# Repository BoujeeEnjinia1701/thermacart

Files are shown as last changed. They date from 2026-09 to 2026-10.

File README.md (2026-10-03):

# ThermaCart

     

**Area:** Shared Components · **TRL:** 3 of 9 (proof of concept on paper) · **Value-engineering target:** $80 USD · **Difficulty:** 2 of 5

A sealed, swappable phase-change thermal cartridge in a few standard temperature ranges (cold chain, comfort and hot holding) that stores heat or cold and drops into coolers, cabinets and heat exchangers.

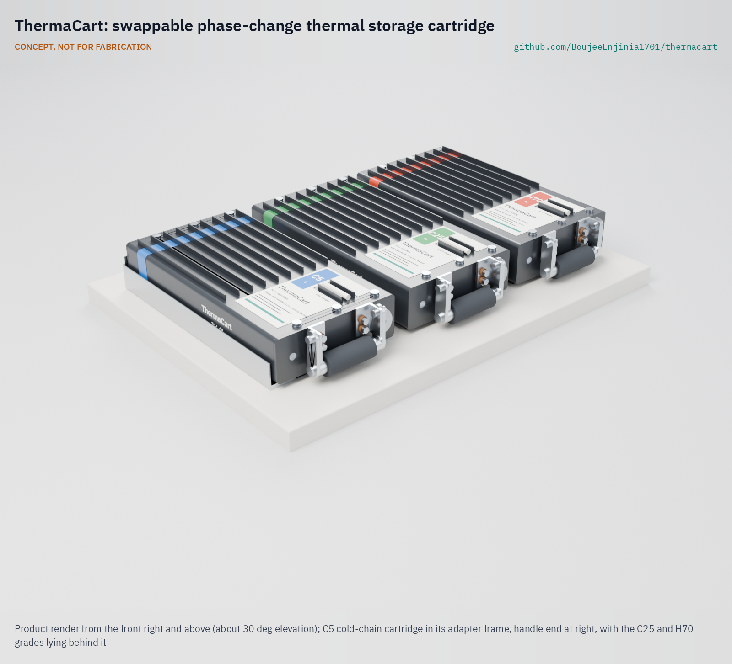
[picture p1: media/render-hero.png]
ThermaCart: swappable phase-change thermal storage cartridge, product render


[Exploded render](media/render-exploded.png) · [Detail render](media/render-detail.png) · [Interactive 3D model](media/viewer.html) · [Concept blueprint (PDF)](media/concept-blueprint.pdf) · [General arrangement (PDF)](cad/drawings/TCT-DWG-001.pdf) · [Prototype build plan](docs/05-build-plan.md) · [Design decisions](docs/06-design-decisions.md) · [Calculations](docs/04-calcs/01-sizing.md) · [Review note](docs/REVIEW.md)

## Concept rationale

A common cartridge format turns thermal storage into a part you choose instead of a subsystem you design, and lets cartridges move between cold boxes, ovens and heat stores. Phase-change material (PCM) holds heat or cold at a nearly constant temperature, so the grade of the fill, not a thermostat, sets the temperature of the box it sits in. Sealing the PCM in a keyed cartridge keeps a messy or combustible material out of users' hands and stops the wrong temperature going into the wrong box.

The design is open and garage-buildable on purpose. The shell is a stock 6 x 2 in aluminium tube with screwed, O-ring-sealed end caps built up from flat plate, so anyone with a drill press and a tap set can make one without milling, and the envelope fits a GN 1/3 gastronorm slot that commercial kitchens already use. Publishing the envelope, key table and fill recipes lets other open projects, including ColdPod and ZeerBox in this portfolio, design around the same cartridge.

## Burning platform

Around 14 % of the world's food, worth about $400 billion a year, is lost between harvest and retail ([FAO and UNEP, 2022](https://www.fao.org/newsroom/detail/FAO-UNEP-agriculture-environment-food-loss-waste-day-2022/en)), much of it spoilage where cooling is missing or unreliable. Cold chains also fail by overcooling: freezing exposure is common in vaccine storage and transport studies, largely because water ice sits at 0 °C or below ([Hanson et al., 2017](https://www.sciencedirect.com/science/article/pii/S0264410X16309471)).

On the hot side, about 2.1 billion people still cook with polluting fuels, and household air pollution caused an estimated 2.9 million deaths in 2021 ([WHO, 2025](https://www.who.int/news-room/fact-sheets/detail/household-air-pollution-and-health)). Demand for cooling is rising fast: UNEP expects installed cooling capacity to triple by 2050, with cooling emissions above 10 % of the global total unless efficiency improves ([UNEP](https://www.unep.org/topics/energy/cooling/about-cooling)). Cheap, portable thermal storage lets heat and cold be made where energy is available and used where it is not.

## Where it could be used

### By industry

| Industry | Use |
| --- | --- |
| Food service and catering | H70 cartridges in insulated GN carriers keep delivered meals hot without gas or mains |
| Fresh produce and dairy logistics | C5 cartridges in coolers on motorbikes, vans and market stalls, recharged overnight in a shared freezer |
| Off-grid refrigeration | A swappable cold store for solar direct-drive fridges and cool boxes instead of built-in ice banks |
| Telecom and electronics enclosures | C25 cartridges buffer daily temperature swings in outdoor cabinets and battery boxes |
| Open hardware and product design | A documented storage block for new cold boxes, warmers and heat stores, so designers size the box, not the storage |

### By country or region

| Country or region | Why it matters there |
| --- | --- |
| India | A 2022 national study put post-harvest losses at 6 to 15 % for fruits and 5 to 12 % for vegetables ([MoFPI, citing NABCONS](https://www.mofpi.gov.in/sites/default/files/_annex_265_au2145_qhinz4.pdf)) |
| Nigeria | About 45 % of food spoils for lack of cold storage, and solar cold rooms such as ColdHubs show the demand for shared cooling ([IFPRI, 2018](https://www.ifpri.org/blog/coldhubs-addressing-crucial-problem-food-loss-nigeria-solar-powered-refrigeration/)) |
| Sub-Saharan Africa (for example Kenya and Tanzania) | About four in five households lack clean cooking ([IEA](https://www.iea.org/reports/universal-access-to-clean-cooking-in-africa/executive-summary)); keeping cooked food hot saves fuel and smoke |
| European Union | About 132 kg of food per person was wasted in 2022, 54 % of it in households ([Eurostat](https://ec.europa.eu/eurostat/web/products-eurostat-news/w/ddn-20240927-2)); kitchens already use GN formats |
| United States | State food codes based on the FDA Food Code require hot food to be held at 57 °C (135 °F) or above ([for example Delaware, § 3-501.16](https://www.law.cornell.edu/regulations/delaware/16-Del-Admin-Code-SS-3-501.16)); caterers and school meal programs need hot holding away from mains |
| United Kingdom | Salt-hydrate heat batteries are already used in homes for hot water ([University of Edinburgh](https://chem.ed.ac.uk/research/research-impact/heat-storage-technology)), showing that sealed PCM storage already sells in high-income markets |

## What sparked the idea

The starting point was the gastronorm pan. In November 1964 the Swiss association for institutional catering (SVG), the Swiss Hotel Association and Swiss makers of commercial kitchen equipment agreed on a kitchen norm built on a basic 530 x 325 mm grid ([SVG, Merkblatt Gastro-Norm](https://svg.ch/merkblatt-gastro-norm/)), and in 1993 the container dimensions were published as the European standard EN 631-1 ([BSI, BS EN 631-1:1993](https://knowledge.bsigroup.com/products/materials-and-articles-in-contact-with-foodstuffs-catering-containers-specification-for-dimensions-of-containers)). Because every pan, oven, trolley and carrier now shares those sizes, kitchens mix equipment from any maker without thinking about it. Thermal storage never got the same treatment: each cold box and food carrier still has its own ice pack or heat pack. ThermaCart asks what a gastronorm for stored heat and cold would look like, so it takes the GN 1/3 footprint as its envelope and adds the missing layer, a small set of keyed temperature grades.

## Problem

Thermal storage is designed from scratch in every cold box, cooker and heat store, and phase-change materials are messy, corrosive or unsafe when handled loose. Water ice is too cold for vaccines and some produce, salt hydrates corrode aluminium, and paraffins burn and can permeate plastics.

Full problem statement: [docs/01-problem.md](docs/01-problem.md)

## Concept

A sealed aluminium cartridge, 323 x 152 x 64 mm, holds 1.10 to 1.18 kg of PCM in one of three grades: C5 (5 °C, cold chain), C25 (25 °C, comfort) and H70 (70 °C, hot holding of cooked food). It fits a GN 1/3 slot, carries by a folding bail, shows its state through a clear melt indicator and locks into an adapter frame whose key accepts only its grade. The shell carries a matte black finish that roughly doubles its heat exchange with the air. The TRL 3 calculations ([TCT-CAL-001](docs/04-calcs/01-sizing.md)) give 65, 61 and 73 Wh of usable storage, 2.9 to 3.0 kg filled and about $83 in parts per cartridge. One H70 cartridge keeps a GN carrier at 63 °C or more for about 13 h. Two C5 cartridges store enough cold for a 25 L cooler for about 9.7 h at 32 °C, but on paper they cannot draw heat out of the cooler air fast enough to hold 2 to 8 °C for more than about 2.4 h; users are told to lay produce directly on the cartridges, which the calculation does not credit. The cold-chain hold time (R10) is not met, and the cost (R16) is over its value-engineering target; see the [review note](docs/REVIEW.md). The design choices were decided by Amish on 2026-09-25 ([TCT-DDR-001](docs/decisions/0001-trl2-review-decisions.md), [TCT-DDR-002](docs/decisions/0002-recommendations-accepted.md)).

Full design precis: [docs/02-concept.md](docs/02-concept.md) · Requirements: [docs/03-requirements.md](docs/03-requirements.md)

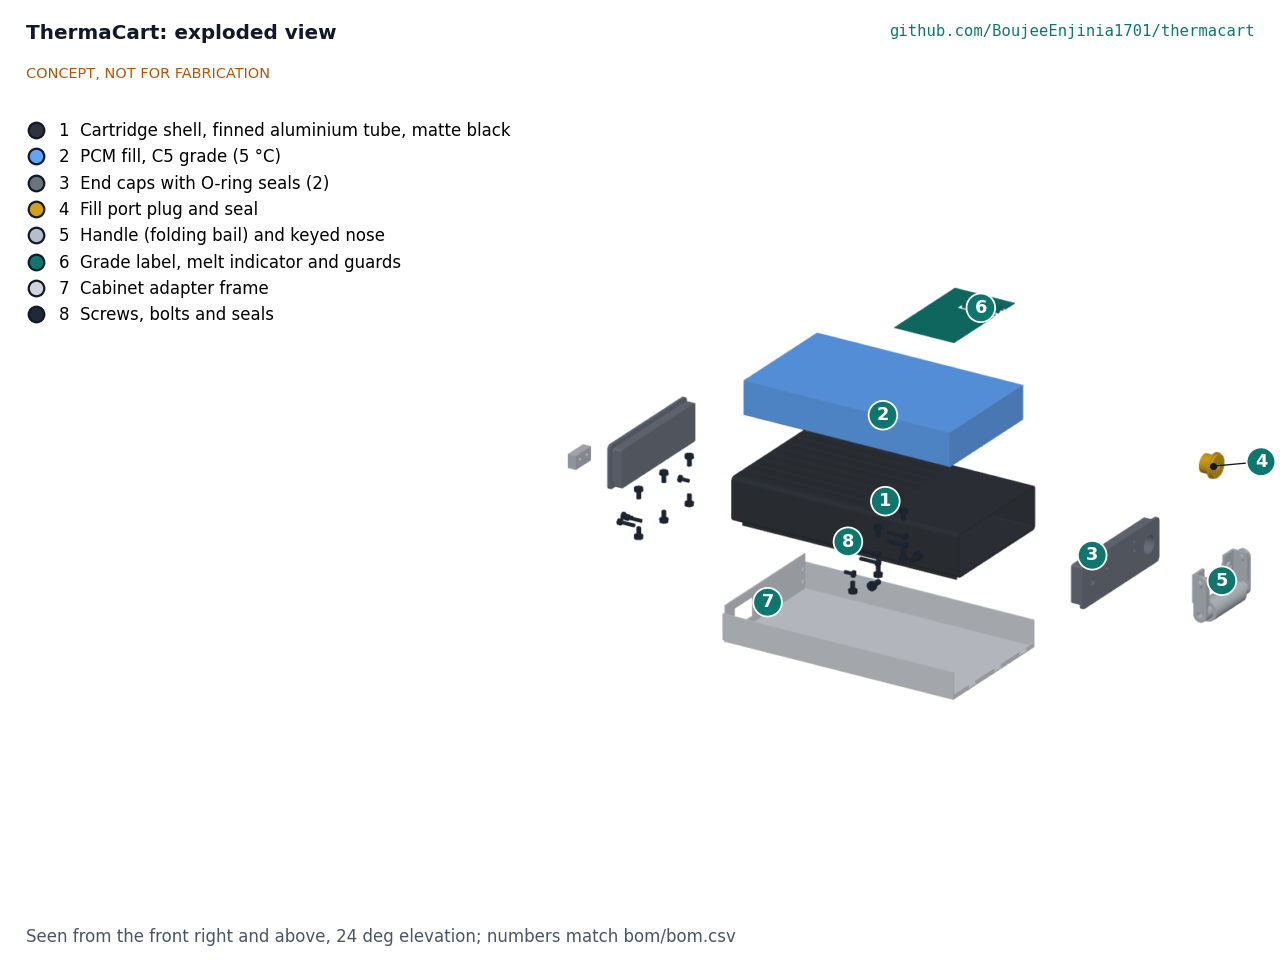
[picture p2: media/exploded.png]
Exploded view


## Key components

1. Cartridge shell: finned 6063 aluminium rectangular tube, matte black finish
2. PCM fill: C5, C25 or H70 paraffin grade (water W0 as an option for produce only)
3. End caps with FKM O-ring seals
4. G 1/2 fill port plug and bonded seal
5. Folding bail on bolted lug angles with a phenolic thermal break, and keyed nose
6. Grade label and melt indicator (a clear tube of the same PCM)
7. Cabinet adapter frame with keyed stop
8. Sealed cap screws, bolts and consumables

The priced bill of materials is in [bom/bom.csv](bom/bom.csv): about $82.50 per cartridge and $17.50 per frame (indicative). Value-engineering target: USD 80. Estimated cost of the constructable design: USD 100 (USD 20 over the target), for the first C5 cartridge and frame; supplier quotes wait with TRL 4. The parametric model is [cad/src/model.py](cad/src/model.py), with STEP and STL exports in `cad/step/` and `cad/stl/`.

## Building the prototype

The design is constructable: every part can be sawn, drilled, tapped, bent or bought, and every part is fixed to the next ([TCT-DDR-003](docs/decisions/0003-design-for-construction.md)). The [prototype build plan](docs/05-build-plan.md) (TCT-BLD-001, plan, not yet built) shows how to make each component and fit it to the next, in 10 making sketches, 10 joint close-ups and 12 assembly steps drawn from the model. The tube, fins and cap plates are cut from stock aluminium and bonded with epoxy, the bail is bolted to the cap through phenolic washers, and the frame is bent on a hand brake and riveted; nothing needs milling or welding. Decisions still open are in the [design decisions register](docs/06-design-decisions.md).

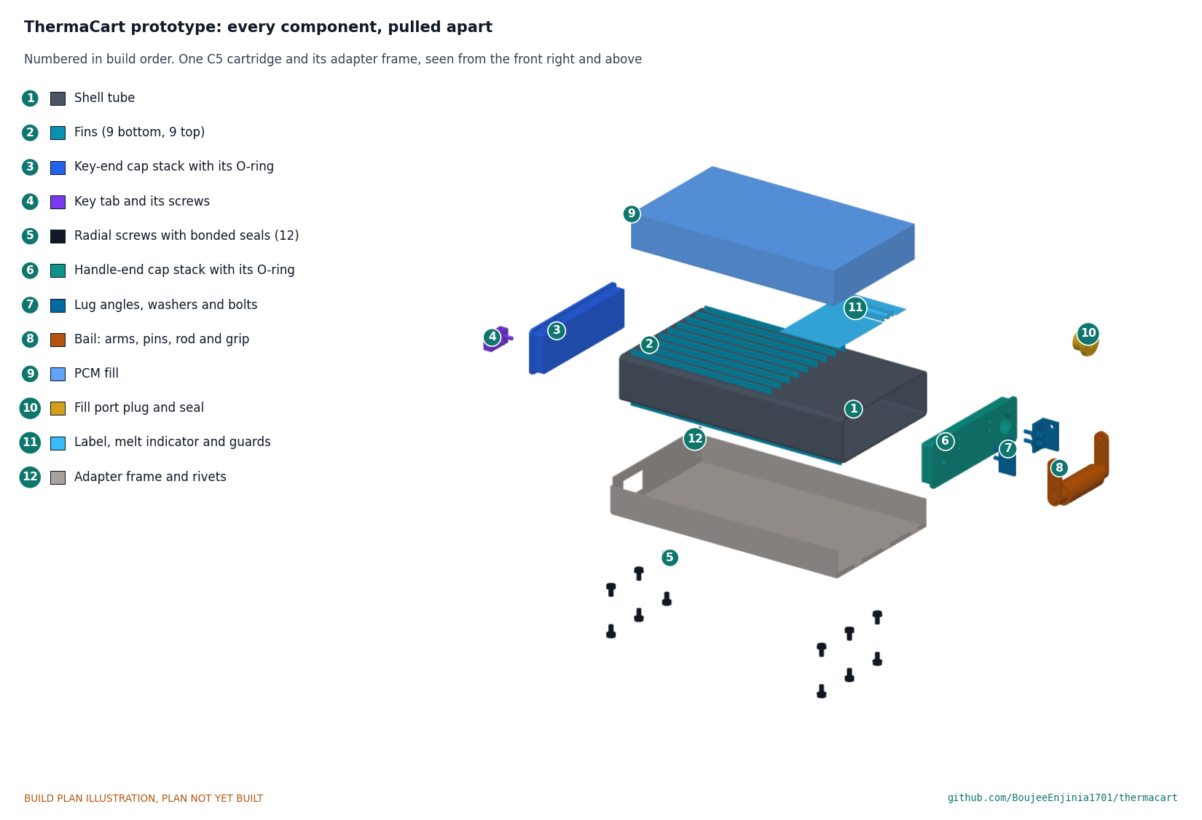
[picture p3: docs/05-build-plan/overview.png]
ThermaCart prototype, every component pulled apart and numbered in build order


## Safety

> Paraffin fills are combustible: never charge a cartridge on an open flame, set an oven to 85 °C and never let an H70 cartridge exceed 90 °C, and keep cartridges away from fire. Keep C5 below 45 °C and C25 below 65 °C. H70 cartridges reach 70 to 85 °C and can burn skin; carry them only by the bail, prefer pad charging, and after an oven use oven gloves or wait 12 min, as the label says. Fill hot to the specified level and never seal a partly filled cartridge. C5 cartridges come out of a freezer below 0 °C; ThermaCart is not qualified for vaccines or medicines. Deburr all cut aluminium.

## Repository layout

| Folder | Contents |
| --- | --- |
| `docs/` | Problem, concept, requirements, calculations and design decisions |
| `cad/src/` | build123d Python source, the source of truth for all geometry |
| `cad/step/`, `cad/stl/` | Exported models for FreeCAD, other CAD tools and printing |
| `cad/drawings/` | 2D sketches and dimensioned drawings |
| `bom/` | Bill of materials |
| `electronics/` | KiCad schematics and PCB layouts |
| `firmware/` | Microcontroller code |
| `media/` | Renders, perspectives and photos |
| `build-log/` | Dated prototyping notes |

## Documentation

Controlled documents follow the portfolio [documentation standard](.kit/STANDARDS.md). Each carries a document ID (TCT-PRC-001 for the precis), a version and a revision history. Branded PDFs are built with `python .kit/render.py` and attached to GitHub Releases when a document is tagged, for example `TCT-PRC-001/v1.0`.

## Credits

Designed by Amish Chadha. See [CONTRIBUTORS.md](CONTRIBUTORS.md) for roles. To cite this design, use [CITATION.cff](CITATION.cff) (GitHub shows it as "Cite this repository").

AI assistance (Claude) was used to accelerate concept renders, prototype documentation and first-pass sizing calculations. Design direction and all decisions are Amish Chadha's, recorded in this repository's decision records (`docs/decisions/`).

## Licenses

- **Hardware** (CAD, drawings, BOM, electronics): [CERN-OHL-S v2](LICENSE)
- **Software** (firmware, scripts, notebooks): [MIT](LICENSE-SOFTWARE)

A project of the [Design Molecule](https://designmolecule.com) lab.

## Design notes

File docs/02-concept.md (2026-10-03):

---
doc_id: TCT-PRC-001
title: ThermaCart design precis
project: ThermaCart
doc_type: Design precis
version: "0.7"
status: Draft
date: '2026-10-02'
author: Amish Chadha
license: CERN-OHL-S-2.0
revisions:
- version: "0.1"
  date: '2026-09-25'
  author: Amish Chadha
  change: Initial scaffold
- version: "0.2"
  date: '2026-09-25'
  author: Amish Chadha
  change: Populate to TRL 2 (architecture, grades, first-order numbers, safety, media)
- version: "0.3"
  date: '2026-09-25'
  author: Amish Chadha
  change: TRL 3 update from TCT-CAL-001 and TCT-DDR-001 (choices adopted for TRL 3 work, folding bail, cap stack, stock fin bar, verified PCM data, numbers, safety limits)
- version: "0.4"
  date: '2026-09-25'
  author: Amish Chadha
  change: Recommendations accepted by Amish (DDR-002)
- version: "0.5"
  date: '2026-10-01'
  author: Amish Chadha
  change: Constructable design (TCT-DDR-003) and prototype build plan (TCT-BLD-001); budget treated as a value-engineering target
- version: "0.6"
  date: '2026-10-02'
  author: Amish Chadha
  change: "Decisions of 2026-10-02: C5 conditioning step on the label, first candidate host partner, no ColdPod or ZeerBox dependency, low lip for wrong grades"
- version: "0.7"
  date: '2026-10-02'
  author: Amish Chadha
  change: "Approved decisions carried into the design: frame lip and raised grip modelled; cost updated for the grade band, side marking and frame decal"
---

# ThermaCart design precis

## Summary

ThermaCart is a sealed aluminium cartridge, 323 x 152 x 64 mm, that holds 1.10 to 1.18 kg of phase-change material (PCM) in one of three standard grades: C5 (melts at 5 °C, cold chain), C25 (25 °C, comfort) and H70 (70 °C, hot holding). It fits a GN 1/3 gastronorm slot, carries by a folding bail, shows its state through a clear melt indicator and locks into an adapter frame whose key accepts only the right grade. The shell, fins and caps carry a matte black finish that improves heat exchange with the air. The TRL 3 calculations (TCT-CAL-001 v0.5) give 65, 61 and 73 Wh of usable storage per cartridge, 2.9 to 3.0 kg filled and about $83 in parts. One requirement is not met on paper: the cold-chain hold time (R10, 2.4 h instead of 8 h, limited by heat transfer from the cooler air); the cost (R16) is over its value-engineering target. The design is constructable: every part can be cut, drilled, bent or bought and is fixed to the next (TCT-DDR-003, 2026-10-01), and the prototype build plan TCT-BLD-001 shows how to make it. The design choices below were decided by Amish on 2026-09-25 (TCT-DDR-001 and TCT-DDR-002).

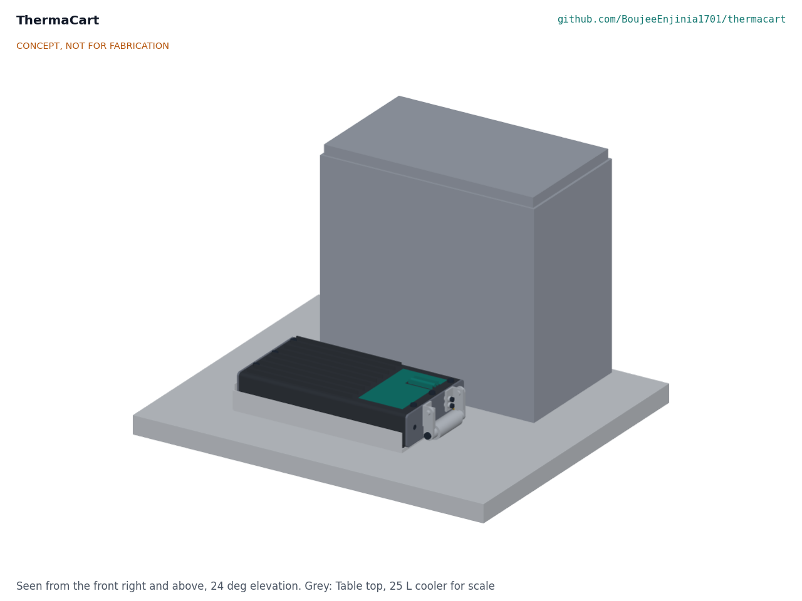
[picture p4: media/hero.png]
ThermaCart hero render


*Figure 1. A TC-L cartridge (C5 grade, matte black finish) in its adapter frame on a table, with a 25 L cooler for scale.*

## How it works

1. **Charge.** The cartridge is put where the right temperature already exists: a freezer for C5, a refrigerator or freezer for C25, and for H70 preferably a thermostatic heating pad, or an oven set to 85 °C (never above 90 °C). The PCM freezes (C5, C25) or melts (H70) and stores latent heat at a nearly constant temperature.
2. **Carry and swap.** The melt indicator shows the state. The owner lifts the bail, carries the cartridge to a cooler, food carrier, cabinet or heat exchanger and slides it nose first into an adapter frame.
3. **Hold.** The host box leaks heat in (cold grades) or out (H70). The PCM absorbs or releases it while staying near its melt point, so the box contents stay near that temperature for as long as the cartridge can move heat to or from them. In a produce cooler, the produce is laid directly on the cartridges, as with ice packs, so heat passes by contact as well as through the air (TCT-DDR-002, O5).
4. **Return.** The discharged cartridge goes back to the charging point. Nothing is consumed; the fill is sealed for life.

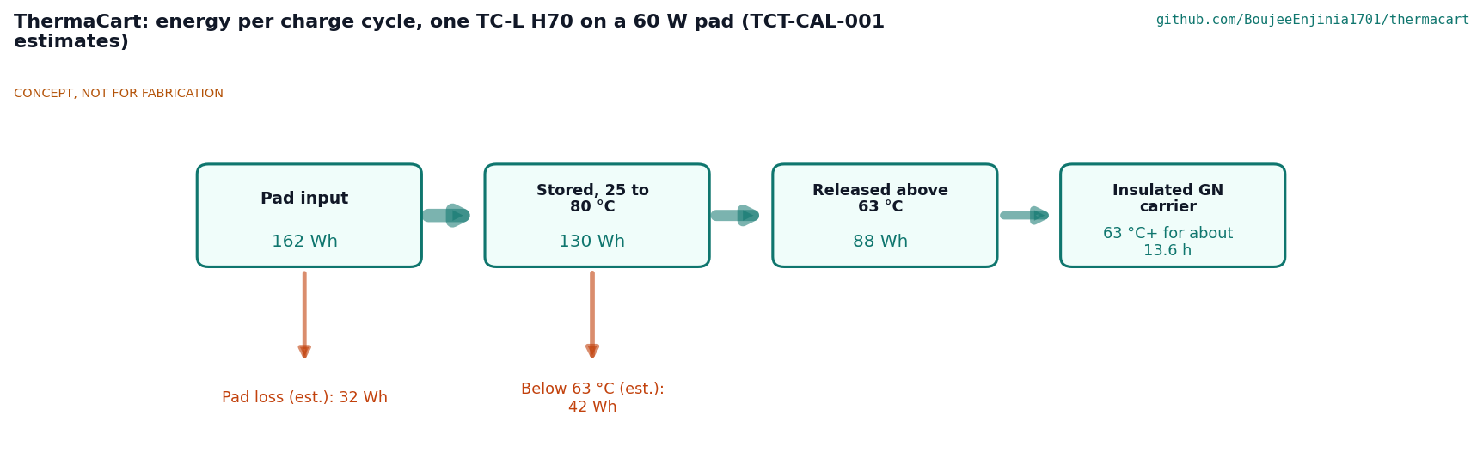
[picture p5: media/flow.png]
Energy flow for one H70 cartridge


*Figure 2. Energy per charge cycle for one H70 cartridge charged on a 60 W pad and used for hot holding (TCT-CAL-001, E4; estimates): 162 Wh in, 130 Wh stored between 25 and 80 °C, 88 Wh released above 63 °C and 42 Wh below it.*

## Standard grades

Table 1. Grades (decided by Amish, 2026-09-25)

| Grade | Melt range | Fill (class) | Filled at | Usable storage per TC-L (TCT-CAL-001) | Typical hosts | Colour and key (Y of key centre) |
| --- | --- | --- | --- | --- | --- | --- |
| C5 | 5 to 6 °C | Organic paraffin, Rubitherm RT 5 HC class | 45 °C | 65.4 Wh (1.104 kg) | Produce and dairy coolers; a ColdPod-type box after qualification | Blue, -43 mm |
| C25 | 22 to 26 °C (band 22 to 27 °C, TCT-DDR-002 O9) | Organic paraffin, RT 25 HC class | 65 °C | 60.5 Wh (1.119 kg) | Electronics and battery cabinets, comfort cooling | Green, 0 mm |
| H70 | 69 to 71 °C | Organic paraffin, RT 70 HC class | 90 °C | 72.9 Wh (1.180 kg) | Insulated GN food carriers, keep-warm boxes | Red, +43 mm |
| W0 (option) | 0 °C | Water with a nucleating agent | Not yet sized | Not yet calculated | Produce only; never for vaccines or medicines | White, -61 mm |

Melt ranges, densities and maximum operating temperatures are from the Rubitherm datasheets ([RT 5 HC](https://www.rubitherm.eu/media/products/datasheets/Techdata_-RT5HC_EN_23072026.PDF), [RT 25 HC](https://www.rubitherm.eu/media/products/datasheets/Techdata_-RT25HC_EN_21012026.PDF), [RT 70 HC](https://www.rubitherm.eu/media/products/datasheets/Techdata_-RT70HC_EN_21012026.PDF)). Each grade is filled at its maximum operating temperature (45, 65 and 90 °C), so the cartridge is never more pressurized in service than when it was sealed. Paraffins are used because they are chemically stable, non-corrosive to aluminium and cycle well ([PATH PCM study](https://media.path.org/documents/DT_pcm_summary_rpt1.pdf)). Salt hydrates would store more per litre but supercool, separate and corrode aluminium ([corrosion study](https://www.researchgate.net/publication/229021530_Corrosive_effects_of_salt_hydrate_phase_change_materials_used_with_aluminium_and_copper)), so they are left for a later lined variant.

## Main components

Table 2. Main components. Numbers match the exploded view (Figure 3) and `bom/bom.csv`.

| # | Component | Choice for TRL 3 | Notes |
| --- | --- | --- | --- |
| 1 | Cartridge shell | 6063-T52 rectangular tube, 152.4 x 50.8 x 3.175 mm (6 x 2 x 1/8 in), 280 mm long, with nine 6.35 x 1.59 mm (1/4 x 1/16 in) fin bars bonded on edge on each broad face; outer surfaces etch-primed and painted matte black with high-temperature paint | Stock sections, no welding; fins add 44 % to the tube's outer area; the finish raises emissivity from about 0.1 to 0.9 (TCT-DDR-002, O8) |
| 2 | PCM fill | 1.10 to 1.18 kg of the grade's PCM, filled as liquid to 90 % of the 1.655 L inner volume | See Table 1 and Safety |
| 3 | End caps (2) | Stack of 3.175 mm flange, 3 mm gland spacer and 9.525 mm plug in 6061 plate, bonded face to face and screwed; spliced FKM 2.5 mm cord O-ring in the corner gland; six radial M5 button-head screws on bonded seals through the tube wall into the plug | Cut and filed, no milling; FKM (or NBR) resists paraffin, EPDM does not |
| 4 | Fill port plug | G 1/2 anodised aluminium plug with a bonded FKM seal in the handle-end cap, clear of the O-ring and the bail | Fill, drain and recycling |
| 5 | Handle and keyed nose | Folding bail (16 mm rod, silicone grip, two 16 x 4 mm arms on 5 mm pins) on two 20 x 20 x 3 mm lug angles bolted to the cap through 3 mm phenolic thermal-break washers, stowed against the end face; key tab screwed to the nose at the grade position | 39 mm finger gap when raised; stowed grip clear of the frame lip; key positions in Table 1 |
| 6 | Grade label and melt indicator | Colour-coded polyester label; a clear polycarbonate tube holding the same PCM, bonded on the top between two guards; H70 label carries the oven handling rule | Paraffin is opaque white when solid and clear when liquid |
| 7 | Cabinet adapter frame | Bent 1.5 mm 5052 aluminium sheet, 294 x 160 mm, with side walls riveted to a keyed end stop; the key passes through the stop's slot when seated | One per host slot; host designs copy its key slot |
| 8 | Hardware | Twelve M5 button-head screws with bonded seals, nine M4 screws and bolts, two M6 rod screws (A2), epoxy rated 120 °C or more, thread sealant | Per cartridge |

Exploded view with BOM numbers

*Figure 3. Exploded view. 1 shell, 2 PCM fill, 3 end caps, 4 fill port plug, 5 handle and keyed nose, 6 label and indicator, 7 adapter frame, 8 cap screws.*

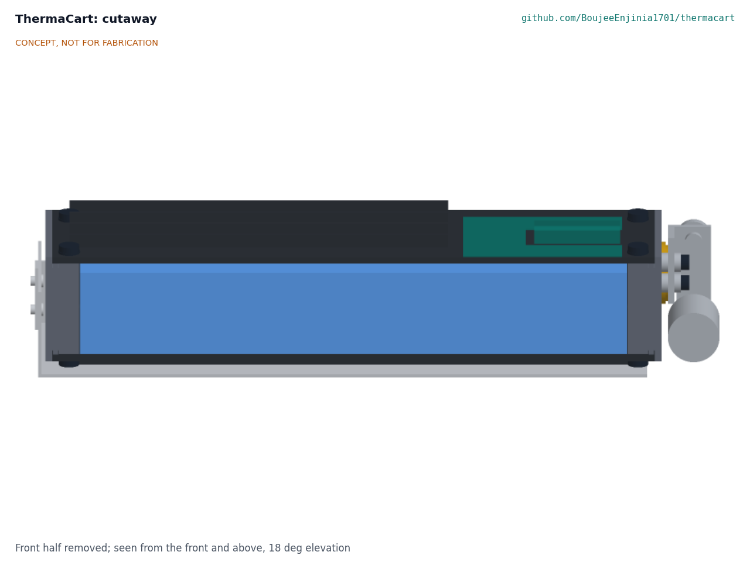
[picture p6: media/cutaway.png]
Cutaway


*Figure 4. Section along the cartridge. The PCM (blue) fills 90 % of the inner height when liquid; the rest is ullage. The cap stacks, fins and label band are visible. The general arrangement is drawing TCT-DWG-001.*

## Key numbers

All values are from TCT-CAL-001 v0.2 (dark finish as the design case) and the parametric model `cad/src/model.py`.

Table 3. Key numbers

| Quantity | Value | Requirement |
| --- | --- | --- |
| Overall size | 323.4 x 152.4 x 63.5 mm, bail stowed | R2 met (GN 1/3: 325 x 176 mm, 65 mm) |
| Inner volume | 1.655 L (146.05 x 44.45 x 254.9 mm) | |
| PCM mass | C5 1.104 kg, C25 1.119 kg, H70 1.180 kg | |
| Usable storage within ±3 K | C5 65.4 Wh, C25 60.5 Wh, H70 72.9 Wh | R3 met (C25 thin) |
| Empty cartridge | 1.80 kg | |
| Filled mass | 2.90 to 2.98 kg | R4 met (thin) |
| PCM fraction | 38.1 to 39.6 % | R5 met (thin; target 38 % for the stock tube) |
| Pressure | 0.00 bar gauge at the fill temperature, -0.68 bar when frozen, +0.29 bar at 20 K over the limit; wall stress 56 MPa against 73 MPa allowable | R8 met |
| Cold hold, two C5 in a 25 L cooler at 32 °C | 2.4 h (1.9 h bare); stored energy alone would last 9.7 h; produce contact not credited | R10 **not met** |
| Hot hold, one H70 in a GN carrier at 25 °C | 13.6 h at 63 °C or more (7.2 h bare) | R11 met |
| Recharge | C5 in a freezer 4.2 h; C25 in a refrigerator 4.6 h; H70 in an 85 °C oven 5.3 h, on a 60 W pad 2.7 to 10.3 h | R12 at risk (pad) |
| Bail temperature, H70 | 39.2 °C on its thermal break; 85 °C for about 10 min after an oven | R14 met with the label rule |
| Parts cost | About $82.50 per cartridge, $17.50 per frame (indicative) | R16 over its value-engineering target by $32.50 per cartridge; one cartridge and one frame $100 against the $80 value-engineering target |

## Key design choices (decided by Amish, 2026-09-25)

Each choice below was decided by Amish on 2026-09-25, going with the recommendation (TCT-DDR-001, items D1 to D8 and T1 to T4, and TCT-DDR-002, items O4 to O9).

1. **Envelope: GN 1/3 footprint from a stock tube (D1).** A 6 x 2 in stock aluminium tube cut to fit a GN 1/3 slot. The WHO PQS 0.6 L pack envelope, 190 x 120 x 34 mm ([WHO PQS E005](https://extranet.who.int/prequal/key-resources/documents/pqs-performance-specification-e005ip012-water-packs-use-icepacks-cool-packs)), is kept as a later small size (TC-S), and a custom finned extrusion only if volumes justify a die.
2. **Three paraffin grades, water as an option, C5 first (D2).** See Table 1.
3. **Mechanical grade keying and a passive indicator (D4).** A nose tab whose position depends on the grade and a matching slot in each frame, so a frozen water or hot H70 cartridge cannot be put into a cold-chain box; the key table is published as part of the open standard. A clear indicator holding the same PCM shows solid or liquid without electronics.
4. **The 2 mm wall is not used (D5).** It adds 3.5 % volume and would yield under the vacuum of a frozen cartridge. C5 meets R3 on the 3.175 mm tube.
5. **Fill hot, seal for life (D8).** Filling as liquid at the grade's maximum operating temperature fixes the largest PCM volume at sealing, so the cartridge only sees vacuum below that temperature and a small positive pressure if the limit is exceeded.
6. **Aluminium shell for paraffins, no HDPE (D8).** Paraffin can swell and permeate polyethylene ([compatibility study](https://www.researchgate.net/publication/227717836_Compatibility_of_plastic_with_phase_change_materials_PCM)); aluminium is compatible and conducts heat to the fins. A lined or HDPE variant is kept for salt hydrates and water.
7. **Folding bail, cap stack and stock fin bar (T1 to T3).** Refinements that keep the cartridge inside the GN 1/3 envelope, give room for fingers and avoid milling.
8. **Matte black finish (O8).** The shell, fins and caps are etch-primed and painted with a high-temperature paint. It raises the air-side coupling from 0.50 to 1.11 W/K per cartridge and helps R10, R11 and R12 for about $5 and 15 g. The bail stays bare aluminium on its thermal break.
9. **Produce on the cartridges (O5).** User guidance for coolers is to lay produce directly on the C5 cartridges. The contact effect is not credited on paper and waits for a TRL 4 measurement, which is on hold; R10 keeps its 8 h target.
10. **H70 handling rule and pad charging (O7).** The H70 label says: from an oven, use oven gloves or wait 12 min before carrying by the bail. Pad charging is the preferred method.
11. **Requirement changes (O4, O9).** R5 is 38 % for the stock-tube build, with 50 % kept for a later extrusion; the C25 band is 22 to 27 °C.
12. **Cost (O6).** Supplier quotes come first; quotes are a purchasing step and wait with TRL 4, which is on hold. `budget_usd` ($80) is a hypothetical value-engineering target, not a limit (Amish, 2026-10-01).

## Safety

> **Safety:** Paraffin fills are combustible. Never charge an H70 cartridge on an open flame, a gas ring or a hot plate. Set an oven to 85 °C and check it with an oven thermometer; never let an H70 cartridge exceed 90 °C, the maximum operating temperature of RT 70 HC. If a cartridge leaks, stop using it; spilled liquid paraffin is slippery and burns.

> **Safety:** Keep C5 cartridges below 45 °C and C25 cartridges below 65 °C, their fill temperatures and datasheet limits; do not leave them in a closed car in the sun.

> **Safety:** H70 cartridges reach 70 to 85 °C and can burn skin. Carry them only by the bail. Straight out of an oven the bail and its grip are at oven temperature for about 12 min: use oven gloves or wait 12 min. Prefer pad charging. The H70 label carries this rule and a hot-surface warning.

> **Safety:** Do not fill, refill or open a cartridge that is warm or under pressure. Fill only as described in the fill recipe, with 10 % ullage at the grade's fill temperature. A frozen cartridge holds a partial vacuum of about 0.7 bar; its broad faces pull in by about 0.8 mm, which is expected.

> **Safety:** A C5 cartridge charged in a freezer is below 0 °C when it comes out. Condition it until the melt indicator shows the first liquid before using it next to anything that must not freeze; the conditioning time is printed on the C5 label as a required step (decided by Amish, 2026-10-02). ThermaCart is not qualified for vaccines or medicines, and the W0 water grade must never be used with them.

- Aluminium edges and fins are sharp after cutting: deburr all edges.
- Use a high-temperature paint rated well above 90 °C for the dark finish, paint in a ventilated space, and keep paint off the fill port thread and seat, the O-ring glands, the bores and the indicator.
- A 3 kg cartridge dropped on a foot can injure: keep cartridges low in racks. A drop of a molten cartridge may stress the seals (TCT-CAL-001, C7).

## Open questions after TRL 3

- R10: the dark finish and produce contact are decided; whether contact closes the gap to 8 h needs a measurement at TRL 4, which is on hold.
- R16: $82.50 per cartridge, $32.50 over its $50 value-engineering target; supplier quotes wait with TRL 4. Savings worth trying are listed in the design decisions register (TCT-DEC-001).
- C5 charging (O3, decided by Amish, 2026-10-02): a domestic freezer followed by the conditioning step, about 4.2 h against 31 to 51 h in a refrigerator, with the conditioning time printed on the C5 label as a required step.
- Seal performance over cycles and in a drop (R6), cycle life (R7) and the pad charge time (R12) need tests, which belong to TRL 4 and are on hold.
- First host (O1, decided by Amish, 2026-10-02): a produce cooler user reached through a postharvest extension partner; the first candidate to approach is the UC Davis Postharvest Technology Center, asked to introduce a grower group or market cooler operator that already uses passive or ice-based cooling. Nothing is agreed. Neither ColdPod nor ZeerBox declares ThermaCart as a dependency now (O2).
- Wrong grade (R9, decided by Amish, 2026-10-02): a low lip, 4 mm high, at the frame's open end, with the stowed grip moved up 3.5 mm, so that the frame physically rejects a wrong grade: its key meets the stop 8 mm short and its fins rest on the lip. Designed and checked in the model (TCT-CAL-001, G2 and G3).

Prototype build plan: [TCT-BLD-001](05-build-plan.md). Design decisions register: [TCT-DEC-001](06-design-decisions.md). Concept media: [blueprint sheet](../media/concept-blueprint.pdf), [interactive 3D model](../media/viewer.html). General arrangement: [TCT-DWG-001](../cad/drawings/TCT-DWG-001.pdf).

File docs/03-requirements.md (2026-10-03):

---
doc_id: TCT-REQ-001
title: ThermaCart requirements
project: ThermaCart
doc_type: Requirements
version: "0.7"
status: Draft
date: '2026-10-02'
author: Amish Chadha
license: CERN-OHL-S-2.0
revisions:
- version: "0.1"
  date: '2026-09-25'
  author: Amish Chadha
  change: Initial scaffold
- version: "0.2"
  date: '2026-09-25'
  author: Amish Chadha
  change: First measurable requirements for TRL 2, with status against the concept estimates
- version: "0.3"
  date: '2026-09-25'
  author: Amish Chadha
  change: TRL 3 status from TCT-CAL-001; R12 oven temperature corrected to the RT 70 HC limit; R16 budget scope per TCT-DDR-001 D6
- version: "0.4"
  date: '2026-09-25'
  author: Amish Chadha
  change: Recommendations accepted by Amish (DDR-002)
- version: "0.5"
  date: '2026-10-01'
  author: Amish Chadha
  change: Status from TCT-CAL-001 v0.3 for the constructable design (TCT-DDR-003); R16 reported against the value-engineering target
- version: "0.6"
  date: '2026-10-02'
  author: Amish Chadha
  change: "R9 status note: the low lip decided on 2026-10-02 (TCT-DDR-003 A1 (b)) is still to be designed"
- version: "0.7"
  date: '2026-10-02'
  author: Amish Chadha
  change: "Status from TCT-CAL-001 v0.5: R9 met by design with the frame lip; R14 and R16 figures updated; no status category changed"
---

# ThermaCart requirements

These are the requirements for the TC-L cartridge and its adapter frame. The targets were proposed at TRL 2, and the design choices behind them were decided by Amish on 2026-09-25 (TCT-DDR-001 and TCT-DDR-002). Under TCT-DDR-002 the C25 band of R1 is widened to 22 to 27 °C (O9), R5 is relaxed to 38 % for the stock-tube build with 50 % kept as the target for a later extrusion (O4), and R14 carries a labelled handling rule for H70 cartridges taken from an oven (O7). R10 keeps its 8 h target (O5). The status column comes from TCT-CAL-001 v0.5, which uses the decided dark finish (O8) and the constructable design of TCT-DDR-003. One requirement is **not met** on paper (R10), one is **over its value-engineering target** (R16; `budget_usd` is a hypothetical control target, not a limit), one is **at risk** (R12), three can only be settled by tests (R6, R7 and R17) and twelve are met. No requirement text changed in v0.5 or v0.7.

Table 1. Requirements

| ID | Requirement | Target | Verification (TRL 3 or later) | Status at TRL 3 (TCT-CAL-001) |
| --- | --- | --- | --- | --- |
| R1 | Offer a small set of standard temperature grades | At least three: C5 (melt 4 to 6 °C, cold chain), C25 (22 to 27 °C, comfort; widened from 24 to 27 °C by TCT-DDR-002, O9), H70 (68 to 72 °C, hot holding) | Material datasheets; later DSC test of each fill batch | Met: RT 5 HC 5 to 6 °C, RT 25 HC 22 to 26 °C, RT 70 HC 69 to 71 °C |
| R2 | Common envelope that fits kitchen and cooler formats | Fits a GN 1/3 slot: at most 325 x 176 mm footprint and 65 mm high, handle included | Model and drawing | Met: 323.4 x 152.4 x 63.5 mm with the bail stowed (TCT-DWG-001) |
| R3 | Enough stored energy per cartridge | 60 Wh (216 kJ) or more of usable storage within ±3 K of the melt point | Calculation per grade | Met: C5 65.4 Wh, C25 60.5 Wh (thin margin), H70 72.9 Wh |
| R4 | Carry with one hand | Filled mass 3.0 kg or less | Mass estimate, then weighing | Met, thin margin: 2.90 to 2.98 kg |
| R5 | Efficient use of mass | PCM at least 38 % of filled mass for the stock-tube build; 50 % remains the target for a later custom extrusion (relaxed by TCT-DDR-002, O4) | Mass estimate | Met, thin margin: 38.1 to 39.6 % |
| R6 | Sealed for life | No leak through 1,000 thermal cycles and a 1 m drop onto concrete in any state | Seal design review at TRL 3; cycle and drop tests belong to TRL 4 | Not verifiable at TRL 3; an end-on drop of a molten cartridge could see a surge of up to 5 bar |
| R7 | Long life | 1,000 cycles or more with less than 10 % loss of latent capacity | Literature and supplier data at TRL 3 | Not verifiable at TRL 3; plausible for paraffins |
| R8 | No pressure hazard | Internal gauge pressure 0.5 bar or less at the highest charge temperature; ullage of at least 10 % of the inner volume at that temperature | Calculation | Met: 0.00 bar at the fill temperature, +0.29 bar at 20 K above the limit; wall stress 56 MPa under the cold vacuum |
| R9 | Wrong grade cannot be fitted | Each grade has its own nose key; a frame for one grade rejects the others | Design review of key geometry | Met by design: every key pairing checked, and the frame's low lip (TCT-DEC-001, item 1) holds a wrong grade out, resting on the lip 4 mm high and 8 mm short of seated; checked in the model with the bail stowed and raised (TCT-CAL-001, G2 and G3) |
| R10 | Cold-chain hold time | Two C5 cartridges keep a 25 L cooler (heat leak about 0.5 W/K, estimate) at 2 to 8 °C for 8 h or more at 32 °C ambient | Heat balance calculation | **Not met**: 2.4 h with the decided dark finish (1.9 h bare); the stored energy would last 9.7 h, but air-side heat transfer limits the hold. Produce laid directly on the cartridges (TCT-DDR-002, O5) is not credited and waits for a TRL 4 measurement, which is on hold |
| R11 | Hot-holding time | One H70 cartridge keeps food in an insulated GN carrier (about 0.25 W/K, estimate) at 63 °C or more for 4 h or more at 25 °C ambient | Heat balance calculation | Met: 13.6 h with the dark finish (7.2 h bare) |
| R12 | Recharge with common equipment | Full recharge in 8 h or less: C5 and C25 in a domestic freezer or refrigerator, H70 in an oven set to 85 °C (never above 90 °C) or on a 60 W heating pad | Calculation (Stefan problem plus fin convection) | **At risk**: with the dark finish, C5 freezer 4.2 h, C25 refrigerator 4.6 h, H70 oven 5.3 h; H70 pad 2.7 to 10.3 h |
| R13 | State of charge visible | Charged or melted state readable at a glance without tools | Design review | Met by design (clear melt indicator tube holding the same PCM, TCT-DDR-003) |
| R14 | Safe to handle when charged | Handle touch temperature below the ISO 13732-1 burn threshold for 10 s contact on every grade; for an H70 cartridge taken from an oven, the label states a handling rule (oven gloves, or wait 12 min) and pad charging is the preferred method (TCT-DDR-002, O7) | Calculation of handle temperature; label review | Met with the handling rule: bail on its thermal break (phenolic washers under the lug angles and the bolt heads) settles at 39.2 °C on pad charging; after an oven it is at 85 °C and falls below 55 °C in about 10 min, which the 12 min label rule covers |
| R15 | Materials compatible with each fill | No corrosion, swelling or permeation: aluminium shell with FKM or NBR seals for paraffins; coated shell or polymer liner for salt hydrates | Compatibility review against supplier data | Met by design for paraffin grades (epoxy rated 120 °C or more); open for salt hydrates |
| R16 | Low cost and garage-buildable | $50 or less in parts per cartridge and $20 or less per frame; stock sections, drill press and taps only. The $80 value-engineering target (`budget_usd`, a hypothetical control target) covers one C5 cartridge and one frame (TCT-DDR-001 D6) | Priced BOM | **Over the value-engineering target by $32.50** per cartridge: $82.50 with the dark finish, the parts added for construction and the decided grade band and side marking; frame $17.50, $2.50 under its target; one cartridge and one frame $100, $20 over the $80 target (indicative prices; quotes wait with TRL 4, TCT-DDR-002, O6) |
| R17 | Open and documented | Envelope, key geometry, grade table and fill recipe published under CERN-OHL-S-2.0 | Repository review | Not verifiable at TRL 3; envelope, key and grade tables are published, the fill recipe waits for TRL 4 |
| R18 | Recoverable at end of life | Fill can be drained or melted out through the fill port and the shell reused; fill named on the label | Design review | Met by design |

## Assumptions

- PCM data from the Rubitherm datasheets for RT 5 HC, RT 25 HC and RT 70 HC, taken at the low side of their ±7.5 % tolerance; usable storage is the latent heat plus sensible heat within ±3 K of the melt point (TCT-CAL-001, Table 1).
- Fill of 1.10 to 1.18 kg: 90 % of a 1.655 L inner volume, filled as liquid at each grade's maximum operating temperature (45, 65 and 90 °C).
- Hot-holding threshold of 63 °C follows common food-safety practice (the US FDA Food Code uses 57 °C, 135 °F); the lower value would lengthen the hold time.
- Cooler and carrier heat leaks are estimates for typical polyurethane and EPP boxes and must be replaced with measured values from a partner's real boxes.
- The burn thresholds used for R14 (about 55 °C for bare metal and 70 °C for plastics, 10 s contact) are commonly quoted from ISO 13732-1 and have not been checked against the standard.

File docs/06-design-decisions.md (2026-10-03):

---
doc_id: TCT-DEC-001
title: ThermaCart design decisions register
project: ThermaCart
doc_type: Design decisions register
version: "0.4"
status: Draft
date: '2026-10-02'
author: Amish Chadha
license: CERN-OHL-S-2.0
revisions:
- version: "0.1"
  date: '2026-10-01'
  author: Amish Chadha
  change: Register opened with the open decisions from the review note, the decision records and the build plan work; budget treated as a value-engineering target
- version: "0.2"
  date: '2026-10-02'
  author: Amish Chadha
  change: "Amish approved the recommendations for all nine open decisions on 2026-10-02 (TCT-DDR-003 Table 3 accepted, A1 as option (b)); moved to decisions made"
- version: "0.3"
  date: '2026-10-02'
  author: Amish Chadha
  change: "Design for construction (TCT-DDR-003, Tables 1 and 2) accepted by Amish on 2026-10-02; added to decisions made"
- version: "0.4"
  date: '2026-10-02'
  author: Amish Chadha
  change: "Value engineering updated for the approved follow-ups (USD 100 against the USD 80 target)"
---

# ThermaCart design decisions register

Every design decision still to be made, and every decision made, in one place. Each decision is argued in full in its decision record under `docs/decisions/`; this register is the index Amish works from. The build plan (`docs/05-build-plan.md`) describes the design as it stands and does not list open decisions.

## Open decisions

None. All open decisions were decided on 2026-10-02.

## To confirm when parts are bought

| # | What to confirm | Why it matters | Source |
| --- | --- | --- | --- |
| 1 | The tube's outside and inside corner radii (3/16 and 1/16 in assumed) and its actual bore at both ends | The spacer and plug are cut to the bore and their corners follow the inside radius; the O-ring squeeze depends on it | TCT-DDR-003, P2, P11; REVIEW.md 2026-09-26, item 5 |
| 2 | FKM O-ring cord 2.5 mm is stocked, and the splicing method (cyanoacrylate splice or a vulcanised ring) for a 361 mm loop | The gland is sized for 2.5 mm cord | TCT-DDR-003, P2 |
| 3 | M5 FKM bonded sealing washers fit the button-head screws' heads | They seal the radial screw holes | TCT-DDR-003, P3 |
| 4 | A G 1/2 anodised aluminium plug with collar and a matching FKM bonded seal | The fill port seal and the R5 mass both assume it | TCT-DDR-003, P1 |
| 5 | The structural epoxy is rated to 120 °C or more and is listed as resistant to paraffins | It bonds the fins, the cap stacks and the indicator, and seals the stack joints | TCT-PRC-001; TCT-DDR-003, P4 |
| 6 | The clear polycarbonate tube grade is rated above 90 °C and stays clear with the H70 paraffin | The H70 indicator sits on a cartridge at up to 90 °C | TCT-DDR-003, P9 |
| 7 | The high-temperature paint is rated well above 90 °C, and its curing temperature | The finish (O8); some paints need an oven cure that must not reach a filled cartridge | TCT-DDR-002, O8 |
| 8 | Phenolic (paper or cotton laminate) sheet 3 mm for the washers | The thermal break is sized on phenolic's conductivity | TCT-CAL-001, F1 |
| 9 | Supplier quotes for every BOM line | All prices are indicative | TCT-DDR-002, O6 |

## Value engineering

Value-engineering target: USD 80. Estimated cost of the constructable design: USD 100 (USD 20 over the target). The target covers one C5 cartridge and one adapter frame (a hypothetical control target, not a limit; Amish, 2026-10-01): the cartridge is USD 82.50 against its USD 50 target in R16, and the frame USD 17.50 against its USD 20 target. Main cost drivers and savings worth trying:

- The largest lines are the shell (tube, fin bar, paint and grade band, USD 30.50), the two cap stacks (USD 14), the frame (USD 17.50), the PCM (USD 11 at USD 10/kg for the first build) and the hardware (USD 11).
- Making the design constructable added USD 5 to the cartridge (bonded seals, bolts, phenolic washers) and USD 1 to the frame (rivets), less USD 1 for the smaller fill plug. The decisions of 2026-10-02 added USD 1.50 for the masked grade band, USD 1 for the painted side marking and USD 0.50 for the frame decal; the lip is folded from the same blank and adds no cost.
- Savings worth trying: buy tube, plate and fin bar for a batch of cartridges (offcuts and cut-to-length charges dominate a one-off); stainless hardware from a bulk supplier rather than a hardware store; paint several cartridges from one set of aerosol cans; a frame without side walls where the host already guides the cartridge; quotes for PCM in 10 kg lots. Dropping the fins (about USD 8) would cost hold and charge time (R10, R12) and is not recommended.

## Decisions made

| Date | Decision | Decided by | Record |
| --- | --- | --- | --- |
| 2026-09-25 | D1 to D8: GN 1/3 envelope from a stock tube; C5, C25 and H70 paraffins with W0 as an option, C5 first; pitch "cold chain, comfort and hot holding"; grade keying and a passive indicator; 2 mm wall not used; one C5 cartridge and one frame for the prototype; produce cooler as first host type; fill hot and seal for life in aluminium | Amish: "i accept all your recommendations, go with them across all repos." | TCT-DDR-001, TCT-DDR-002 |
| 2026-09-25 | T1 to T4: folding bail on a thermal break, cap stack from plate, stock fin bar, 85 °C oven limit | Amish, same instruction | TCT-DDR-001, TCT-DDR-002 |
| 2026-09-25 | O4 to O9: R5 38 % for the stock tube; dark finish and produce on the cartridges for R10; quotes before any cost change; H70 oven handling rule; matte black finish; C25 band 22 to 27 °C | Amish, same instruction | TCT-DDR-002 |
| 2026-09-30 | Make the design physically buildable while drawing the build plan: changes P1 to P11 (fill port, O-ring gland, sealed radial screws, bonded cap stack, bolted lug angles and bail, key tab fixing, frame stop, frame corners, melt indicator, fin bond, tube radii), made under this instruction; Table 3 and then Tables 1 and 2 accepted on 2026-10-02 (below) | Amish: "If you are realising that the design cannot be built as per concept - fix the design assumptions to match and be physically feasible as you draw the illustrations." | TCT-DDR-003 |
| 2026-09-30 | Outstanding decisions are kept in this register, not in the build plan | Amish: "don't log outstanding decisions in this build plan - that is not the place for it." | This register |
| 2026-10-01 | `budget_usd` is a hypothetical value-engineering target, not a spending limit; cost requirements are reported against it | Amish: "the budgets are a hypothethical control target to ensure we are thinking along a value engineering lens." | TCT-CAL-001 v0.3, section H |
| 2026-10-02 | Wrong grade (R9): option (b). A low lip at the frame's open end is designed on paper now, with the stowed grip moved up to suit, so the frame physically rejects a wrong grade instead of leaving it 12 mm proud; fall back to (a) only if the TRL 4 check shows that no target host's lid can close on a proud cartridge | Amish: "i approve your recommendations for all 555 open decisions." | TCT-DDR-003, A1 |
| 2026-10-02 | W0 key: when W0 is sized, its key tab is fixed with screws 4 mm each side of its centre and that frame's corner tab is shortened; the published key table is unchanged | Amish: "i approve your recommendations for all 555 open decisions." | TCT-DDR-003, A2 |
| 2026-10-02 | R5 margin of 0.1 percentage point accepted; a filled prototype is weighed at TRL 4, and if it misses, the tubular bail rod is the first saving | Amish: "i approve your recommendations for all 555 open decisions." | TCT-DDR-003, A3 |
| 2026-10-02 | First host: a produce cooler user reached through a postharvest extension partner. First candidate to approach: the UC Davis Postharvest Technology Center, asked to introduce a grower group or market cooler operator that already uses passive or ice-based cooling | Amish: "i approve your recommendations for all 555 open decisions." | TCT-DDR-001, O1 |
| 2026-10-02 | Neither ColdPod nor ZeerBox declares ThermaCart as a dependency now; neither has a GN 1/3 slot, and the first host is the produce cooler of item 4 | Amish: "i approve your recommendations for all 555 open decisions." | TCT-DDR-001, O2 |
| 2026-10-02 | C5 is charged in a domestic freezer followed by the conditioning step (about 4.2 h), and the conditioning time is printed on the C5 label as a required step | Amish: "i approve your recommendations for all 555 open decisions." | TCT-DDR-001, O3 |
| 2026-10-02 | Grade colour band: an 18 mm painted band round the nose end, a masking step in BOM line 1 | Amish: "i approve your recommendations for all 555 open decisions." | REVIEW.md, 2026-09-26, item 1 |
| 2026-10-02 | Painted side marking "ThermaCart, TC-L C5" adopted as part of the label set (BOM line 6) | Amish: "i approve your recommendations for all 555 open decisions." | REVIEW.md, 2026-09-26, item 2 |
| 2026-10-02 | "C5 ONLY" frame decal adopted; rubber feet are left to each host | Amish: "i approve your recommendations for all 555 open decisions." | REVIEW.md, 2026-09-26, item 3 |
| 2026-10-02 | Design for construction accepted: the changes in Tables 1 and 2 (P1 to P11 and their knock-on changes), as made | Amish: "APPROVED: Design-for-construction changes in 10 repos (CityTwin, CoolShade, PalletPilot, Heliolite, PotholeLog, EarthPress, ReadyKit, CellCheck, CargoMule and ThermaCart)" | [TCT-DDR-003](decisions/0003-design-for-construction.md), Tables 1 and 2 |

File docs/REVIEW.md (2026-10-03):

# Review note: ThermaCart

## Session 2026-10-02: Approved follow-ups carried out

Amish approved on 2026-10-02 that the follow-up actions from the open-decision sign-off be carried out ("APPROVED CHANGES, COMPLETE THESE") and that the render scenes be prepared for new photoreal renders. trl stays 3; no build or test work was done. 10 of 12 follow-ups done.

### Follow-ups

1. Decision 1 (model): done. `cad/src/model.py` has a 4 mm lip folded up at the frame's open end, its inside face 3 mm beyond the seated bottom fins, with three 14 mm notches for the bottom radial screw heads. The stowed grip is 3.5 mm higher (pivot 47.5 mm up, arms 36 mm between holes); its underside is 1.85 mm above the lip top. New checks: the C5 cartridge seats behind the lip, and C25 and H70 cartridges in a C5 frame meet the stop, rest on the lip and cannot drop to the floor, with the bail stowed and raised. 85 of 85 checks pass. STEP and STL regenerated (frame now 283.2 x 160.4 mm, was 294).
2. Decision 1 (drawings): done. TCT-DWG-001 Rev P5 (lip called out, note added); making sketches TCT-DWG-106 (lug angle), 107 (bail arm), 108 (bail rod) and 110 (frame, with lip, notches and decal) at Rev P2.
3. Decision 1 (build plan pictures): done. Joints 5 and 10, steps 9 to 12 and the overview regenerated; the R9 check in TCT-BLD-001 Table 2 now reads that the others meet the stop 8 mm short and rest on the lip.
4. Decision 1 (calculations): done. TCT-CAL-001 v0.5 section G gains G2 (lip) and G3 (grip clearance); the GN 1/3 envelope is unchanged at 323.4 x 152.4 x 63.5 mm; the bail settles at 36.9 and 39.2 °C (was 36.8 and 39.1); the raised finger gap is 39 mm (was 41).
5. Decision 1 (TRL 4 lid check): not done: TRL 4 work, on hold.
6. Decision 2 (W0 key fixing): not done: applies when W0 is sized; W0 has no fill or sizing yet, and the published key table is unchanged.
7. Decision 6 (BOM, conditioning time on the C5 label): done, row 6.
8. Decision 7 (BOM, grade band): done, row 1 repriced from $29.00 to $30.50 (coloured high-temperature paint and masking tape).
9. Decision 7 (pictures and renders, grade band): done. Build plan step 2 shows the masked 18 mm band; the appearance model paints it from the model's band (`grade_band()`).
10. Decision 8 (BOM, side marking): done, row 6 repriced from $4.00 to $5.00 (stencil and paint).
11. Decision 9 (BOM, frame decal): done, row 7 now $17.50 (lip from the same blank, decal $0.50).
12. Decision 9 (renders, no rubber feet): done. Feet removed from `cad/src/product_model.py`; the "C5 ONLY" decal kept and moved below the stop's top edge.

Counted against the 12 items, 10 are done and 2 are not done (items 5 and 6).

### Correction found

A wrong grade's key meets the stop 8 mm short of seated, not 12 mm as TCT-DDR-003 (P7, A1), the register's item 1 wording and earlier TCT-CAL-001 versions said: the 2 mm gap between the seated nose flange and the stop has to be subtracted from the 10 mm key, not added. The lip was sized for 8 mm. TCT-DDR-003 and the register's decision row are left as recorded; the build plan, calculation note, requirements and precis now give 8 mm.

### Requirement status changes

None changed category. R9 stays "Met by design" but now rests on the modelled lip instead of a 12 mm stand-off; R14 figures 36.9 and 39.2 °C; R16 cartridge $82.50, $32.50 over its $50 target, frame $17.50.

### Value engineering

Value-engineering target: USD 80. Estimated cost of the constructable design: USD 100 (USD 20 over the target). Empty cartridge 1.80 kg (band and marking paint add about 2 g); filled 2.90 to 2.98 kg; PCM fraction 38.1 to 39.6 %. `budget_usd` unchanged.

### Appearance model and render scenes

`cad/src/product_model.py` now builds every solid from `model.build_components()` (the constructable design: lug angles, sealed screws, G 1/2 plug, melt indicator tube and guards in place of the old sight window) and adds the painted band, side marking and label print, with the C5 conditioning time on the label. The bench top was raised to z = 0 now that the feet are gone. The concept-only handle and sight window parameters were removed from `model.py`. Render scenes exported with `.kit/export_views.py` to `/home/claude/renders/thermacart` (hero, exploded, detail; one .npz and .json each plus `thermacart__jobs.json`). Photoreal renders, `card.png` and `social-preview.png` are to be made on Amish's Mac.

### Documents changed

- `cad/src/model.py`, `cad/src/sheets.py`, `cad/src/build_plan_media.py`, `cad/src/concept_media.py`, `cad/src/product_model.py`; STEP and STL; `cad/drawings/TCT-DWG-001` Rev P5, TCT-DWG-106, 107, 108 and 110 Rev P2; `media/` concept set regenerated
- `bom/bom.csv` rows 1, 5, 6 and 7; `bom/bom-notes.md`
- `docs/04-calcs/sizing.py` and TCT-CAL-001 v0.5; TCT-REQ-001 v0.7; TCT-PRC-001 v0.7; TCT-PRB-001 (`docs/01-problem.md`) v0.8; TCT-DEC-001 v0.4 (value engineering); TCT-BLD-001 v0.3; `README.md`
- PDFs regenerated with `python3 .kit/render.py`

### Cross-repo actions

None.

### Recommended next step

Photoreal renders from the exported scenes on Amish's Mac. TRL 4 remains on hold by Amish's instruction.

## Session 2026-10-02: design-for-construction changes accepted

Amish, 2026-10-02: "APPROVED: Design-for-construction changes in 10 repos (CityTwin, CoolShade, PalletPilot, Heliolite, PotholeLog, EarthPress, ReadyKit, CellCheck, CargoMule and ThermaCart)". This accepts the design-for-construction changes in Tables 1 and 2 of TCT-DDR-003 (P1 to P11 and their knock-on changes), which were left open for his review when the open decisions were decided earlier the same day (session below). No other item is decided by it. trl stays 3; no build or test work was done, and the model, BOM quantities and prices, calculations and pictures are unchanged.

### Documents changed

- `docs/decisions/0003-design-for-construction.md` (TCT-DDR-003 v0.3, status Draft): status line now "accepted" with Amish's words.
- `docs/06-design-decisions.md` (TCT-DEC-001 v0.3): Decisions made row added, dated 2026-10-02.
- `docs/05-build-plan.md` (TCT-BLD-001 v0.2): section 2 says TCT-DDR-003 is accepted.
- PDFs regenerated.

### Recommended next step

No change: the follow-up actions of the session below stand. TRL 4 remains on hold by Amish's instruction.

## Session 2026-10-02: open decisions decided by Amish

Amish wrote on 2026-10-02: "i approve your recommendations for all 555 open decisions." Every open decision in this repo's register was decided as recommended and moved to "Decisions made" in `docs/06-design-decisions.md`, dated 2026-10-02.

### Decisions recorded

9 decisions recorded (register items 1 to 9). The register's "Open decisions" section now reads: "None. All open decisions were decided on 2026-10-02."

### Documents changed

- `docs/06-design-decisions.md` v0.2
- `docs/decisions/0003-design-for-construction.md` v0.2
- `docs/decisions/0001-trl2-review-decisions.md` v0.3
- `docs/decisions/0002-recommendations-accepted.md` v0.2
- `docs/03-requirements.md` v0.6
- `docs/04-calcs/01-sizing.md` v0.4
- `docs/02-concept.md` v0.6
- `docs/01-problem.md` v0.7
- `bom/bom-notes.md` (decided label, band and decal items noted; not a controlled document)

PDFs re-rendered with `python3 .kit/render.py`. The CAD model, BOM quantities and prices, and pictures were not changed.

### Follow-up actions to carry approved decisions into the design

1. Decision 1 (model): Design the low lip at the frame's open end, which the bottom fins drop behind only when the key is through the slot, and move the stowed grip up to clear it, in `cad/src/model.py`; add checks that the right grade seats and a wrong grade is held out, with the bail stowed and raised.
2. Decision 1 (drawings): Regenerate the frame and bail making sketches and TCT-DWG-001 with the lip and the moved grip.
3. Decision 1 (build plan pictures and renders): Regenerate the frame and bail pictures of TCT-BLD-001 and change its R9 check ("the others stop 12 mm short") to the lip rejecting a wrong grade.
4. Decision 1 (calculations): Update TCT-CAL-001, section G (grade keying), for the lip, and recheck the bail handle temperature and the GN 1/3 envelope with the grip moved up.
5. Decision 1 (documents): When TRL 4 is opened, write the check that no target host's lid can close on a proud cartridge, which decides any fallback to option (a).
6. Decision 2 (model): When W0 is sized, fix its key tab with screws 4 mm each side of its centre and shorten the W0 frame's corner tab; the published key table stays as it is.
7. Decision 6 (BOM): Add the printed conditioning time to the C5 label in the label set (row 6) of `bom/bom.csv`.
8. Decision 7 (BOM): Add the 18 mm grade band masking step and its paint to row 1 of `bom/bom.csv` and reprice if needed.
9. Decision 7 (build plan pictures and renders): Show the grade band as a masked, painted 18 mm band in the build plan painting step and the renders.
10. Decision 8 (BOM): Add the painted side marking "ThermaCart, TC-L C5" to the label set (row 6) of `bom/bom.csv`.
11. Decision 9 (BOM): Add the "C5 ONLY" decal to the frame (row 7) of `bom/bom.csv`.
12. Decision 9 (build plan pictures and renders): Remove the rubber feet from the appearance model and renders, keeping the frame decal.

### Points found in the review

- R9 is shown as 'Met by design: every pairing checked' in TCT-REQ-001, but TCT-DDR-003 A1 says a wrong-grade cartridge is not rejected, only left 12 mm proud; R9 should read 'at risk' until item 1 is decided.
- Item 5: neither ColdPod (built-in PCM in a vacuum-panel case) nor ZeerBox (walk-in evaporative chamber) has a cartridge slot, so the question as framed has no natural host in either repo.
- Value engineering compares like with like (one C5 cartridge and one frame against USD 80), but the cartridge alone is USD 80 against R16's USD 50, so most of the gap is the cartridge, not the frame.
- REVIEW.md 2026-09-26 items 4 to 7 (sight window build-up, tube corners, pivot pins, cap screws) are not in the register; items 4 and 6 are superseded by TCT-DDR-003 (P9 and the new bail), and 5 is now in 'To confirm when parts are bought'; they can be closed.
- R9 status was not changed to "at risk" (flag 1); its status cell now says that a wrong grade stands 12 mm proud until the low lip decided on 2026-10-02 is designed. Amish may want the status itself changed.
- TCT-DDR-003 Tables 1 and 2 (the changes made for construction) were not an open decision in the register, so only Table 3 was decided in this session. Amish accepted Tables 1 and 2 later on 2026-10-02 (see the session above).
- Item 1 was approved as option (b), the low lip, which differs from the register's earlier recommendation of option (a); the design change is a follow-up, not yet made.

TRL 4 remains on hold by Amish's instruction.

## Session 2026-09-25: /populate to a strong TRL 2

### What was done

- `docs/01-problem.md` (TCT-PRB-001 v0.2): problem, why it matters (cited), users and context, prior work with links (Rubitherm, Pluss, WHO PQS E005 packs, solar direct-drive ice banks, Sunamp, RAL-GZ 896, Gastronorm), known material problems, constraints and out of scope. The file had no co-design checklist to keep.
- `docs/03-requirements.md` (TCT-REQ-001 v0.2): 18 measurable requirements (R1 to R18) with targets, planned verification and a status column against the concept estimates.
- `docs/02-concept.md` (TCT-PRC-001 v0.2): how it works, proposed grades, numbered components, first-order numbers with assumptions, design choices with options, safety section and open questions.
- `cad/src/concept_media.py`: massing model of one TC-L cartridge (C5 grade) in its adapter frame, seven BOM-numbered parts, with a table top and a 25 L cooler as the scale context (the cartridge is a small object, so no 1.75 m figure).
- `media/`: `hero.png`, `concept-blueprint.png`, `.pdf` and `.svg`, `exploded.png` with BOM callouts, `cutaway.png`, `flow.png` (energy per H70 charge cycle, all values labeled as estimates), `model.glb` and `viewer.html`.
- `bom/bom.csv`: eight lines with indicative USD prices, numbered to match the exploded view; `bom/bom-notes.md` updated.
- `README.md`: hero image and links line, expanded Concept rationale, Burning platform (four cited figures), Where it could be used (5 industries, 6 countries or regions with cited facts), What sparked the idea (origin kept, WHO PQS trigger added), and updated Problem, Concept, Key components and Safety.
- `docs/pdf/`: branded PDFs of the three controlled documents.

### Key results (estimates, to be checked at TRL 3)

| Quantity | Estimate | Requirement |
| --- | --- | --- |
| Overall size | 322 x 152 x 61 mm, fits a GN 1/3 slot | R2 met |
| PCM per cartridge | about 1.1 kg in 1.62 L | |
| Usable storage | C5 55 Wh, C25 61 Wh, H70 67 Wh | R3 **not met for C5**; C25 thin margin |
| Filled mass | about 2.6 kg | R4 met |
| PCM mass fraction | about 42 % | R5 **not met** (target 50 %) |
| Cold hold, two C5 in a 25 L cooler at 32 °C | about 8.1 h | R10 **at risk**, no margin |
| Hot hold, one H70 in a GN carrier at 25 °C | about 6 h at 63 °C or more | R11 met |
| Recharge | C5 about 4 to 8 h in a freezer; H70 about 2.5 h on a 60 W pad | R12 at risk for C5 |
| Handle temperature, H70 | bare aluminium handle near 75 °C | R14 **not met**; insulated grip proposed |
| Parts cost | about $49 per cartridge, $15 per frame, $64 for one of each | R16 met, thin margin; within the $80 budget |

Requirements not met or at risk: R3 (C5), R5, R10, R12 (C5) and R14 (H70). R6 (seal and drop) and R7 (cycle life for salt hydrates) are not yet assessed.

### Proposed, awaiting Amish (status updated 2026-09-25)

Items 1 to 7 are decided by Amish, 2026-09-25: go with recommendation (TCT-DDR-001 D1 to D7, TCT-DDR-002). Item 8 had no recommendation and stays proposed, awaiting Amish (O2).

1. **Envelope.** (a) Stock 6 x 2 in aluminium tube sized to a GN 1/3 slot; (b) the WHO PQS 0.6 L pack envelope; (c) a custom finned extrusion. Recommendation: (a) now, (b) later as a small size, (c) only at volume.
2. **Grades.** C5, C25 and H70 in organic paraffin, with water (W0) as a produce-only option and salt hydrates deferred to a lined variant. Recommendation: adopt, and build C5 first (lowest hazard, links to ColdPod).
3. **Reading of "cooking" in the pitch.** The concept treats the cooking range as hot holding of cooked food at 70 °C; true cooking storage above 100 °C is out of scope. Options: (a) keep the pitch wording; (b) reword to "cold chain, comfort and hot holding". Recommendation: (b), a small pitch change that is Amish's to make. `project.yaml` was not changed.
4. **Grade keying and passive sight-window indicator.** Recommendation: adopt both and publish the key table as part of the open standard.
5. **Closing the C5 gaps (R3, R10, R5).** Options: thinner tube wall (3.18 to 2 mm), a taller tube within the 65 mm GN depth, or accept about 55 Wh for C5. Recommendation: evaluate a 2 mm wall at TRL 3.
6. **Budget.** The $80 covers one cartridge and one frame (about $64). A three-grade set with one frame is about $162. Options: (a) keep $80 and build one C5 cartridge; (b) raise to about $165 for all three grades. Recommendation: (a) for now; revisit before any build.
7. **Host and partner for co-design.** A produce trader or market cooler user, a caterer using GN carriers, or ColdPod as the first host. Recommendation: a produce cooler user through a local partner, because R10 is the tightest requirement.
8. **Dependencies.** Whether ColdPod or ZeerBox should adopt ThermaCart. No sibling README in this batch references ThermaCart, and no other repo was changed.

`project.yaml` is unchanged: `pitch` and `problem` are still correct, and budget, TRL, name, slug, area and licenses were not touched. No SwapCell pack is used or proposed.

### Safety concerns

- Paraffin fills are combustible: no charging on flame or above 100 °C; clear labels.
- H70 surfaces at about 75 °C: burn risk; R14 needs an insulated grip.
- Pressure: fill hot with 10 % ullage and never seal a partly molten H70 cartridge; R8 must be confirmed by calculation.
- C5 from a freezer is below 0 °C; not qualified for vaccines or medicines, and W0 must never be used with them.
- Salt hydrates corrode aluminium: not to be used in this shell.
- Sharp cut aluminium edges and a 2.6 kg mass.

### Recommended next step

Review this note and the media, and decide items 1 to 6. If approved, run `/advance-trl3` to calculate storage, hold times, charge times, handle temperature and internal pressure per grade (CAL), build the parametric model with STEP export and the drawing sheet, and price every BOM line.

## Session 2026-09-25: TRL 3

Amish asked for this batch to be taken through the usual process with the instruction "you know the drill, nothing gets past TRL 3". He has not reviewed this repo's TRL 2 items one by one, so every item with a recommendation is adopted as recommended for TRL 3 under that instruction, open for his review, and items without one stay open. TRL 4 is on hold by Amish's instruction.

### What was done

- `docs/decisions/0001-trl2-review-decisions.md` (TCT-DDR-001 v0.1): items D1 to D8 adopted as recommended for TRL 3, open for review; TRL 3 refinements T1 to T4; open items O1 to O9.
- `docs/04-calcs/01-sizing.md` (TCT-CAL-001 v0.1) and `docs/04-calcs/sizing.py`: geometry and mass, storage per grade from the Rubitherm datasheets, pressure and wall stress (including the 2 mm wall of D5), hold times with a two-node heat model, recharge (Stefan model), handle temperature, keying and cost, with a results table for R1 to R18. The script imports the model and reads the BOM and `project.yaml`.
- `cad/src/model.py`: parametric build123d model (tube, fins, cap stacks, O-rings, screws, fill port, folding bail on a thermal break, grade key, label and window, adapter frame). Exports `cad/step/` and `cad/stl/`: `thermacart-assembly`, `tc-l-cartridge`, `end-cap`, `adapter-frame`.
- `cad/src/sheets.py` and `cad/drawings/TCT-DWG-001.svg`, `.pdf`, `.png`: general arrangement at Rev P1, scale 1:2.5, marked "CONCEPT, NOT FOR FABRICATION" and "PRELIMINARY, NOT FOR FABRICATION". The concept blueprint keeps TCT-DWG-010, so DWG-001 was the next free number.
- `bom/bom.csv` and `bom/bom-notes.md`: every line priced (indicative, not quoted) with a supplier type.
- `cad/src/concept_media.py` now builds from the model; all media refreshed (`hero`, `concept-blueprint` `.png`, `.pdf`, `.svg`, `exploded`, `cutaway`, `flow`, `model.glb`, `viewer.html`) and checked by eye. Temporary `media/_views*` folders removed. The kit's cutaway cuts at the mean Y of the parts; the cartridge is centred on the origin, so no shift was needed.
- TCT-PRB-001, TCT-PRC-001 and TCT-REQ-001 revised to v0.3; `README.md` and `project.yaml` updated (pitch reworded under D3; `trl: 3`, `trl_target: 3`, evidence listed). PDFs rebuilt in `docs/pdf/`.

### Requirements (TCT-CAL-001, Table 5)

Counts: 3 not met, 3 at risk, 3 not verifiable at TRL 3, 9 met.

| ID | Status | Value against target |
| --- | --- | --- |
| R5 | **Not met** | PCM 38.3 to 39.9 % of filled mass against 50 %; the solid cap stacks weigh about 0.27 kg each |
| R10 | **Not met** | Two C5 hold a 25 L cooler at 2 to 8 °C for 1.9 h (bare) or 2.4 h (dark finish) at 32 °C against 8 h. The stored energy (131 Wh) would last 9.7 h; the limit is heat transfer from the cooler air (about 0.5 to 1.1 W/K per cartridge). Direct contact with the load is not credited |
| R16 | **Not met** | $71 per cartridge against $50 (frame $16, met); the first C5 build is $87 against the $80 budget |
| R1 | At risk | RT 25 HC melts from 22 °C, below the 24 to 27 °C C25 band; C5 and H70 met |
| R12 | At risk | Freezer, refrigerator (C25) and 85 °C oven all within 8 h; a 60 W pad takes 2.7 to 10.3 h depending on convection in the melt |
| R14 | At risk | H70 bail 42.5 °C on its thermal break, but at 85 °C for about 12 min after an oven |
| R6, R7, R17 | Not verifiable at TRL 3 | Seal, drop (surge up to 5 bar flagged), cycle life and fill recipe need TRL 4 work |
| R2, R3, R4, R8, R11 | Met by calculation | 323.4 x 152.4 x 63.5 mm; C5 65.4, C25 60.5, H70 72.9 Wh; 2.89 to 2.96 kg (thin); 0 bar at fill, +0.29 bar over limit, 56 MPa wall stress; 7.2 h hot hold |
| R9, R13, R15, R18 | Met by design | Keying checked for every pairing; sight window; aluminium, FKM and 120 °C epoxy with paraffins; drain through the fill port |

Changes against TRL 2: C5 now meets R3 (verified datasheet values); R10 moved from at risk to not met; R16 from met to not met; mass rose from about 2.6 to 2.9 kg. The H70 charge limit was 100 °C in the TRL 2 documents; the RT 70 HC datasheet limit is 90 °C, and R12 and the safety text are corrected.

### Decisions recorded (TCT-DDR-001)

Adopted as recommended for TRL 3 under Amish's 2026-09-25 instruction, open for his review. Now decided by Amish, 2026-09-25: go with recommendation (TCT-DDR-002):

- D1 stock 6 x 2 x 1/8 in tube in a GN 1/3 envelope; D2 C5, C25, H70 paraffins, W0 produce-only option, C5 first; D3 pitch reworded to "cold chain, comfort and hot holding" (applied to `project.yaml` and `README.md`); D4 grade keying with a published key table and a sight-window indicator; D5 2 mm wall evaluated and not adopted (it would yield under the cold vacuum and adds only 3.5 % volume); D6 `budget_usd` kept at $80 for one C5 cartridge and one frame (unchanged in `project.yaml`); D7 first host type a produce cooler user through a local partner; D8 fill as liquid at the grade limit and seal for life, aluminium shell, no HDPE.
- TRL 3 refinements within those decisions, now also decided by Amish, 2026-09-25: go with recommendation: T1 folding bail on a thermal break (the fixed handle left about 14 mm for fingers); T2 cap stack from flat plate and a 280 mm tube (no milling); T3 stock 1/4 x 1/16 in fin bar; T4 R12 oven 85 °C, never above 90 °C, and storage limits of 45 °C (C5) and 65 °C (C25).

### Still awaiting Amish (status updated 2026-09-25)

O4 to O9 are now decided by Amish, 2026-09-25: go with recommendation (TCT-DDR-002). O1 to O3 had no recommendation and stay proposed, awaiting Amish.

1. **O1 Named co-design partner and region** for the first produce cooler. No recommendation.
2. **O2 ColdPod or ZeerBox dependency.** No recommendation; neither repo is in this batch.
3. **O3 C5 charging.** Freezer plus conditioning, or refrigerator. No recommendation at TRL 2; CAL shows a refrigerator takes 31 to 51 h, which favours the freezer.
4. **O4 R5.** Options: (a) relax R5 to 38 % for the stock-tube build; (b) lighten the caps (a pocketed plug needs a machine shop and adds cost); (c) keep 50 % for a later extrusion. Recommendation: (a) with (c) as the long-term target.
5. **O5 R10.** Options: (a) dark finish plus guidance to lay produce on the cartridges, then measure at TRL 4; (b) three or four cartridges per cooler; (c) restate R10 for a lower ambient or a shorter day. Recommendation: (a), with R10 kept as the target until a test shows the contact effect.
6. **O6 R16 and budget.** One C5 cartridge and one frame cost $87 against $80 (indicative). Options: (a) drop the fins for the first build (saves about $8, costs coupling in R10 and R12); (b) get quotes first and revisit; (c) raise the budget to about $90. Recommendation: (b); do not raise the budget until quotes are in.
7. **O7 R14.** A handling rule for H70 out of an oven (oven gloves or a 12 min wait) on the label. Recommendation: adopt the rule and prefer pad charging.
8. **O8 Surface finish.** Mill finish or dark paint or anodizing. Recommendation: dark finish; it helps R10, R11 and R12 at small cost.
9. **O9 R1 for C25.** Widen the C25 band to 22 to 27 °C, or seek a paraffin melting within 24 to 27 °C. Recommendation: widen the band; comfort uses do not need a tighter one.

### Consistency with shared components

ThermaCart uses none of the other shared components in this batch (FieldNode, CellGuard, MotionCore, TwinKit, CalRig) and none of them references it; GridBench's review lists it as not applicable. No sibling repo was changed and no conflict was found. No SwapCell pack is used.

### Citations

The Rubitherm product page and the RT 5 HC, RT 25 HC and RT 70 HC datasheets were fetched on 2026-09-25 and their figures are used in TCT-CAL-001; the datasheet links are added to TCT-PRC-001 and TCT-PRB-001. The TRL 2 note listed no unchecked citations. The ISO 13732-1 burn thresholds used for R14 could not be checked (the standard is paywalled and WebSearch is exhausted); they are flagged as assumptions in TCT-CAL-001 and TCT-REQ-001.

### Safety concerns

- H70 charging: the RT 70 HC limit is 90 °C, not 100 °C as the TRL 2 documents said; domestic oven thermostats can overshoot, so an oven thermometer is needed.
- C5 and C25 have datasheet limits of 45 and 65 °C; a cartridge left in a hot car may exceed them.
- Frozen cartridges hold a partial vacuum of about 0.7 bar; walls are within the allowable stress at 3.175 mm but a thinner wall would yield.
- A dropped molten cartridge may see a pressure surge of up to 5 bar at the cap (unverified; R6 test at TRL 4).
- Hot bail and grip for about 12 min after an oven (R14).
- Paraffin is combustible; C5 is below 0 °C out of a freezer; not for vaccines or medicines; W0 never with them; sharp edges; 3 kg mass.

### TRL 4 material

None found in the repo; nothing was added. `build-log/README.md` is the scaffold file and was not touched.

### Recommended next step

Review TCT-DDR-001 and items O1 to O9 above, starting with O5 (R10) and O6 (cost), since they decide whether the C5 cold-chain case is worth building. Before any build, replace the indicative BOM prices with supplier quotes. TRL 4 is on hold by Amish's instruction. For the record only, TRL 4 would need: a built C5 cartridge and frame, a lab test report (TST, `environment: lab`) covering leak-tightness through thermal cycles, the 1 m drop (R6), the cooler hold with a real 25 L box and load (R10), freezer and pad charge times (R12) and bail temperature (R14), a written fill recipe (R17), and dated build-log entries.

## Session 2026-09-25: recommendations accepted

Amish wrote on 2026-09-25: "i accept all your recommendations, go with them across all repos." Every item with a recommendation is now **decided by Amish, 2026-09-25: go with recommendation**, recorded in `docs/decisions/0002-recommendations-accepted.md` (TCT-DDR-002 v0.1). TCT-DDR-001 is at v0.2 with the new status wording.

### Decisions applied and what changed

- **D1 to D8 and T1 to T4:** status wording only; the design already followed them. D6 keeps `budget_usd` at $80 (unchanged). D3's pitch was already applied.
- **O4, R5:** relaxed to 38 % PCM for the stock-tube build, 50 % kept for a later extrusion. Before: not met, 38.3 to 39.9 % against 50 %. After: met (thin), 38.1 to 39.7 % against 38 %.
- **O5, R10:** dark finish plus guidance to lay produce on the cartridges (added to TCT-PRC-001, How it works); R10 kept at 8 h. Design-case hold 1.9 h (bare) before, 2.4 h (dark) after; still not met. The contact measurement is TRL 4: decided, on hold.
- **O6, R16 and budget:** quotes first, budget not raised; `budget_usd` stays $80. Getting quotes is a purchasing step: decided, on hold with TRL 4.
- **O7, R14:** H70 label rule (oven gloves or a 12 min wait) and pad charging preferred. R14 restated; at risk before, met with the handling rule after. Rule added to the precis, safety text, README and the drawing notes.
- **O8, finish:** matte black high-temperature paint over etch primer on shell, fins and caps. BOM row 1 $24 to $29; cartridge $71 to $76; first build $87 to $92 against $80; three-grade set about $230 to $245; empty mass 1.78 to 1.80 kg; filled 2.89 to 2.96 kg to 2.90 to 2.98 kg. Design-case R11 hold 7.2 to 13.6 h; R12 C5 freezer 5.6 to 4.2 h, C25 refrigerator 6.6 to 4.6 h, H70 oven 6.1 to 5.3 h. `finish` parameter added to `cad/src/model.py` (no geometry change; STEP and STL re-exported); TCT-DWG-001 Rev P1 to P2 with finish and handling notes; media re-rendered with a black shell and checked by eye.
- **O9, R1:** C25 band widened from 24 to 27 °C to 22 to 27 °C; at risk before, met after.
- Documents bumped: TCT-PRB-001 v0.4, TCT-PRC-001 v0.4, TCT-REQ-001 v0.4, TCT-CAL-001 v0.2 (results table regenerated from `docs/04-calcs/sizing.py`), TCT-DDR-001 v0.2, TCT-DDR-002 v0.1 new. PDFs rebuilt.
- `README.md`: Concept, Key components and Safety updated; "What sparked the idea" rewritten around the 1964 gastronorm standard (EN 631, 1993) in place of the earlier origin text.
- Generated files (drawing, media, PDFs) re-rendered so they carry the designmolecule.com footer.

### Requirement status (TCT-CAL-001 v0.2, Table 5)

Counts: 2 not met, 1 at risk, 3 not verifiable at TRL 3, 12 met.

| ID | Status | Value against target |
| --- | --- | --- |
| R10 | **Not met** | 2.4 h (dark finish) against 8 h at 32 °C; energy alone would last 9.7 h; produce contact not credited |
| R16 | **Not met** | $76 per cartridge against $50; first build $92 against the $80 budget (indicative) |
| R12 | At risk | Freezer, refrigerator and oven within 8 h; 60 W pad 2.7 to 10.3 h |
| R6, R7, R17 | Not verifiable at TRL 3 | Need TRL 4 tests and the fill recipe |
| R1, R2, R3, R4, R5, R8, R11, R14 | Met | R4 (2.98 kg against 3.0) and R5 (38.1 % against 38 %) are thin; R14 with the handling rule |
| R9, R13, R15, R18 | Met by design | |

### Still awaiting Amish

1. **O1** Named co-design partner and region for the first produce cooler. No recommendation.
2. **O2** Whether ColdPod or ZeerBox should declare ThermaCart as a dependency. No recommendation.
3. **O3** C5 charging: freezer with conditioning, or refrigerator. No recommendation (CAL favours the freezer).

### Cross-repo actions

None. No decision requires a change in another repo; O2, the only cross-repo question, has no recommendation. No other repo was edited.

### Safety concerns

Unchanged from the TRL 3 session, plus: the dark finish must be a high-temperature paint rated well above 90 °C and must not be applied over the fill port thread, O-ring gland or sight window. The H70 label now carries the oven handling rule.

### TRL 4

TRL 4 remains on hold by Amish's instruction. `trl: 3` and `trl_target: 3` are unchanged. Decided but on hold: the R10 contact measurement (O5) and supplier quotes (O6).

## Session 2026-09-26: sources strengthened

- `README.md`, "What sparked the idea": the Wikipedia article "Gastronorm" was replaced by the primary sources for the same event: the SVG (Swiss association for hospital, care-home and institutional catering) Gastro-Norm fact sheet, which records that SVG, the Swiss Hotel Association and Swiss kitchen equipment makers created the norm on a 530 x 325 mm grid in November 1964, and the BSI record for BS EN 631-1:1993. The unsupported day ("17 November") was dropped. The inspiration event is unchanged; its line in `INSPIRATIONS.md` now names the sources.
- `docs/01-problem.md` (TCT-PRB-001 v0.5): the Gastronorm prior-work line now cites BSI (EN 631-1) and SVG (530 x 325 mm grid); Wikipedia is kept only alongside them for the GN 1/3 size.
- All other links in the four README source sections were re-fetched and confirmed (FAO, Hanson et al. 2017, WHO, UNEP, MoFPI, IFPRI, IEA, Eurostat, Delaware food code, University of Edinburgh). No country rows were replaced.

## Session 2026-09-26: product appearance model and photoreal renders

Amish chose this repo for the first batch of product renders on 2026-09-26. This session adds an appearance model for photoreal product renders; the massing model, BOM, documents and drawing are unchanged.

### What was added

- `cad/src/product_model.py`: `product_parts()` (66 parts: 23 shell, 6 internal, 4 accessory, 33 context), `TITLE` and `RENDER_VIEWS` (hero, exploded and a detail view of the keyed nose at the frame's end stop without the bench). It imports `PARAMS`, `derived()` and `build_parts()` from `cad/src/model.py`, so every main dimension and interface is unchanged. It adds:
  - rounded outer corners (R4) on the tube and end flanges, softened fin edges, and a seam at each flange;
  - cap screw heads with hex sockets at the model.py positions; a hex G 3/4 fill port plug with its FKM sealing washer and a shank in the bore;
  - the folding bail with phenolic thermal-break washers, pivot pin heads and a ribbed silicone grip; the key tab with rounded leading edges;
  - the printed label (grade block, wordmark, data lines, kit-accent stripe), a painted grade colour band round the nose end and a painted side marking;
  - the sight window as a black bezel, a clear polycarbonate lens and the white (solid, charged) PCM vial under it;
  - inside: the PCM fill, gland spacers and plugs, and FKM O-rings;
  - the adapter frame with bend radii, a "C5 ONLY" grade decal beside the key slot and small rubber feet;
  - context: a compact bench top, with the C25 (green) and H70 (red) grades lying behind the C5 cartridge as a lineup, each with its key tab at its own grade position.
- `README.md`: hero image now points to `media/render-hero.png`, with a link to `media/render-exploded.png`. The render files are produced later by the orchestrator.

### Where the appearance model differs from model.py (Proposed, awaiting Amish)

1. **Grade colour band on the shell.** model.py and the BOM code the grade only by the label colour and the key position. The renders add an 18 mm painted band round the nose end in the grade colour (blue, green, red), visible from the side and when a cartridge sits in a frame. Recommendation: adopt it as a paint-masking step in BOM line 1 (no cost change within the indicative figure); the alternative is a colour-coded wrap label.
2. **Side marking.** A painted "ThermaCart, TC-L C5" marking on the front face. Recommendation: adopt as part of the label set (BOM line 6).
3. **Frame grade decal and feet.** A "C5 ONLY" decal beside the frame's key slot and four 1.2 mm rubber feet under the frame; neither is in model.py or BOM line 7. Recommendation: adopt the decal (it makes the keying legible to users); treat the feet as host-specific and leave them out of the BOM.
4. **Sight window build-up.** model.py shows the window as a 22 mm solid disc on the label; the render shows the same 22 mm outline as a bezel ring with a 15 mm clear lens and the PCM vial as a thin disc under it, above the tube wall. Recommendation: keep the model.py envelope; the vial arrangement is a TRL 4 detail and is on hold.
5. **Rounded tube corners.** model.py uses a sharp-cornered tube; stock 6 x 2 x 1/8 in tube has rounded outer corners, drawn here at R4. Recommendation: no change to model.py at TRL 3; confirm the supplier's corner radius with the quotes (O6).
6. **Pivot pins and fill port hex.** Pin heads are drawn on the outer faces of the bail arms (model.py has no pins; BOM line 5 lists stainless pins). The fill port hex (about 26 mm across flats) and its 1.5 mm washer stay inside the model.py port envelope. Recommendation: no change.
7. **Cap screws.** Shown as 1.2 mm proud heads at the model.py positions, as model.py draws them; BOM line 8 lists countersunk screws, which would sit flush. Recommendation: keep countersunk in the BOM and let the renders follow model.py for now.

### Status

This is an appearance model only: no tolerances, no fabrication detail, concept, not for fabrication. `trl` stays 3 and `trl_target` stays 3. TRL 4 remains on hold by Amish's instruction.

## Session 2026-09-27: kit 1.5.0 and image quality

- Kit 1.5.0 synced: STANDARDS v1.5 (sections 12 to 15: product renders, storefront images and image quality, public release, authorship and signing), `.kit/cards.py`, `.kit/image_qc.py`, `.kit/release_gate.py`, issue templates, and the `/render-product` and `/release` commands. `CLAUDE.md` now matches `.kit/CLAUDE.md`.
- Every `media/render-*.png` recaptioned from its original render with the new layout: the title, concept label and repository sit in a band above the render and the view note in a band below it, each line wrapped to the image width, so no text overlaps other text or the render or runs off the image. `media/card.png` and `media/social-preview.png` regenerated with the same rules.
- `python .kit/image_qc.py` and `python .kit/release_gate.py` pass. trl stays 3.

## Session 2026-10-01: constructable design and illustrated build plan (/build-plan, kit 1.7.0)

Authority: the `/build-plan` command, Amish's instruction of 2026-09-30 ("If you are realising that the design cannot be built as per concept - fix the design assumptions to match and be physically feasible as you draw the illustrations"), his 2026-09-30 rule that outstanding decisions go in a separate register, and his 2026-10-01 note that budgets are value-engineering targets.

### What was done

- Kit 1.7.0 installed (`.kit/`, `.claude/commands/`); `CLAUDE.md` replaced with `.kit/CLAUDE.md`.
- `cad/src/model.py`: rebuilt as separate components with BOM lines (`build_components()`), the constructable design P1 to P11 below, and 68 build123d constructability checks (`python cad/src/model.py --check`: overlaps, contacts and clearances for every pair of parts that meet, and the bail swung to 90 and 180 degrees). All 68 pass. `build_parts()` keeps the old grouped names for `sizing.py`, `concept_media.py` and `product_model.py`. STEP and STL re-exported.
- `docs/decisions/0003-design-for-construction.md` (TCT-DDR-003 v0.1, Draft): every change with its reason; made under Amish's 2026-09-30 instruction to make the design physically buildable; open for his review.
- `docs/04-calcs/sizing.py` and `01-sizing.md` (TCT-CAL-001 v0.3): masses from the new components, the bail thermal break with insulated bolts, cost and the value-engineering wording.
- `bom/bom.csv` lines 1 and 3 to 8 rewritten for the parts the build needs; `bom/bom-notes.md` updated.
- `cad/src/sheets.py`: general arrangement TCT-DWG-001 at Rev P4.
- `cad/src/build_plan_media.py` (new): overview, 10 making sketches `cad/drawings/TCT-DWG-101` to `110`, a cap hole layout, 10 joint close-ups (section views label each part on its cut face) and 12 assembly steps, in `docs/05-build-plan/`. Every picture was looked at and fixed where labels landed on the wrong part or covered it.
- `docs/05-build-plan.md` (TCT-BLD-001 v0.1) and `docs/06-design-decisions.md` (TCT-DEC-001 v0.1) written from the kit templates.
- `cad/src/concept_media.py` re-run: `media/hero.png`, `exploded.png`, `cutaway.png`, `flow.png`, `concept-blueprint.*`, `model.glb` and `viewer.html` now show the constructable model.
- TCT-PRB-001 v0.6, TCT-PRC-001 v0.5, TCT-REQ-001 v0.5: budget wording, numbers and component descriptions. `project.yaml`: `design_state: constructable`, TCT-DDR-003, BLD and DEC added to `trl_evidence`; `budget_usd` unchanged. `README.md`: links line, "Building the prototype" section with the overview picture, value-engineering wording.

### Design changes made for construction (TCT-DDR-003)

1. **P1 fill port:** the G 3/4 bore cut through the O-ring; now a G 1/2 anodised aluminium plug on a bonded seal, 56 mm toward the back, 3.5 mm inside the O-ring line.
2. **P2 O-ring gland:** 94 % full; now 2.5 mm FKM cord in a 2.1 mm deep gland (78 % fill, 16 % squeeze), plates cut to the measured bore, corners rounded, 1 mm lead-in chamfer on the tube ends.
3. **P3 radial screws:** on the wet side of the O-ring with no seal, countersunk in a 3.175 mm wall; now M5 x 10 button-head screws on FKM bonded seals into tapped plug edges.
4. **P4 cap stack:** no fixing between the three plates; now bonded face to face and screwed into blind holes in the plug.
5. **P5 bail:** the arms could not swing and the lugs sat over the seal with no fixing; now bolted 20 x 20 x 3 mm lug angles on phenolic washers, insulated bolts, 16 x 4 mm arms on 5 mm pins, rod screwed between the arms. Finger gap 41 mm; bail 39.1 °C (was 42.5 °C).
6. **P6 key tab:** no fixing; now two M4 screws into the plug.
7. **P7 frame stop:** stood 2 mm in front of the key, so no grade could seat; now the key passes through the slot and the frame floor is 294 mm (was 304 mm).
8. **P8 frame corners:** walls and stop overlapped; now the walls' tabs fold round the stop and are riveted.
9. **P9 melt indicator:** a 22 mm disc 2 mm thick; now a clear polycarbonate tube of the same paraffin between two fin-bar guards.
10. **P10 fins:** epoxy fillet each side and a comb jig (no geometry change).
11. **P11 tube corner radii** added to the model.

### Key results

- Envelope 323.4 x 152.4 x 63.5 mm (unchanged); inner volume 1.655 L (unchanged); empty 1.80 kg; filled 2.90 to 2.98 kg (R4 met, thin); PCM fraction 38.1 to 39.6 % (R5 met, thin).
- Value-engineering target: USD 80 for one C5 cartridge and one frame. Estimated cost of the constructable design: USD 97 (USD 17 over the target). R16: $80 per cartridge, over its $50 value-engineering target by $30; frame $17, $3 under.
- Requirement status: 1 not met (R10, cold-chain hold 2.4 h against 8 h), 1 over the value-engineering target (R16), 1 at risk (R12, pad charging), 3 not verifiable at TRL 3 (R6, R7, R17), 12 met.

### Proposed, awaiting Amish

All open decisions are in the design decisions register (`docs/06-design-decisions.md`): A1 how a wrong grade is shown to be rejected by the frame (touches the safety case), A2 W0 key fixing, A3 the R5 margin, O1 to O3 from TCT-DDR-001, and the appearance-model items 1 to 3 of 2026-09-26. Nine items are listed to confirm when parts are bought.

### Stale media (made on Amish's Mac, not regenerated here)

`media/render-*.png`, `media/card.png`, `media/social-preview.png` and the appearance model `cad/src/product_model.py` still show the concept bail and lugs, the round sight window, the G 3/4 plug and the concept frame stop. The design changed visibly; they need updating on the Mac. `media/render-hero.png`, which the README leads with, is not in this copy of the repo.

### Safety concerns

- Paraffin is melted for filling: water bath on a thermostat only, never a flame; C5 never above 45 °C (build plan S2, S3).
- The thermal break works only if no lug bolt touches its angle; the build plan has a meter check.
- The wrong-grade rejection (A1) relies on a 12 mm stand-off; a frozen W0 or hot H70 cartridge could still be left partly seated in a cold-chain host until A1 is decided.

### Recommended next step

Review TCT-DDR-003 and decide A1 in the register. TRL 4 (building and testing to TCT-BLD-001) remains on hold.

## 2026-10-02: photoreal renders redone on the constructable design

Rendered with Blender Cycles on Amish's Mac from the updated appearance model; captioned with `.kit/photo_caption.py`; `media/card.png` and `media/social-preview.png` regenerated with `.kit/cards.py`. Views: hero, exploded, detail. image_qc passes. Appearance deviations are those logged above as proposed, awaiting Amish.

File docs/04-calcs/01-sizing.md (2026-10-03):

---
doc_id: TCT-CAL-001
title: ThermaCart sizing calculations
project: ThermaCart
doc_type: Calculation
version: "0.5"
status: Draft
date: '2026-10-02'
author: Amish Chadha
license: CERN-OHL-S-2.0
revisions:
- version: "0.1"
  date: '2026-09-25'
  author: Amish Chadha
  change: First issue for TRL 3 (geometry and mass, storage per grade, pressure and wall stress, 2 mm wall option, hold times, recharge, handle temperature, keying, cost)
- version: "0.2"
  date: '2026-09-25'
  author: Amish Chadha
  change: Recommendations accepted by Amish (DDR-002); dark finish as the design case, paint mass and cost added, R1, R5 and R14 restated, results table updated
- version: "0.3"
  date: '2026-10-01'
  author: Amish Chadha
  change: Constructable design (TCT-DDR-003) applied to mass, bail thermal break and cost; budget treated as a value-engineering target, R16 reported against it
- version: "0.4"
  date: '2026-10-02'
  author: Amish Chadha
  change: "O3 decision of 2026-10-02 recorded (C5 freezer charging with a required conditioning step); no figure changed"
- version: "0.5"
  date: '2026-10-02'
  author: Amish Chadha
  change: "Approved decisions carried into the design: frame lip and raised grip (section G, envelope and handle temperature rechecked), grade band, side marking, conditioning time and frame decal priced (section H); a wrong grade stops 8 mm short, not 12 mm"
---

# ThermaCart sizing calculations

On paper the TC-L cartridge meets twelve of its eighteen requirements, has one at risk, misses one, is over its cost target on one and leaves three that only tests can settle. Version 0.3 follows the constructable design of TCT-DDR-003 (sealed radial screws, bolted lug angles on phenolic washers, a G 1/2 fill port, fixings for every part): the empty mass is unchanged at 1.80 kg, the bail runs cooler on its new thermal break, and the parts cost rises from $76 to $80 per cartridge. Version 0.5 carries the decisions of 2026-10-02 into the design: a low lip at the frame's open end now holds out a wrong grade (section G), the stowed grip is 3.5 mm higher to suit, and the painted grade band, side marking, printed conditioning time and frame decal bring the cartridge to $82.50 and the frame to $17.50. The budget in `project.yaml` is now treated as a value-engineering target, not a limit (Amish, 2026-10-01). This version applies the recommendations Amish accepted on 2026-09-25 (TCT-DDR-002): the shell carries a matte black finish (O8), so the dark-finish results are now the design values; the C25 band of R1 is 22 to 27 °C (O9); R5 is 38 % for the stock-tube build (O4); and R14 includes a labelled handling rule for H70 cartridges from an oven (O7). The miss is the cold-chain hold time (R10: 2.4 h against 8 h, because the cartridge cannot pull heat out of the cooler air fast enough, although it stores enough energy for 9.7 h) and, reported against the value-engineering targets rather than as a miss, the parts cost (R16: $82.50 per cartridge, $32.50 over its $50 target; one cartridge and one frame $100, $20 over the $80 value-engineering target). The one at risk is recharge on a 60 W pad (R12). With the verified Rubitherm datasheet values, the C5 grade now meets R3 (65 Wh), which the TRL 2 estimate did not; C25 meets it by a thin margin. The 2 mm wall evaluated under decision D5 is rejected: it adds only 3.5 % volume and its walls would yield under the vacuum that forms when a cartridge is frozen. Every number in this note is printed by `docs/04-calcs/sizing.py`; the tag in brackets, for example [C3], is the line of that script's output that carries it.

> **Safety:** These are first-principles estimates for a paper proof of concept. They do not show that a cartridge is leak-tight, drop-safe or fit for food contact, and they are not a substitute for tests. ThermaCart is not qualified for vaccines or medicines. See TCT-PRC-001, Safety.

## Scope and method

The note checks every requirement in TCT-REQ-001 v0.5 against the design in TCT-PRC-001 v0.5, the constructable design of TCT-DDR-003 and the parametric model `cad/src/model.py`. The script imports the model's `PARAMS`, its derived dimensions and its build123d solids, so the inner volume, part volumes, areas and key positions used here are those in the STEP files and in drawing TCT-DWG-001. It also reads `bom/bom.csv` and the value-engineering target `budget_usd` in `project.yaml`. Run it from the repo root with `python docs/04-calcs/sizing.py`.

## Assumptions

*Table 1. Main assumptions.*

| Area | Assumption | Basis |
| --- | --- | --- |
| PCM data | RT 5 HC: 250 kJ/kg from -2 to 13 °C, melt 5 to 6 °C, 0.85 kg/L solid, 0.76 kg/L liquid at 20 °C, maximum operating temperature 45 °C. RT 25 HC: 230 kJ/kg from 16 to 31 °C, melt 22 to 26 °C, 0.88 and 0.77 kg/L (liquid at 40 °C), maximum 65 °C. RT 70 HC: 260 kJ/kg from 62 to 77 °C, melt 69 to 71 °C, about 0.9 and 0.8 kg/L (liquid at 80 °C), maximum 90 °C. All: cp 2 kJ/(kg·K), k 0.2 W/(m·K), capacity ±7.5 % | Rubitherm datasheets for [RT 5 HC](https://www.rubitherm.eu/media/products/datasheets/Techdata_-RT5HC_EN_23072026.PDF), [RT 25 HC](https://www.rubitherm.eu/media/products/datasheets/Techdata_-RT25HC_EN_21012026.PDF) and [RT 70 HC](https://www.rubitherm.eu/media/products/datasheets/Techdata_-RT70HC_EN_21012026.PDF), read 2026-09-25 |
| Usable storage | Latent heat = capacity at the low side of the tolerance minus 2 kJ/(kg·K) x 15 K sensible; usable = latent plus sensible over the ±3 K band of R3; latent spread evenly over the melt range | Conservative reading of the datasheets |
| Fill | 90 % of the inner volume, filled as liquid at the grade's maximum operating temperature (45, 65 and 90 °C), then sealed with air at 1 atm; liquid expansion 0.001 /K, solid 0.0003 /K | Expansion coefficients are typical paraffin values, to confirm |
| Aluminium | 6063-T52 tube, minimum yield 110 MPa, design factor 1.5 (allowable 73 MPa); E 69 GPa; 2.70 kg/L, 0.9 kJ/(kg·K) | ASTM B221 minimum |
| Air side | Natural convection h = 1.32 (ΔT/0.15 m)^0.25 W/(m²·K) plus radiation; emissivity 0.90 for the decided matte black finish (TCT-DDR-002, O8), 0.10 for mill-finish aluminium as a comparison; 85 % of the outer area exposed | Handbook correlations |
| Cold box (R10) | 25 L cooler, 0.5 W/K, 32 °C ambient; 5 kg of produce precooled to 5 °C (3.9 kJ/(kg·K)) plus 2 kJ/K of air and liner; cartridges conditioned to 2 °C; contents and cooler air lumped, no direct contact between produce and cartridge | As in TCT-REQ-001; contact would help and is not credited |
| Hot box (R11) | GN carrier, 0.25 W/K, 25 °C ambient; 4 kg of food at 75 °C (3.5 kJ/(kg·K)) plus 2 kJ/K of liner; H70 charged to 85 °C | As in TCT-REQ-001 |
| Charging (R12) | Still-air freezer at -18 °C, refrigerator at 2 or 4 °C, fan oven at 85 °C (h 15 W/(m²·K) plus radiation), 60 W pad with 80 % of its output entering the cartridge | Screening values |
| Burn thresholds (R14) | 10 s contact: about 55 °C for bare metal and about 70 °C for plastics and rubber | Commonly quoted from ISO 13732-1; not checked against the standard (paywalled) |
| Cost | Indicative one-off USD prices in `bom/bom.csv`, not quotes; PCM at $10/kg; `budget_usd` read as a value-engineering target | To be replaced with quotes before any build |

## A. Geometry and mass (R2, R4, R5)

- **Envelope.** With the bail stowed the cartridge is 323.4 x 152.4 x 63.5 mm, inside the GN 1/3 slot (325 x 176 mm, 65 mm deep) with margins of 1.6, 23.6 and 1.5 mm [A1]. The TRL 2 fixed handle left only about 14 mm between grip and end cap, too little for fingers; the folding bail stows inside the envelope and gives a 39 mm finger gap when raised [A3]. With the stowed grip raised 3.5 mm for the frame lip (TCT-DEC-001, item 1), the stowed envelope is unchanged and still fits the GN 1/3 slot [A1]. The bail now pivots on two bolted lug angles (TCT-DDR-003, P5).
- **Inner volume.** 146.05 x 44.45 x 254.9 mm, or 1.655 L [A2], slightly more than the 1.62 L of TRL 2, because a thinner 3.175 mm (1/8 in) flange let the tube grow from 270 to 280 mm.
- **Mass.** The model's aluminium parts come to 1.657 kg, and seals, screws, bolts, pins, the anodised aluminium fill plug, grip, label, indicator, adhesive and about 15 g of primer and paint add 0.140 kg, so the empty cartridge is 1.80 kg [A4, A5] against about 1.5 kg at TRL 2. The caps are the reason: a garage-built cap is a solid stack of flange, gland spacer and plug (about 100 cm³ each) rather than the milled, pocketed cap assumed at TRL 2.
- **Filled.** C5 2.90 kg, C25 2.92 kg and H70 2.98 kg, with 1.104, 1.119 and 1.180 kg of PCM [A6]. R4 (3.0 kg) is met with a thin margin. The PCM fraction is 38.1 to 39.6 %, which meets the 38 % target set for the stock-tube build by TCT-DDR-002 (O4) with little margin; the 50 % target stays for a later extrusion.

## B. Usable storage per grade (R1, R3)

R1 is met for all three grades. RT 25 HC melts over 22 to 26 °C, which lies inside the C25 band of 22 to 27 °C set by TCT-DDR-002 (O9); the earlier 24 to 27 °C band would not have been met.

*Table 2. Storage within ±3 K of the melt point [B1].*

| Grade | PCM | Latent (low side) | Usable in band | Per cartridge | At nominal datasheet value |
| --- | --- | --- | --- | --- | --- |
| C5 | 1.104 kg | 201.2 kJ/kg | 213.2 kJ/kg | **65.4 Wh** | 71.2 Wh |
| C25 | 1.119 kg | 182.8 kJ/kg | 194.8 kJ/kg | **60.5 Wh** | 65.9 Wh |
| H70 | 1.180 kg | 210.5 kJ/kg | 222.5 kJ/kg | **72.9 Wh** | 79.3 Wh |

- All three grades meet R3 (60 Wh). The TRL 2 figures (55, 61 and 67 Wh) used assumed usable heats of 180, 200 and 220 kJ/kg; the datasheets support more for C5 and H70 and less for C25.
- Energy density on filled mass is 22.6, 20.8 and 24.5 Wh/kg [B2].
- **2 mm wall (D5).** A metric 150 x 50 x 2 mm tube of the same length holds 1.712 L, only 3.5 % more, and would raise C5 to 67.7 Wh [B3]. Section C shows its walls would yield. It is not needed for R3 and is not adopted.

## C. Pressure and wall stress (R8, D5)

Filling as liquid at the grade's maximum operating temperature fixes the gauge pressure at zero at that temperature. Everything colder makes a partial vacuum, because the PCM shrinks by about 12 % on freezing and the trapped air cools.

*Table 3. Gauge pressure with 10 % ullage [C1].*

| Grade | Sealed at | Solid at -25 °C | 20 K above the limit |
| --- | --- | --- | --- |
| C5 | 45 °C | -0.63 bar (ullage 20.8 %) | +0.29 bar at 65 °C |
| C25 | 65 °C | -0.68 bar (ullage 22.1 %) | +0.29 bar at 85 °C |
| H70 | 90 °C | -0.64 bar (ullage 18.5 %) | +0.29 bar at 110 °C |

- **R8 is met**: 0.00 bar at the fill temperature by construction and +0.29 bar even 20 K beyond the datasheet limit, against 0.5 bar [C2].
- **Walls.** Treating the tube as a closed frame loaded on all four walls, the corner bending stress is 56 MPa at -0.68 bar, 83 MPa at full vacuum and 24 MPa at +0.29 bar, against an allowable of 73 MPa [C3]. The 3.175 mm wall carries the worst service vacuum with margin. Full vacuum could only arise in a cartridge sealed with no air; it would exceed the allowable stress but not the yield. The broad faces deflect about 0.8 mm inward at -0.68 bar [C5].
- **2 mm wall (D5).** The same vacuum gives 141 MPa, 1.28 times the minimum yield; its allowable pressure is only 0.35 bar [C4]. Rejected.
- **Caps.** At +0.29 bar each cap carries 190 N, 32 N per radial M5 screw [C6]. Under vacuum the flange bears on the tube end.
- **Drop (R6, indicative).** A molten cartridge dropped 1 m end-on and stopping in 4 mm decelerates at about 250 g; if the gas ullage did not cushion the liquid, the surge could reach 5.0 bar on the lower cap, 541 N per screw [C7]. The screws have ample capacity (M5 A2-70 proof load about 6,400 N), but that surge is ten times the service pressure on the walls and the O-ring. R6 needs a drop test at TRL 4.

## D. Hold times (R10, R11)

The outer area is 0.1138 m² of tube, 0.0503 m² of fins and 0.0155 m² of end faces, 0.1526 m² effective [D1].

**R10 is not met.** Two C5 cartridges store 131 Wh within the band, enough for 9.7 h at the 13.5 W leak [D2], so energy is not the limit. The limit is heat transfer from the cooler air into the cartridges. With the decided matte black finish (emissivity 0.9), still air and radiation give about 7.3 W/(m²·K), 1.11 W/K per cartridge, so the contents settle near 10 °C while the PCM melts and leave the 2 to 8 °C band after 2.4 h at 32 °C [D3] (4.0 h at 25 °C [D4]); the band holds indefinitely while the PCM melts only below about 19 °C ambient. A bare mill finish would give 1.9 h [D3], and a third dark cartridge 3.4 h [D5]. Under TCT-DDR-002 (O5) the user guidance is to lay produce directly on the cartridges, which is how ice packs are used; the model does not credit that contact, so this is a pessimistic bound, and R10 keeps its 8 h target until a TRL 4 measurement (on hold) shows the contact effect.

**R11 is met.** One H70 cartridge charged to 85 °C keeps 4 kg of food from 75 °C at 63 °C or more for 13.6 h with the decided dark finish and 7.2 h with a bare finish [D6]. The food alone would last 4.9 h [D7], so the cartridge adds at least 2.3 h. The hot case works because the H70 cartridge runs about 7 K above the food and radiation is stronger at 70 °C.

## E. Recharge (R12)

A quasi-steady Stefan model adds the resistance of the growing layer of changed PCM (k 0.2 W/(m·K), up to 22 mm from each broad face) to the air-side film.

*Table 4. Recharge time [E1, E2, E3].*

| Case | Bare finish | Dark finish | R12 (8 h) |
| --- | --- | --- | --- |
| C5 from 8 °C in a -18 °C freezer | 5.6 h | 4.2 h | Met |
| C5 in a 2 °C refrigerator | 51.1 h | 31.4 h | Not practical |
| C25 from 28 °C in a -18 °C freezer | 2.8 h | 2.1 h | Met |
| C25 in a 4 °C refrigerator | 6.6 h | 4.6 h | Met |
| H70 from 25 °C in a fan oven at 85 °C | 6.1 h | 5.3 h | Met |
| H70 on a 60 W pad | 2.7 h if the heat reaches the PCM; up to 10.3 h if the melt must conduct upward from a 90 °C base | | At risk |

- The dark finish (O8) is the design case: C5 in a freezer 4.2 h, C25 in a refrigerator 4.6 h and H70 in an oven 5.3 h all meet the 8 h target [E1, E2].
- Charging C5 in a refrigerator, one option in the TRL 2 open questions, would take one to two days, so freezer charging with a conditioning step is the practical route. Amish decided on 2026-10-02 (O3) to charge C5 in a domestic freezer followed by the conditioning step, with the conditioning time printed on the C5 label as a required step.
- The TRL 2 figure of about 2.5 h on a 60 W pad assumed the heat is absorbed as fast as it is supplied. It needs 130 Wh [E3]; paraffin conducts poorly, and the pad must never push the base above the RT 70 HC limit of 90 °C, so the true time lies between 2.7 and 10.3 h and depends on convection in the melt. This is a question for a TRL 4 test.
- **R12 target correction.** The TRL 2 target allowed an oven "at 100 °C or less", which is above the 90 °C maximum operating temperature of RT 70 HC. TCT-REQ-001 v0.3 and later say 85 °C, never above 90 °C.
- The energy flow of one pad charge is 162 Wh in, 130 Wh stored between 25 and 80 °C, 88 Wh released above 63 °C and 42 Wh below it, with 32 Wh lost at the pad [E4] (Figure 2 of TCT-PRC-001).

## F. Handle temperature (R14)

- **Thermal break.** In the constructable design (TCT-DDR-003, P5) each lug angle stands on two 3 mm phenolic washers and each of its two M4 bolts has a 3 mm phenolic washer under its head; the bolt passes the angle with an air gap, so a steel bolt never carries heat straight into the bail. The eight washers conduct 0.032 W/K and the bail (angles, arms and the bare part of the rod, 0.0117 m² from the model) loses 0.093 W/K to the air, so a bail on a cartridge at 71 or 80 °C settles at 36.9 or 39.2 °C [F1]; the 2 mm shorter arms of the raised grip (version 0.5) change this by 0.1 K, below the assumed 55 °C bare-metal threshold [F3]. Version 0.2 gave 39.6 and 42.5 °C for the concept bail.
- **Straight from the oven** the bail is at oven temperature, 85 °C. With a 9 min time constant it falls below 55 °C after about 10 min [F2]; the label's 12 min rule keeps its margin. The silicone grip is also at 85 °C at first, above the assumed 70 °C threshold for rubber.
- R14 is **met with the handling rule** decided in TCT-DDR-002 (O7): pad charging is preferred and keeps the bail near 39 °C, and the label tells users to take an H70 cartridge from an oven with oven gloves or to wait 12 min. Without the rule, a cartridge lifted straight out of an oven would not meet the burn threshold. The bail is bare aluminium on its thermal break and is not painted, so the dark finish does not change these figures. C5 and C25 never exceed 65 °C and meet R14.

## G. Grade keying (R9)

Key tabs 30 mm wide sit at -43, 0, +43 and -61 mm (C5, C25, H70, W0), and each frame slot is 3 mm wider than its key on each side. Every pairing was checked: each frame accepts only its own grade [G1]. The W0 key overlaps the C5 slot but cannot pass it.

- **Frame lip (TCT-DEC-001, item 1, option (b)).** A wrong grade's key meets the stop before the cartridge is seated. With the 10 mm key and the 2 mm gap between the seated nose flange and the stop, it stops 8 mm short of seated; earlier versions of this note and TCT-DDR-003 gave 12 mm, which added the gap instead of subtracting it. The frame now has a lip 4 mm high folded up at its open end, its inside face 3 mm beyond the ends of the seated bottom fins. A seated cartridge's fins drop behind it; a wrong grade's fins overlap it by 5 mm and rest on top of it, so that cartridge sits with its handle end 4 mm high and 8 mm proud, and cannot be pushed down to the floor [G2]. Three 14 mm notches in the lip let the bottom radial screw heads past it. The stowed grip was raised 3.5 mm (pivot 47.5 mm up, arms 36 mm between holes) and its underside is 1.85 mm above the lip top [G3]. The model checks the seated C5 and the C25 and H70 cartridges in a C5 frame, with the bail stowed and raised.

## H. Cost against the value-engineering targets (R16)

`budget_usd` is a hypothetical value-engineering target, not a spending limit (Amish, 2026-10-01: "the budgets are a hypothethical control target to ensure we are thinking along a value engineering lens"). Value-engineering target: USD 80. Estimated cost of the constructable design: USD 100 (USD 20 over the target).

- One cartridge costs $82.50, $32.50 over its $50 target, and one frame $17.50, $2.50 under its $20 target [H1]. The decisions of 2026-10-02 add $1.50 for the masked grade band (row 1), $1 for the painted side marking (row 6; the printed conditioning time costs nothing) and $0.50 for the frame's "C5 ONLY" decal (row 7). The dark finish (O8) adds about $5 for primer and paint; the parts added for construction (TCT-DDR-003: bonded seals, bolts, phenolic washers, rivets) add $5, less $1 for the smaller fill plug. The TRL 2 estimate of $49 left out the fin bar and finish, priced the caps as simple plates and used a lower tube price; all figures remain indicative, not quoted.
- One C5 cartridge and one frame cost $100.00, $20.00 over the $80 value-engineering target [H1]; supplier quotes (TCT-DDR-002, O6) wait with TRL 4. A set of one cartridge per grade and one frame would be about $266 [H2]. PCM at $20/kg instead of $10/kg would add $11 per cartridge [H3].
- The build uses plates cut and filed and bars bonded with epoxy, with no milling; the frame needs a hand brake, available at a makerspace.
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

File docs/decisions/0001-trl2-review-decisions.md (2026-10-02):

---
doc_id: TCT-DDR-001
title: ThermaCart TRL 2 review decisions
project: ThermaCart
doc_type: Design decision record
version: "0.3"
status: Draft
date: '2026-10-02'
author: Amish Chadha
license: CERN-OHL-S-2.0
revisions:
- version: "0.1"
  date: '2026-09-25'
  author: Amish Chadha
  change: Record the TRL 2 review items adopted as recommended for TRL 3 under Amish's 2026-09-25 instruction, the items that remain open, and the TRL 3 refinements that follow from TCT-CAL-001
- version: "0.2"
  date: '2026-09-25'
  author: Amish Chadha
  change: Recommendations accepted by Amish (DDR-002)
- version: "0.3"
  date: '2026-10-02'
  author: Amish Chadha
  change: "O1 to O3 decided by Amish on 2026-10-02 (TCT-DEC-001, items 4 to 6)"
---

# 0001: TRL 2 review decisions

- **Date:** 2026-09-25
- **Status:** accepted. On 2026-09-25 Amish accepted all recommendations ("i accept all your recommendations, go with them across all repos"). Items D1 to D8, T1 to T4 and O4 to O9 are decided by Amish, going with the recommendation; items O1 to O3 had no recommendation at this record and were decided by Amish on 2026-10-02 (TCT-DEC-001, items 4 to 6): "i approve your recommendations for all 555 open decisions." See TCT-DDR-002.

## Context

The TRL 2 review note (`docs/REVIEW.md`, session 2026-09-25, /populate) listed eight items as "Proposed, awaiting Amish", and the design precis TCT-PRC-001 v0.2 listed six key design choices, each with options and, for most, a recommendation. On 2026-09-25 Amish asked for this batch of repos to be taken through the usual process with the instruction "you know the drill, nothing gets past TRL 3". At first every item that carried a recommendation was adopted as recommended for TRL 3 under that instruction and left open for his review. Later on 2026-09-25 Amish accepted all recommendations across all repos, so those items are now decided (TCT-DDR-002). Items without a recommendation stay "Proposed, awaiting Amish".

## Options considered

The options for each item are those listed in `docs/REVIEW.md` (session 2026-09-25, /populate) and in TCT-PRC-001 v0.2, Key design choices.
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

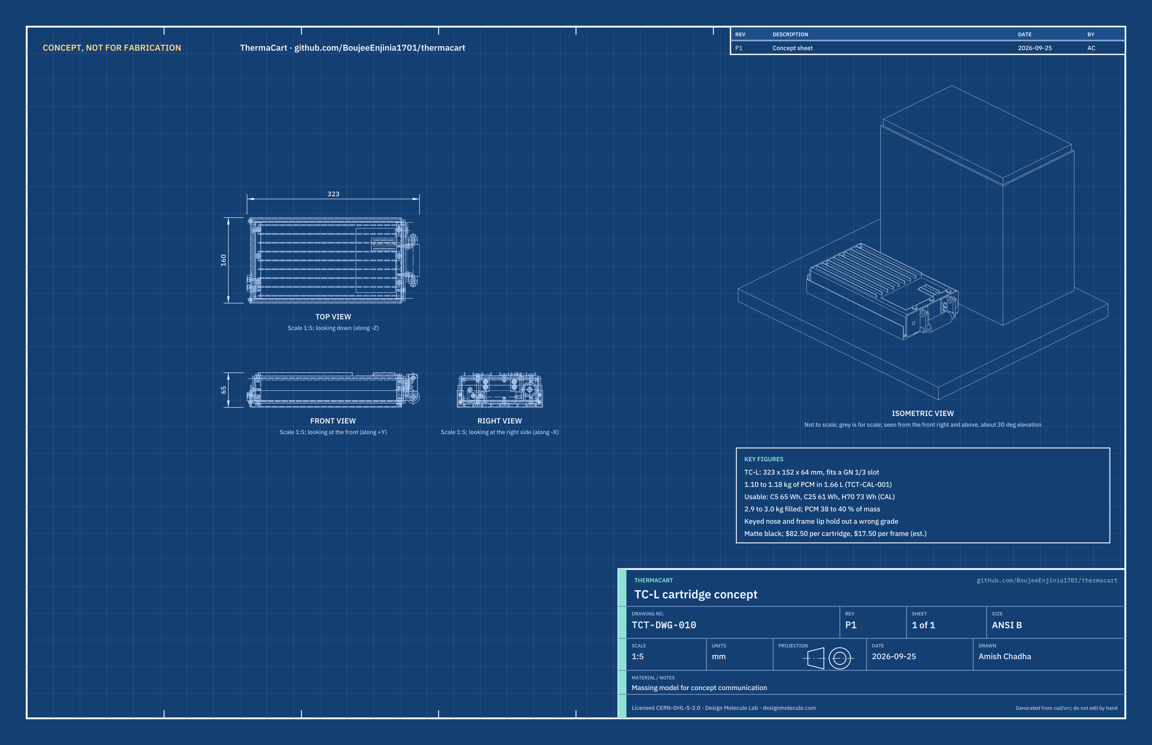
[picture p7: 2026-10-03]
media/concept-blueprint.png

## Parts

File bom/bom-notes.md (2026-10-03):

# BOM notes

- Rows 1 to 8 are numbered to match the exploded view (`media/exploded.png`) and the component table in the design precis (TCT-PRC-001 v0.4). Quantities and sizes follow the parametric model `cad/src/model.py`.
- All prices are indicative USD for one-off prototype quantities, as of September 2026. They are estimates, not quotes, and must be replaced with supplier quotes before any build.
- Rows 1 to 6 and 8 make one cartridge: $82.50, including about $5 of primer and matte black high-temperature paint for the finish decided in TCT-DDR-002 (O8) and the parts added to make the design constructable (TCT-DDR-003, 2026-10-01: bonded seals, bolts, phenolic washers, a G 1/2 plug, rivets) and the items decided on 2026-10-02 (grade band $1.50, side marking $1). Row 7 (adapter frame) is per host slot: $17.50, including four rivets, the lip and the decal. `docs/04-calcs/sizing.py` reads this file and prints these totals (TCT-CAL-001, section H).
- Value engineering: `budget_usd` in `project.yaml` is a hypothetical value-engineering target, not a limit (Amish, 2026-10-01). Value-engineering target: USD 80. Estimated cost of the constructable design: USD 100 (USD 20 over the target). The target covers one C5 cartridge and one frame (TCT-DDR-001, D6). Cost drivers and savings worth trying are in the design decisions register (`docs/06-design-decisions.md`). Supplier quotes (TCT-DDR-002, O6) wait with TRL 4, which is on hold.
- Decided by Amish on 2026-10-02 (TCT-DEC-001, items 1 and 6 to 9) and written into the BOM lines: an 18 mm painted grade band round the nose end as a masking step in row 1 (basis: share of a $9 can of coloured high-temperature aerosol paint, about $1, and masking tape, about $0.50); the painted side marking "ThermaCart, TC-L C5" (cut vinyl stencil and white paint, about $1) and the printed conditioning time on the C5 label (no added cost) in row 6; the frame's 4 mm lip (same blank, no added cost) and a "C5 ONLY" printed vinyl decal (about $0.50) in row 7. Rubber feet are left to each host. The paint for the band and marking adds about 2 g to the cartridge (TCT-CAL-001, A5).
- A set of one cartridge in each of the three grades plus one frame would be about $266.
- Row 2 is priced for the C5 grade at $10/kg. The C25 and H70 fills are 1.12 and 1.18 kg. PCM prices vary widely with quantity; at $20/kg a cartridge costs about $11 more.
- The caps (row 3) are built from flat 6061 plate cut and filed, so no milling is needed. The frame (row 7) needs a hand brake, for example at a makerspace.

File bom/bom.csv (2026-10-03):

item | qty | spec | supplier | unit_cost_usd | make_buy | notes
1 Cartridge shell (tube and fins) | 1 | 6063-T52 rectangular tube 152.4 x 50.8 x 3.175 mm (6 x 2 x 1/8 in), 280 mm long, ends squared with a 1 mm lead-in chamfer inside, twelve 5.5 mm radial screw holes; 18 fin strips of 6063 flat bar 6.35 x 1.59 mm (1/4 x 1/16 in), nine 264 mm (bottom) and nine 176 mm (top), bonded on edge with an epoxy fillet each side; outer surfaces etch-primed and painted matte black with high-temperature paint (emissivity about 0.9, TCT-DDR-002 O8); then an 18 mm grade band round the nose end, 22 mm from the key-end face, masked with tape and painted in the grade colour (C5 blue) with high-temperature paint (TCT-DEC-001 item 7) | Metals retailer (cut to length) and hardware store | 30.50 | make | Indicative, not quoted: tube about $16 cut to length, fin bar about $8 (two 3.66 m bars, also used for the indicator guards), primer and paint about $5 per cartridge (share of aerosol cans), grade band about $1.50 (share of a $9 can of coloured high-temperature aerosol paint, about $1, and 18 mm masking tape, about $0.50)
2 PCM fill | 1 | About 1.10 kg of C5 organic paraffin (Rubitherm RT 5 HC class) filled at 45 °C to 90 % of the 1.655 L inner volume; C25 grade 1.12 kg (RT 25 HC class, filled at 65 °C), H70 grade 1.18 kg (RT 70 HC class, filled at 90 °C) | PCM manufacturer or distributor | 11.00 | buy | Indicative at $10/kg for the C5 first build; sample-quantity quote needed
3 End caps with O-ring seals | 2 | Stack of a 3.175 mm flange, a 3 mm gland spacer and a 9.525 mm plug in 6061 plate with radiused corners, bonded face to face with the structural epoxy and held by M4 countersunk screws; FKM 2.5 mm cord O-ring spliced to length in a 3 x 2.1 mm corner gland (78 % fill); plug edges tapped M5 for six radial screws; handle-end stack tapped G 1/2 for the fill port and M4 for the lug bolts (TCT-DDR-003) | Metals retailer and seal supplier | 7.00 | make | Indicative, not quoted; plates cut and filed, no milling
4 Fill port plug and seal | 1 | G 1/2 plug with collar and hex socket (DIN 908 class), anodised aluminium (no stainless and aluminium couple, and 20 g lighter than steel), with a bonded FKM sealing washer and anti-seize on the thread, in the handle-end cap (TCT-DDR-003, P1) | Hydraulic fittings supplier | 3.00 | buy | Indicative, not quoted; was G 3/4 at $4
5 Handle and keyed nose | 1 | Folding bail: two lug angles 32 mm long from 20 x 20 x 3 mm 6063 angle, two arms 52 mm long (36 mm between holes) from 16 x 4 mm 6060 flat bar, 16 mm 6061 rod 80 mm long tapped M6 at both ends, two 5 mm stainless pivot pins with nyloc nuts, four phenolic thermal-break washers 9 x 4.5 x 3 mm and four phenolic washers 9 x 4.3 x 3 mm under the lug bolt heads, silicone grip sleeve 24 mm OD x 60 mm; aluminium key tab 30 x 16 x 10 mm from 30 x 10 mm flat bar at the grade position (TCT-DDR-003, P5, P6) | Metals retailer and hardware store | 8.00 | make | Indicative, not quoted; bail and thermal break sized in TCT-CAL-001 (R2, R14)
6 Grade label and melt indicator | 1 | Colour-coded polyester label with grade, fill, melt point and warnings, and for C5 the printed conditioning time (freezer, then the conditioning step, about 4.2 h, as a required step), notched for the indicator; painted side marking "ThermaCart, TC-L C5" on the front face, white high-temperature paint through a cut vinyl stencil; clear polycarbonate tube 6 mm OD x 4 mm bore, 40 mm long, filled with the grade's PCM and closed with epoxy plugs; two 40 mm guards of the fin bar (TCT-DDR-003, P9; TCT-DEC-001 items 6 and 8) | Label printer and plastics supplier | 5.00 | buy | Indicative, not quoted: label and indicator about $4; side marking about $1 (cut vinyl stencil, about $0.50, and a share of white high-temperature paint, about $0.50); the conditioning time adds no cost to the printed label
7 Cabinet adapter frame | 1 | Bent 1.5 mm 5052 aluminium sheet: floor 283 x 160 mm, 30 mm side walls ending in 12 mm corner tabs folded round the stop, 40 mm end stop with the grade key slot, and a 4 mm lip folded up at the open end with three 14 mm notches for the radial screw heads, which holds out a wrong grade; four 3.2 mm aluminium blind rivets; a "C5 ONLY" vinyl decal on the stop beside the slot (TCT-DDR-003, P7, P8; TCT-DEC-001 items 1 and 9) | Metals retailer; hand brake at a makerspace | 17.50 | make | Indicative, not quoted; one per host slot, not part of the cartridge. The shorter floor and the lip use no more sheet; the printed vinyl decal adds about $0.50 (one of a printed sheet). Rubber feet are left to each host
8 Hardware and consumables | 1 | Twelve M5 x 10 A2 button-head screws (ISO 7380) with M5 FKM bonded sealing washers; three M4 x 12 A2 countersunk screws (cap stacks); two M4 x 16 and four M4 x 20 A2 socket cap screws (key tab, lug angles); two M6 x 12 A2 button-head screws (rod ends); structural epoxy rated to 120 °C or more for the fins, cap stacks and indicator; thread sealant; deburring and cleaning supplies | Hardware store and seal supplier | 11.00 | buy | Indicative, not quoted; per cartridge

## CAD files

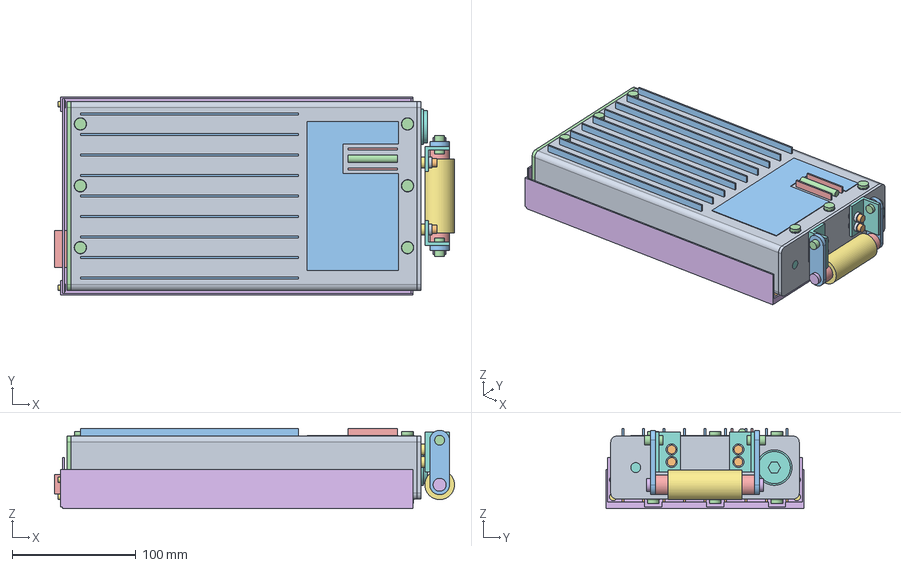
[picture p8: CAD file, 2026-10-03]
cad/step/thermacart-assembly.step
323.4 x 160.4 x 65.0 mm

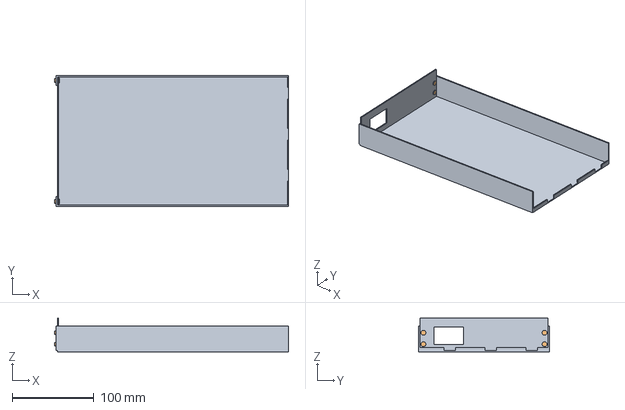
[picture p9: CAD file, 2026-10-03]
cad/step/adapter-frame.step
286.7 x 160.4 x 41.5 mm

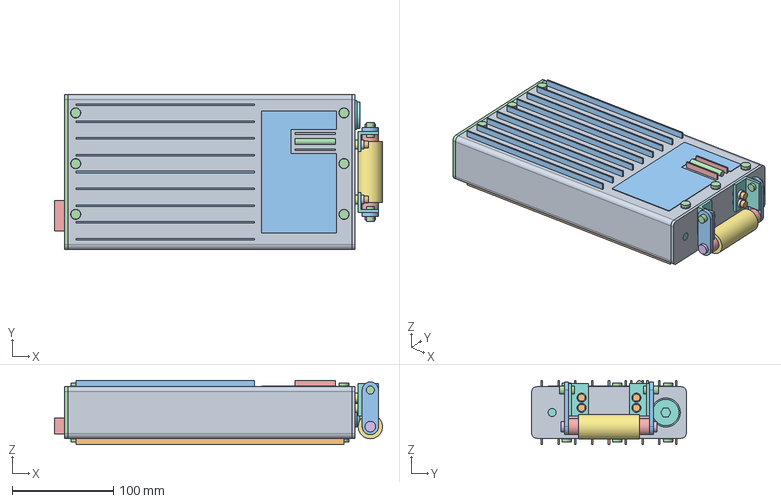
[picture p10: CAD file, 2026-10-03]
cad/step/tc-l-cartridge.step
323.4 x 152.4 x 63.5 mm

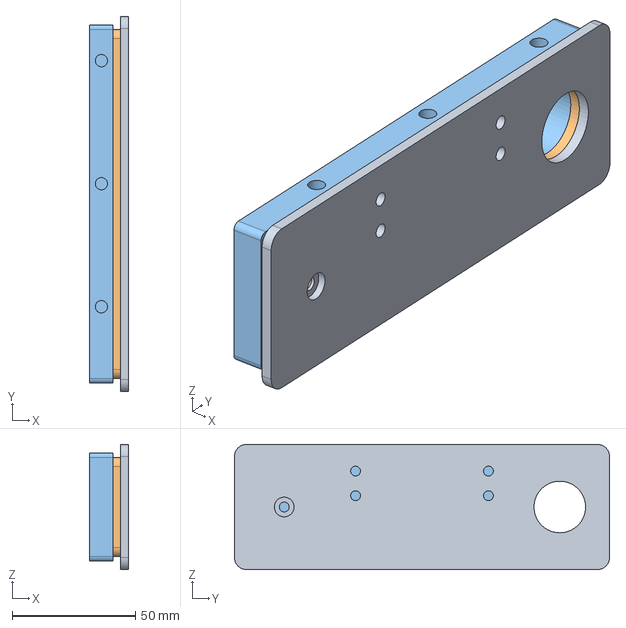
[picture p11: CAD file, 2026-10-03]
cad/step/end-cap.step
15.7 x 152.4 x 50.8 mm

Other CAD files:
cad/stl/adapter-frame.stl
cad/stl/end-cap.stl
cad/stl/tc-l-cartridge.stl
cad/stl/thermacart-assembly.stl

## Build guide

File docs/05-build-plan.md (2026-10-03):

---
doc_id: TCT-BLD-001
title: ThermaCart prototype build plan
project: ThermaCart
doc_type: Build plan
version: "0.3"
status: Draft
date: '2026-10-02'
author: Amish Chadha
license: CERN-OHL-S-2.0
revisions:
  - version: "0.1"
    date: '2026-10-01'
    author: Amish Chadha
    change: First build plan, with pictures by component and step; design made constructable (TCT-DDR-003)
  - version: "0.2"
    date: '2026-10-02'
    author: Amish Chadha
    change: "Section 2: the changes recorded in TCT-DDR-003 accepted by Amish on 2026-10-02"
  - version: "0.3"
    date: '2026-10-02'
    author: Amish Chadha
    change: "Approved decisions of 2026-10-02 carried in: frame lip, raised grip, grade band, side marking, conditioning time on the label and frame decal; pictures regenerated"
---

# ThermaCart prototype build plan

**Plan, not yet built.** How to build the first proof-of-concept prototype, component by component. Building and testing to it is TRL 4 work. Decisions still to be made are kept in the design decisions register ([docs/06-design-decisions.md](06-design-decisions.md)), not here.

## 1. What you are building

Figure 1. Every component, pulled apart and numbered in build order

*Figure 1. Every component pulled apart and numbered in build order.*

The prototype is one TC-L cartridge in the cold-chain grade (C5) and one adapter frame for it. The cartridge is a 280 mm length of 6 x 2 in aluminium tube with eighteen thin fins bonded to its top and bottom, painted matte black, closed at each end by a cap made of three bonded aluminium plates and an O-ring, and filled with 1.10 kg of paraffin that melts at 5 °C. A folding bail on the handle end carries it, a key tab on the other end codes its grade, and a small clear tube of the same paraffin on top shows whether it is charged. The frame is a bent aluminium tray whose end stop has a slot that only the C5 key passes, with a low lip at its open end that holds out a cartridge of any other grade. Figure 1 shows the twelve components in the order you make or fit them. Eight are made in a small workshop: the shell tube, the fins, the two cap stacks, the key tab, the bail (lug angles, arms and rod), the melt indicator and the frame. The rest are bought: the paraffin, O-ring cord, fill plug, grip, label, washers and fixings. The work is sawing, filing, drilling and tapping aluminium, bonding with epoxy, painting, bending sheet on a hand brake and riveting; nothing needs milling or welding. The parts cost about $100 for the cartridge and frame, from the bill of materials.

> **Safety:** Paraffin is combustible: melt it only in a water bath on a thermostatic heater, never over a flame or on a hot plate, and never above 45 °C for the C5 grade. Cut aluminium edges and fin ends are sharp: deburr everything and wear gloves when handling the tube and sheet. Epoxy, etch primer and paint give off fumes: work in a ventilated space with gloves and eye protection. The filled cartridge weighs about 2.9 kg.

## 2. What changed to make it buildable

The concept showed what the cartridge does; some of its parts could not be made, fixed or sealed as drawn. Each change below keeps what the cartridge does, and all of them are recorded in decision record TCT-DDR-003, accepted by Amish on 2026-10-02.

*Table 1. Changes from the concept.*

| Component | The concept had | The buildable design has | Why |
| --- | --- | --- | --- |
| Fill port | A G 3/4 port whose hole cut through the O-ring | A G 1/2 aluminium plug, 56 mm toward the back, its thread 3.5 mm inside the O-ring line (Figure 12) | The port no longer opens a leak path past the seal |
| O-ring and cap plates | A 3 mm cord filling 94 % of its groove; square plate corners | A 2.5 mm cord filling 78 % of a groove 2.1 mm deep; plate corners rounded to match the tube (Figure 7) | Room for the cord to swell when hot; the plates clear the tube's inside corners |
| Radial cap screws | Countersunk screws on the PCM side of the O-ring, drawn as heads only | Button-head screws on bonded sealing washers, into tapped holes in the plug (Figure 8) | Each screw hole is sealed under its head |
| Cap plates | No fixing between the three plates | Bonded face to face and held by screws into blind holes in the plug | One rigid, sealed block; no hole reaches the PCM |
| Bail | Arms in front of the lugs, so they could not swing; lugs over the seal with no fixing | Bolted lug angles on phenolic washers; arms beside the angles on pins; rod screwed between the arms (Figures 14 and 16) | The bail folds, every joint is fixed, and only phenolic touches the bail |
| Key tab | No fixing | Two screws into the plug (Figure 10) | |
| Adapter frame | A stop 2 mm in front of the key, so the key never reached its slot; walls and stop overlapping in the corners | The key passes through the slot when seated; the walls fold round the stop and are riveted (Figures 21 and 22) | The frame has a seated position and can be bent from one sheet |
| Melt indicator | A 22 mm disc 2 mm thick over a vial | A clear tube of the same paraffin between two guards (Figure 19) | It can be made, fixed and protected |

## 3. Making the components

Make and check each component before the assembly step that needs it. Sizes are in millimetres. "Front" is the long face you see when the handle end is on your right and the key end on your left; "back" is the face opposite. Workshop tolerance is 0.5 mm unless a step says otherwise; drawings do not carry tolerances before TRL 4.

### 3.1 Shell tube

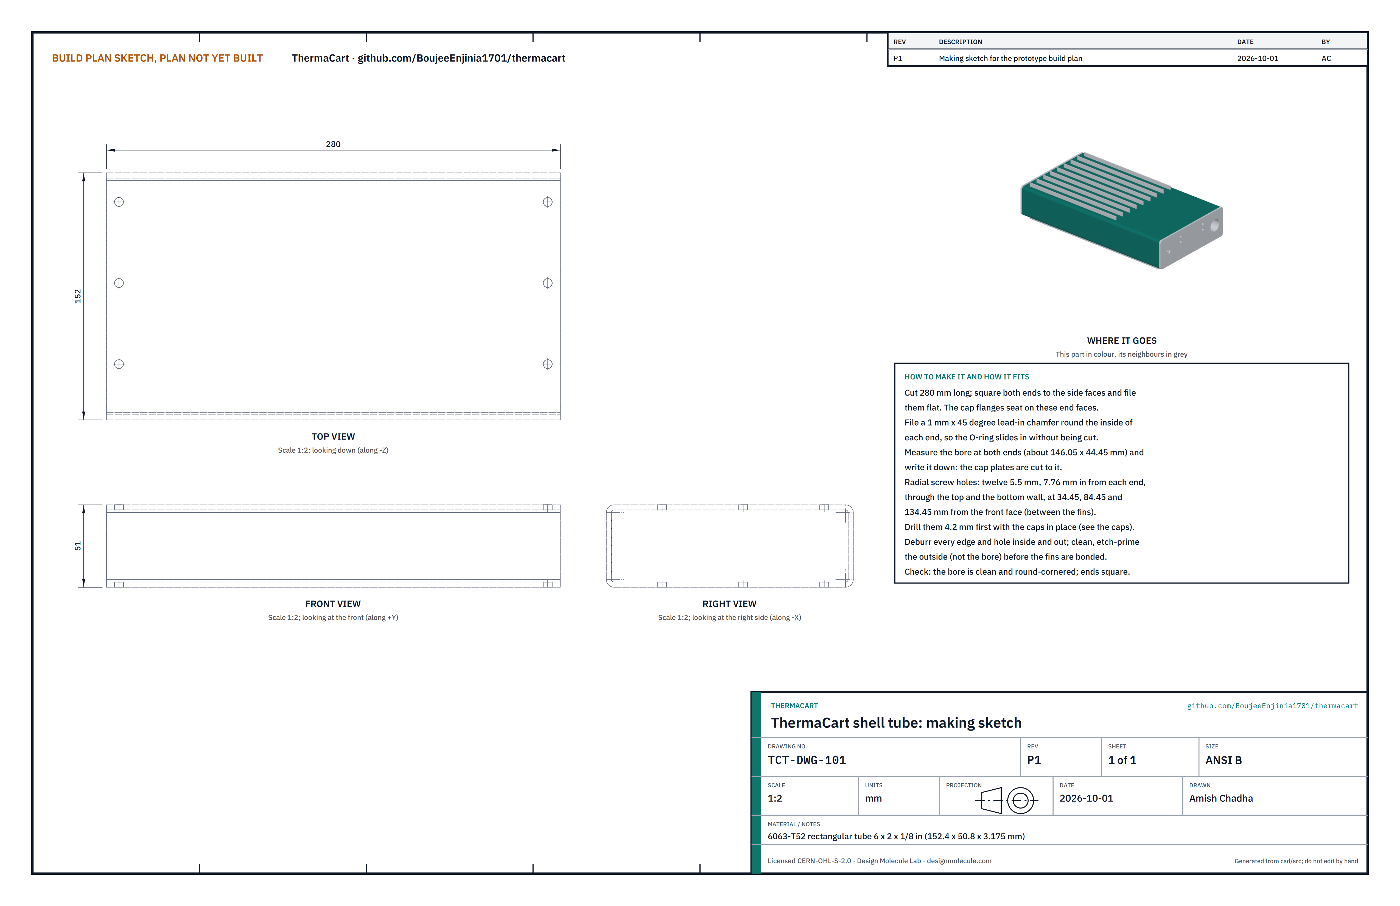
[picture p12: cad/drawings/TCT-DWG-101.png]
Figure 2. Making sketch of the shell tube


*Figure 2. Shell tube making sketch (TCT-DWG-101).*

**What it is and what it is made from.** The body of the cartridge, which holds the paraffin. 6063-T52 aluminium rectangular tube 152.4 x 50.8 mm with a 3.175 mm wall (6 x 2 x 1/8 in), cut to 280 mm.

**How to make it.**

1. Saw the tube to 280 mm. File both ends flat and square to the side faces: the cap flanges seat on them.
2. File a 1 mm lead-in chamfer round the inside of each end so the O-ring slides in without being cut.
3. Measure the bore at both ends with calipers (about 146.05 x 44.45 mm) and write it down; the cap plates are cut to it.
4. Mark the twelve radial screw holes: 7.76 mm in from each end, on the top and on the bottom wall, at 34.45, 84.45 and 134.45 mm from the front face. Centre punch them; they are drilled in section 3.3, with the caps in place.
5. Deburr every edge inside and out. Clean the outside with a solvent degreaser and etch-prime it (not the bore and not the end faces) ready for the fins.

**How it fits the parts next to it.** The fins bond to its top and bottom faces (Figure 4); the cap stacks slide into its ends until their flanges meet the end faces (Figure 7).

**Check before moving on.** Both ends square within 0.5 mm; the bore clean, its corners smooth.

### 3.2 Fins (make 9 long and 9 short)

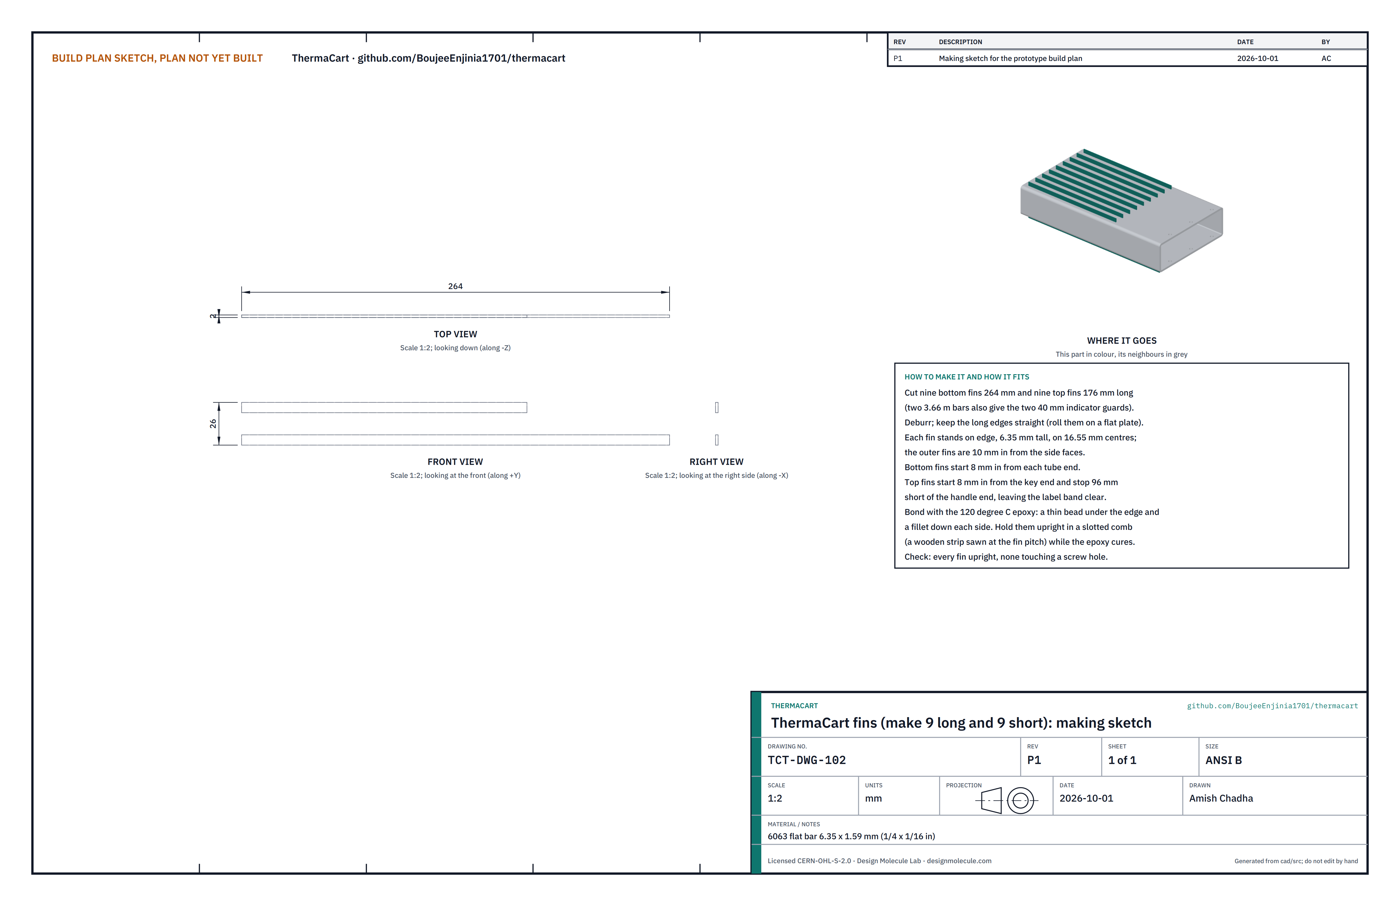
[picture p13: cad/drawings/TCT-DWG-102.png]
Figure 3. Making sketch of the fins


*Figure 3. Fin making sketch (TCT-DWG-102).*

**What it is and what it is made from.** Thin strips standing on edge on the top and bottom faces, which give the cartridge 44 % more outside area for heat to flow in and out. 6063 aluminium flat bar 6.35 x 1.59 mm (1/4 x 1/16 in).

**How to make it.**

1. Cut nine bottom fins 264 mm long and nine top fins 176 mm long from two 3.66 m bars. Keep two 40 mm offcuts for the indicator guards (section 3.9).
2. Deburr the ends and roll each strip on a flat plate to straighten it.
3. Make a comb: a wooden strip with nine saw cuts 1.6 mm wide on 16.55 mm centres, the outer cuts 10 mm in from the tube's side faces.

**How it fits the parts next to it.**

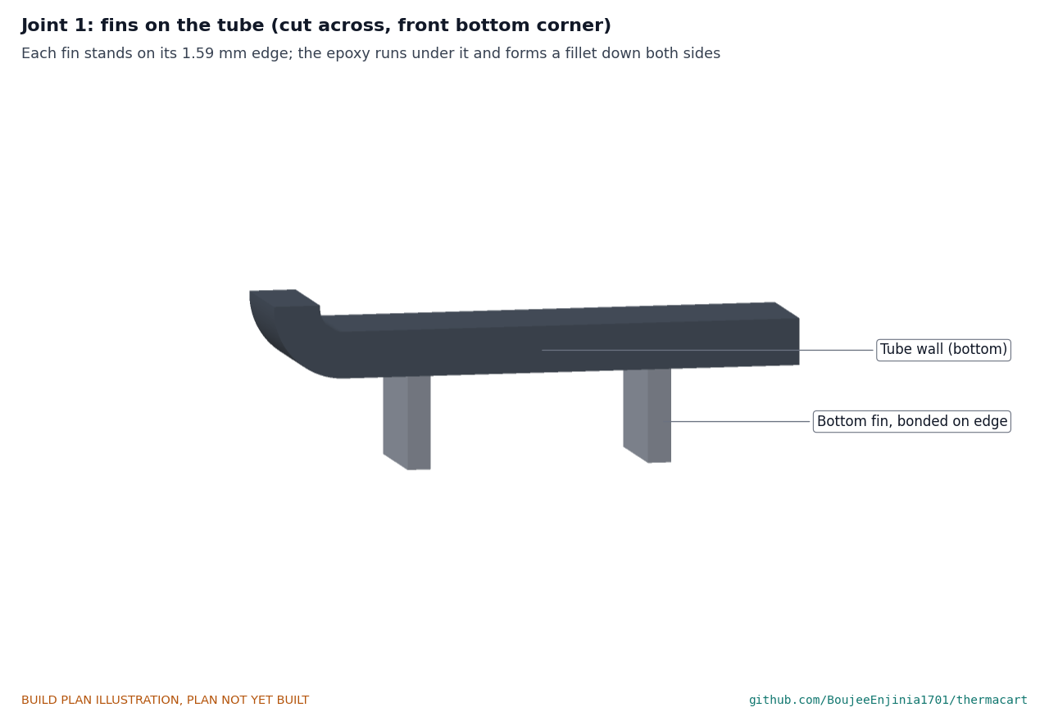
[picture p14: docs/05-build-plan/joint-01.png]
Figure 4. Joint 1: fins on the tube


*Figure 4. Each fin stands on its edge on the tube face; the epoxy runs under it and forms a fillet down both sides.*

The bottom fins start 8 mm in from each tube end. The top fins start 8 mm in from the key end and stop 96 mm short of the handle end, which leaves the label band bare. Each is bonded with the 120 °C structural epoxy: a thin bead under the edge and a fillet about 2 mm high down each side, the fins held upright in the comb while the epoxy cures.

**Check before moving on.** Every fin upright and straight; no fin over a screw hole mark.

### 3.3 Key-end cap stack

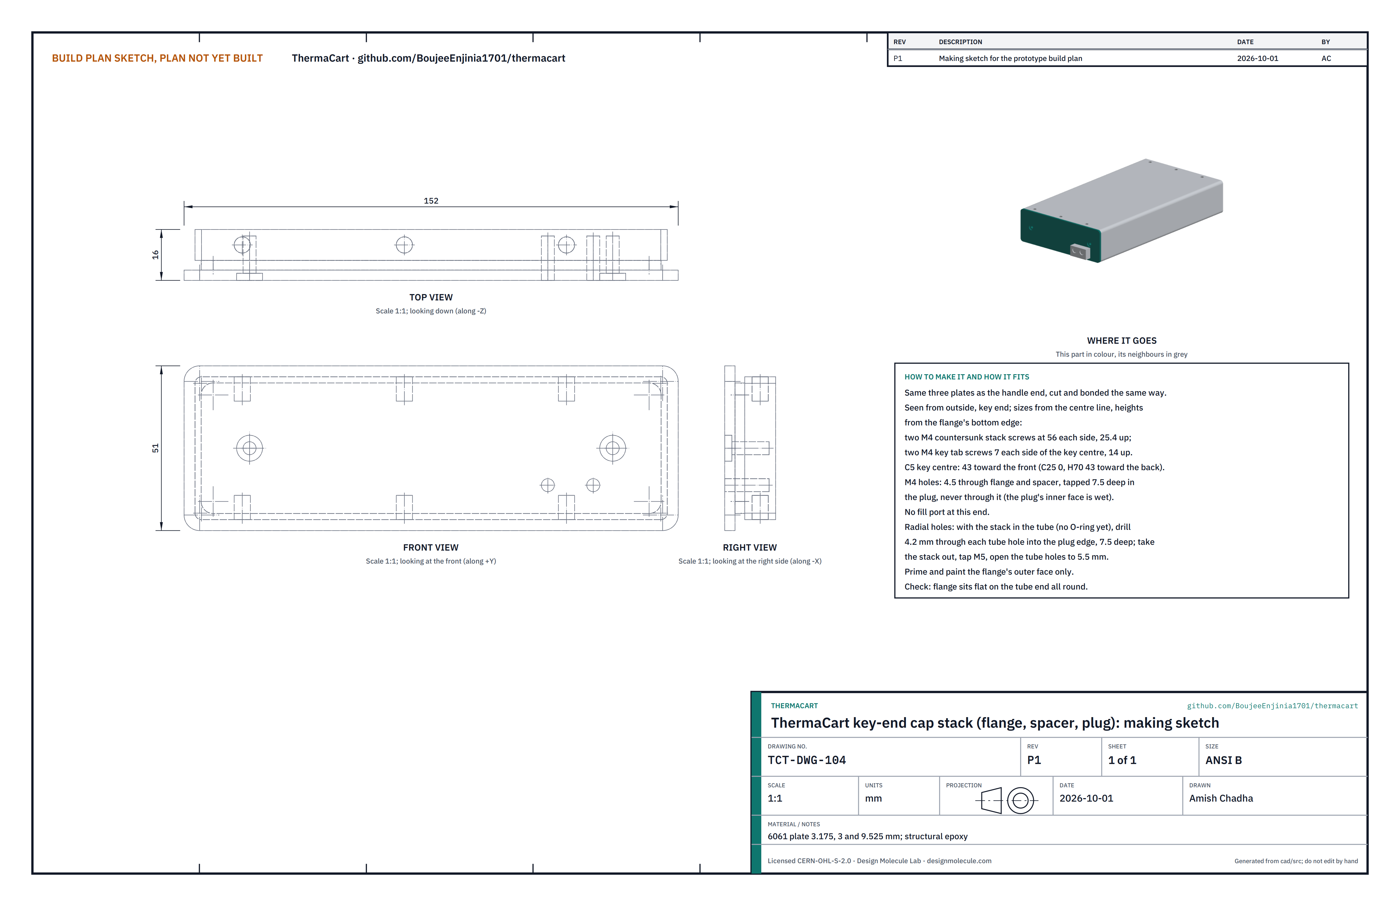
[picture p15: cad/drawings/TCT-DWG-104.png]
Figure 5. Making sketch of the key-end cap stack


*Figure 5. Key-end cap stack making sketch (TCT-DWG-104).*

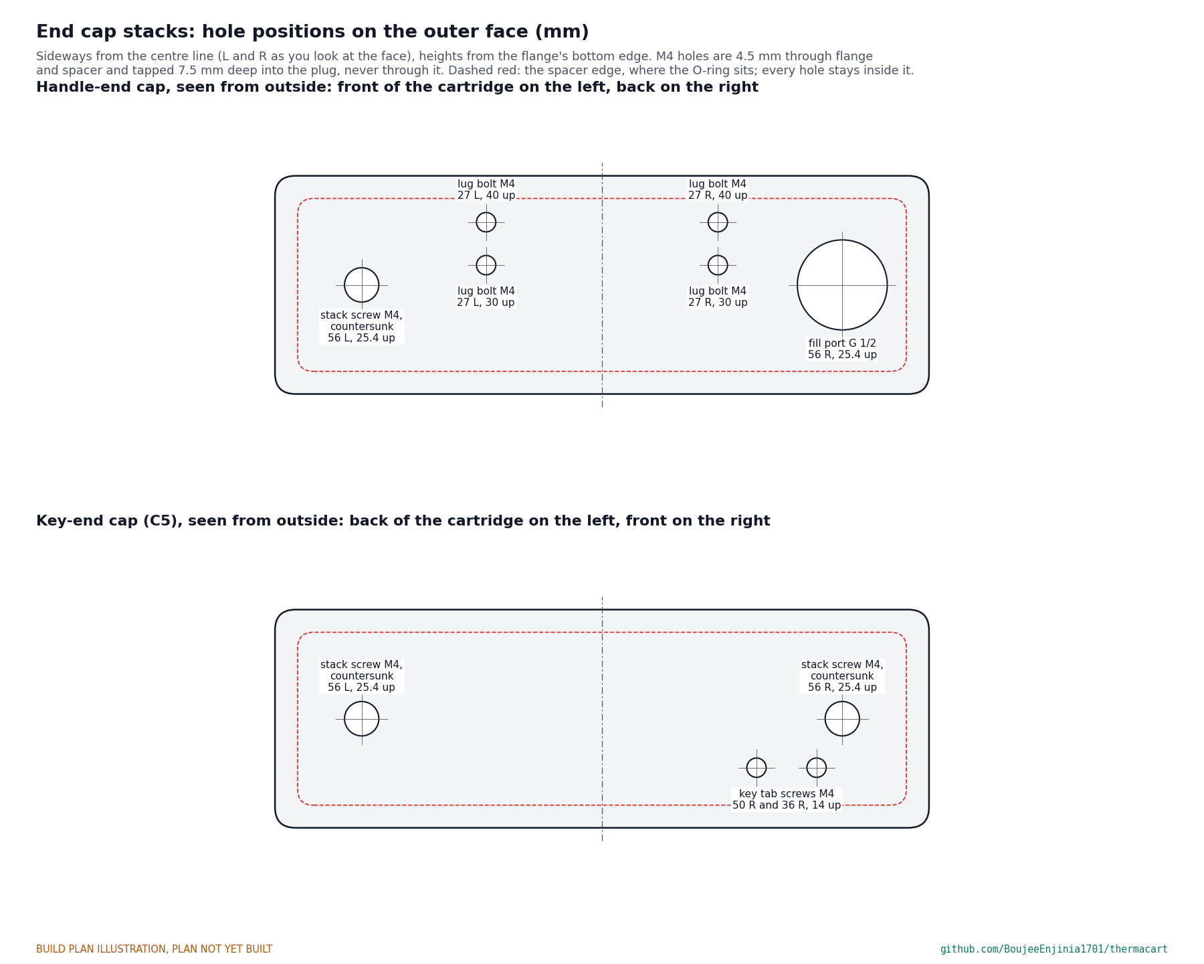
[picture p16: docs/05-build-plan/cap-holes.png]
Figure 6. Hole positions on both cap stacks


*Figure 6. Hole positions on the outer face of each cap stack.*

**What it is and what it is made from.** The closure at the key end: a flange that sits on the tube end, a thin gland spacer that the O-ring goes round, and a thick plug that fills the tube end, bonded into one block. 6061 aluminium plate 3.175, 3 and 9.525 mm thick, and the structural epoxy. Both cap stacks are made the same way; this one has no fill port.

**How to make it.**

1. Cut the flange to 152.4 x 50.8 mm and round its corners to 4.8 mm, to match the outside of the tube.
2. Cut the gland spacer to the measured bore less 4.2 mm each way (about 141.85 x 40.25 mm), corners rounded to 3.7 mm.
3. Cut the plug to the measured bore less 0.4 mm each way (about 145.65 x 44.05 mm), corners rounded to 2 mm. Try it in the tube end: it should slide in with a little play all round.
4. Abrade and clean the faces, then bond spacer and plug to the flange with the epoxy over their whole faces, centred, and clamp until cured. The epoxy also seals the joint lines.
5. Mark the holes from Figure 6, measured from the centre line and up from the flange's bottom edge: two stack screws 56 mm each side, 25.4 mm up; two key tab screws 36 and 50 mm toward the front, 14 mm up (for the C5 key).
6. Drill each hole 3.3 mm through flange and spacer and 7.5 mm into the plug, never through it: the plug's inner face touches the paraffin. Open the holes in flange and spacer to 4.5 mm and tap the plug M4. Countersink the two stack screw holes in the flange and fit two M4 x 12 countersunk screws with thread sealant.
7. Put the stack in the tube's key end without its O-ring and clamp it. Drill 4.2 mm through each of the six marked holes in the tube walls into the plug edge, 7.5 mm deep. Take the stack out, tap the plug holes M5 and open the tube holes to 5.5 mm. Deburr.
8. Mask the spacer, the plug and the flange's inner face, then prime and paint the flange's outer face only.

**How it fits the parts next to it.**

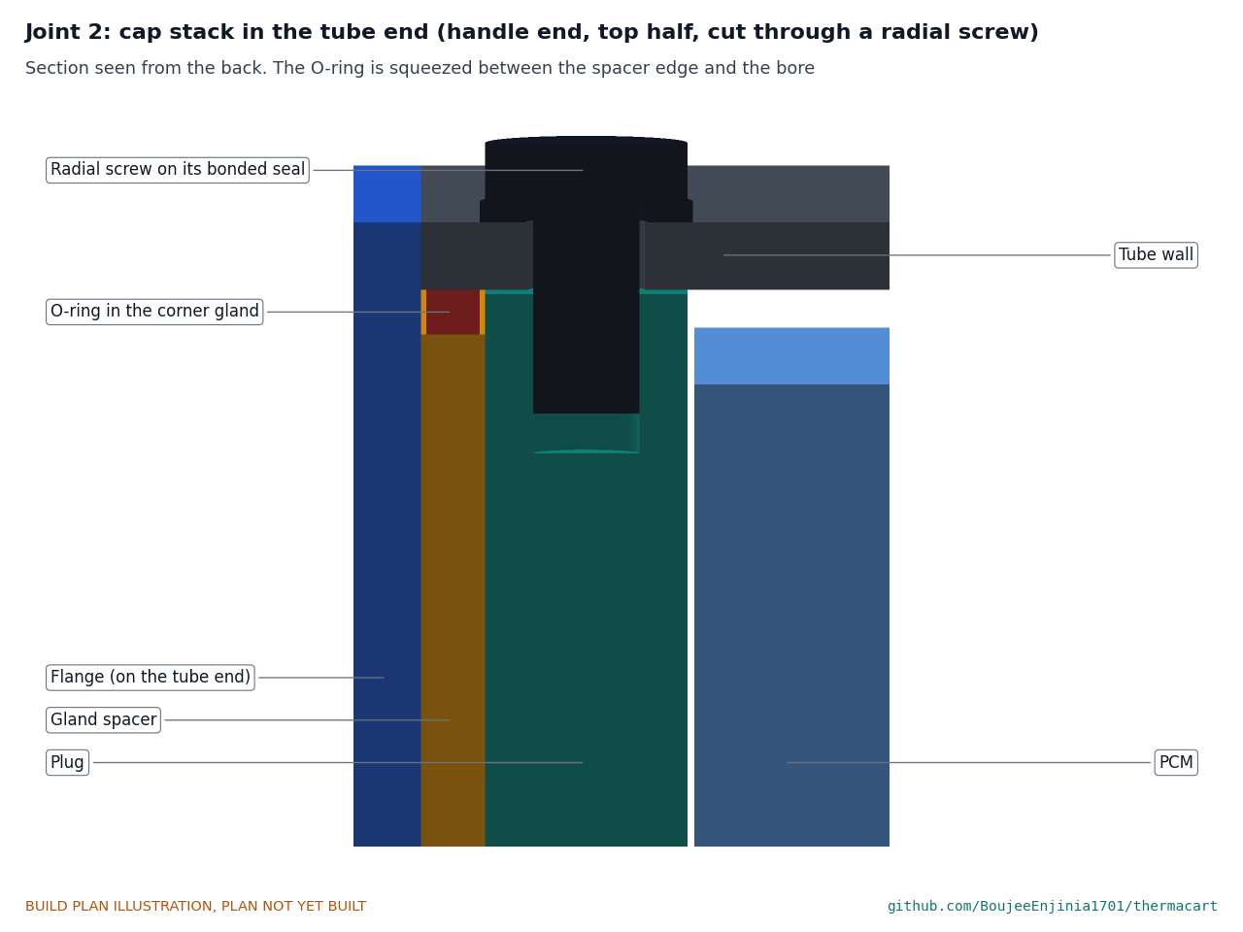
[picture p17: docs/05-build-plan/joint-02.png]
Figure 7. Joint 2: the cap stack in the tube end


*Figure 7. Section through the handle end; the key end is the same. The O-ring is squeezed between the spacer edge and the bore; the flange stops on the tube end.*

The flange sits flat on the tube end all round. The O-ring, a 2.5 mm FKM cord spliced into a loop, sits round the spacer and is squeezed 0.4 mm between the spacer edge and the bore. The plug is 0.2 mm clear of the bore.

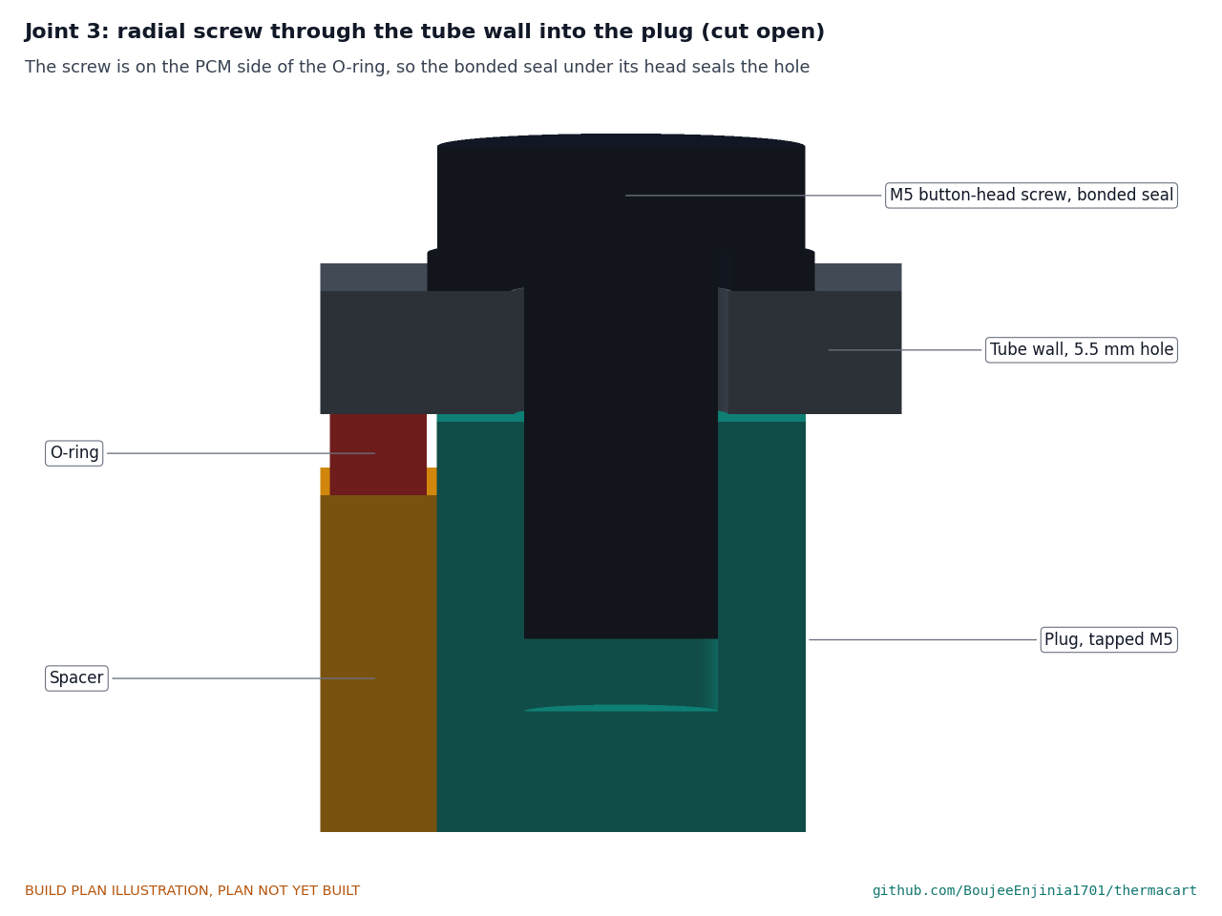
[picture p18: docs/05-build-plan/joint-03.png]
Figure 8. Joint 3: a radial screw


*Figure 8. Six radial screws hold each cap: through the tube wall into the plug edge, each on a bonded sealing washer.*

**Check before moving on.** Without its O-ring the stack slides in until the flange meets the tube end, and all six tube holes line up with the tapped holes.

### 3.4 Key tab

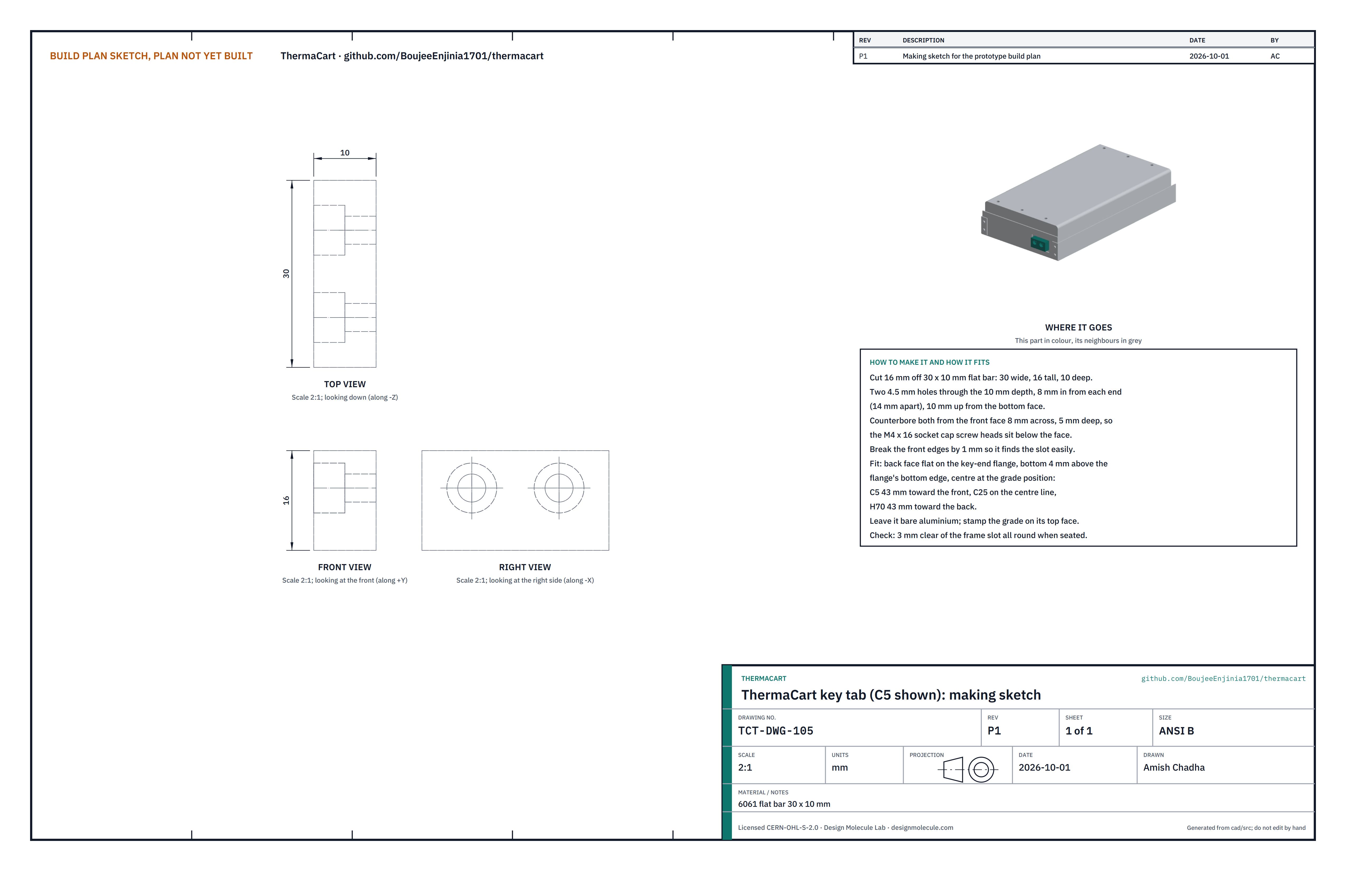
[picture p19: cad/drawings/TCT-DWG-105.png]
Figure 9. Making sketch of the key tab


*Figure 9. Key tab making sketch (TCT-DWG-105).*

**What it is and what it is made from.** The block on the nose whose position across the cartridge codes its grade, so that only the right frame accepts it. 6061 aluminium flat bar 30 x 10 mm.

**How to make it.**

1. Cut a 16 mm length of the bar: the tab is 30 wide, 16 tall and 10 deep.
2. Drill two 4.5 mm holes through the 10 mm depth, 8 mm in from each end (14 mm apart) and 10 mm up from the bottom face.
3. Counterbore both holes from the front face, 8 mm across and 5 mm deep.
4. Break the front edges by 1 mm so the tab finds the frame slot easily. Stamp "C5" on its top face; leave it bare.

**How it fits the parts next to it.**

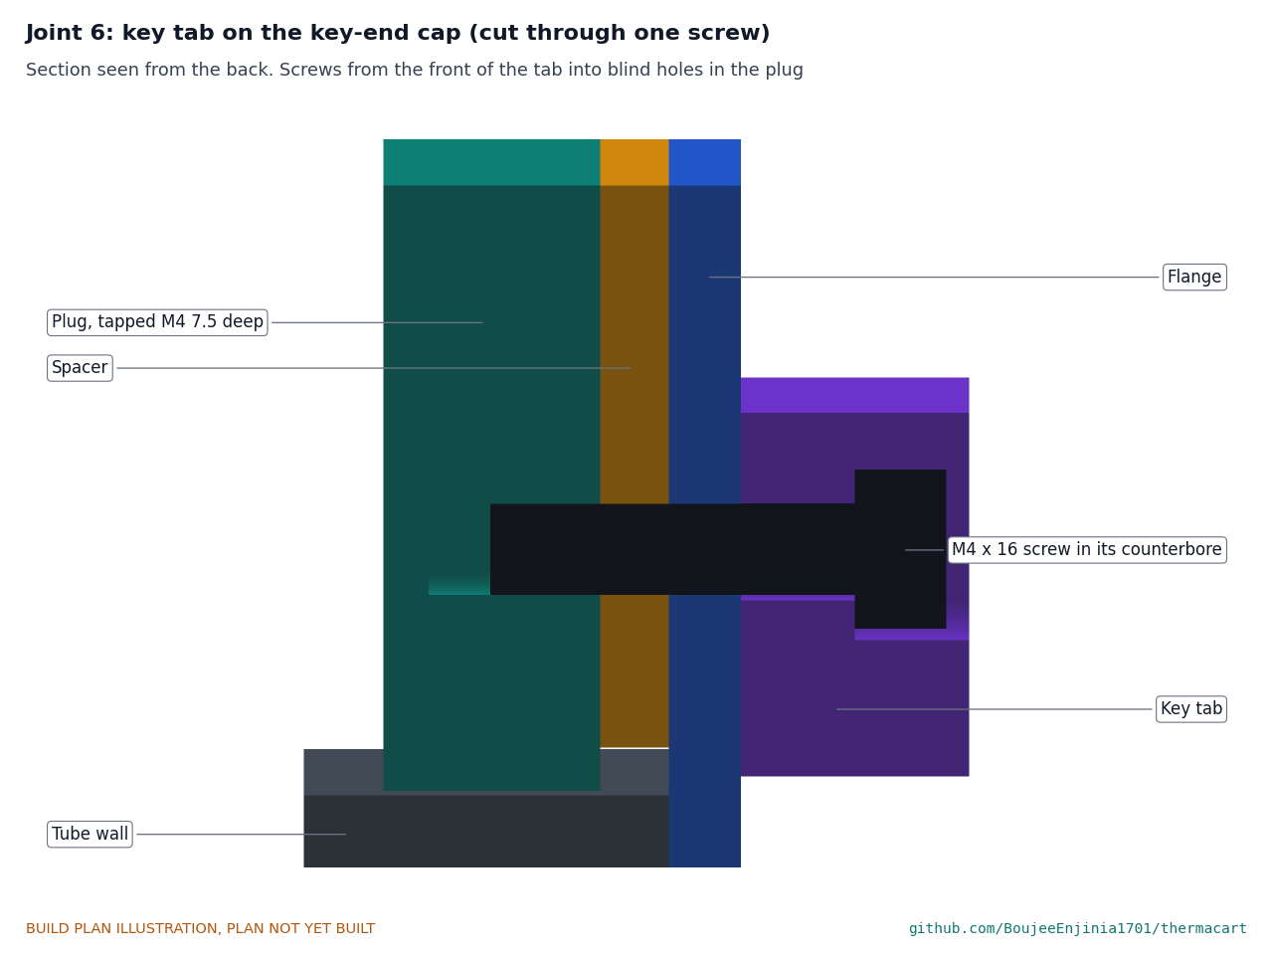
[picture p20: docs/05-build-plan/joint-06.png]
Figure 10. Joint 6: key tab on the key-end cap


*Figure 10. Section through one key screw: from the front of the tab, through flange and spacer, into a blind hole in the plug.*

The back face sits flat on the key-end flange, its bottom 4 mm above the flange's bottom edge and its centre 43 mm toward the front (the C5 position; C25 is on the centre line and H70 is 43 mm toward the back). Two M4 x 16 socket cap screws with thread sealant hold it; their heads sit 1 mm below the front face.

**Check before moving on.** The tab is square to the flange and the screw heads are below its face.

### 3.5 Handle-end cap stack

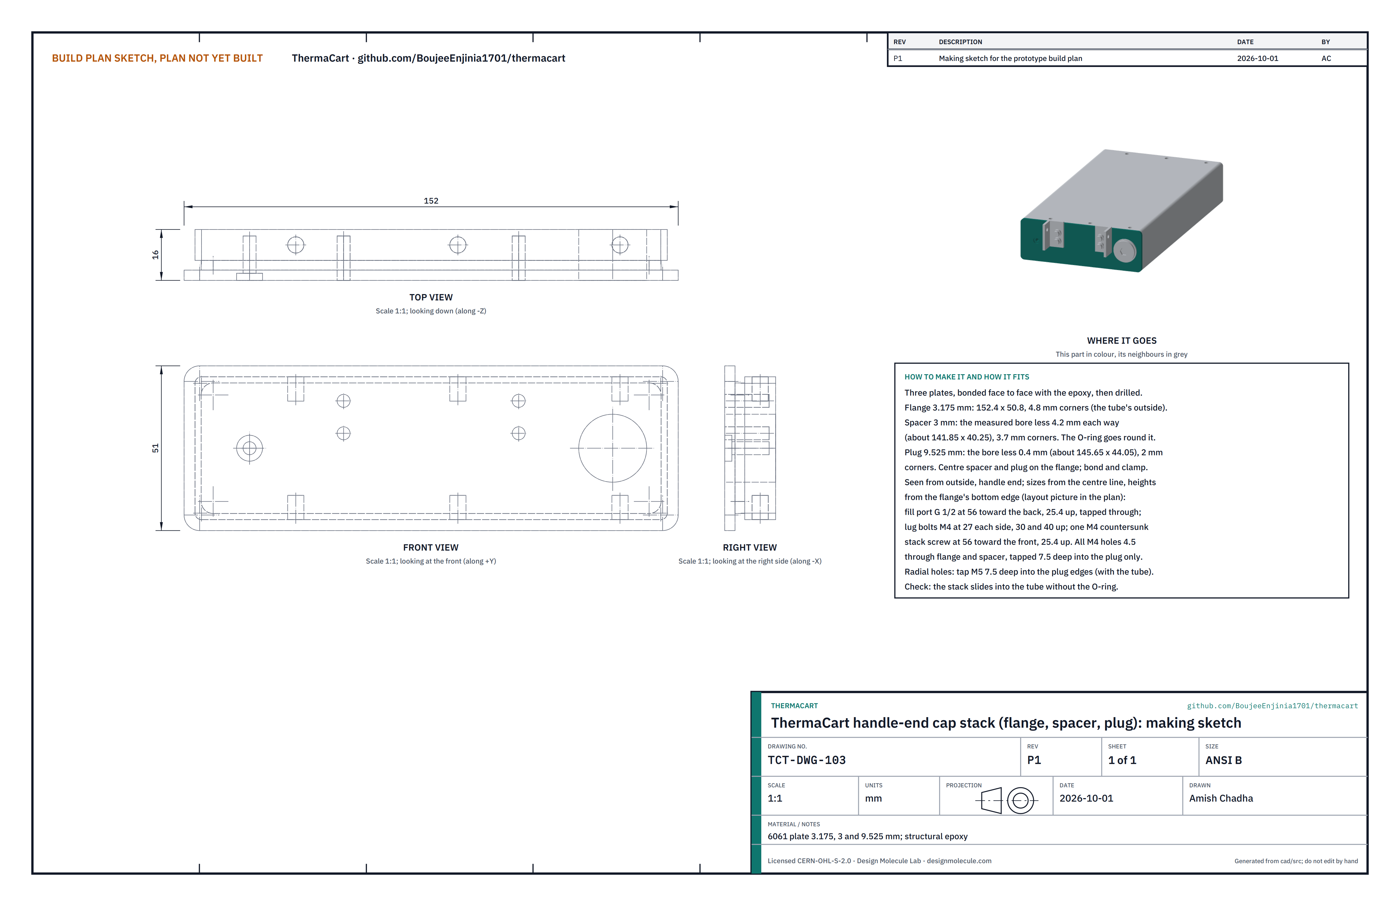
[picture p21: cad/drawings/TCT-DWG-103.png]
Figure 11. Making sketch of the handle-end cap stack


*Figure 11. Handle-end cap stack making sketch (TCT-DWG-103).*

**What it is and what it is made from.** The closure at the handle end, made like the key-end stack (section 3.3), which also carries the fill port and the bail.

**How to make it.**

1. Cut and bond the three plates as section 3.3, steps 1 to 4.
2. Mark the holes from Figure 6 (handle end, seen from outside): the fill port 56 mm toward the back, 25.4 mm up; four lug bolt holes 27 mm each side of the centre line, 30 and 40 mm up; one stack screw 56 mm toward the front, 25.4 mm up.
3. Drill the fill port through the whole stack with the G 1/2 tapping drill (18.6 mm) and tap it G 1/2 straight through. Spot-face the flange round it so the bonded seal sits flat.
4. Drill and tap the lug bolt and stack screw holes as section 3.3, step 6: 4.5 mm through flange and spacer, M4 7.5 mm deep in the plug. Fit the countersunk stack screw.
5. Drill the six radial holes with the stack in the handle end of the tube, as section 3.3, step 7.
6. Paint the flange's outer face as section 3.3, step 8, masking a 30 mm circle round the fill port.

**How it fits the parts next to it.** It fits the tube exactly as the key-end stack does (Figures 7 and 8). The fill plug seals on the flange face:

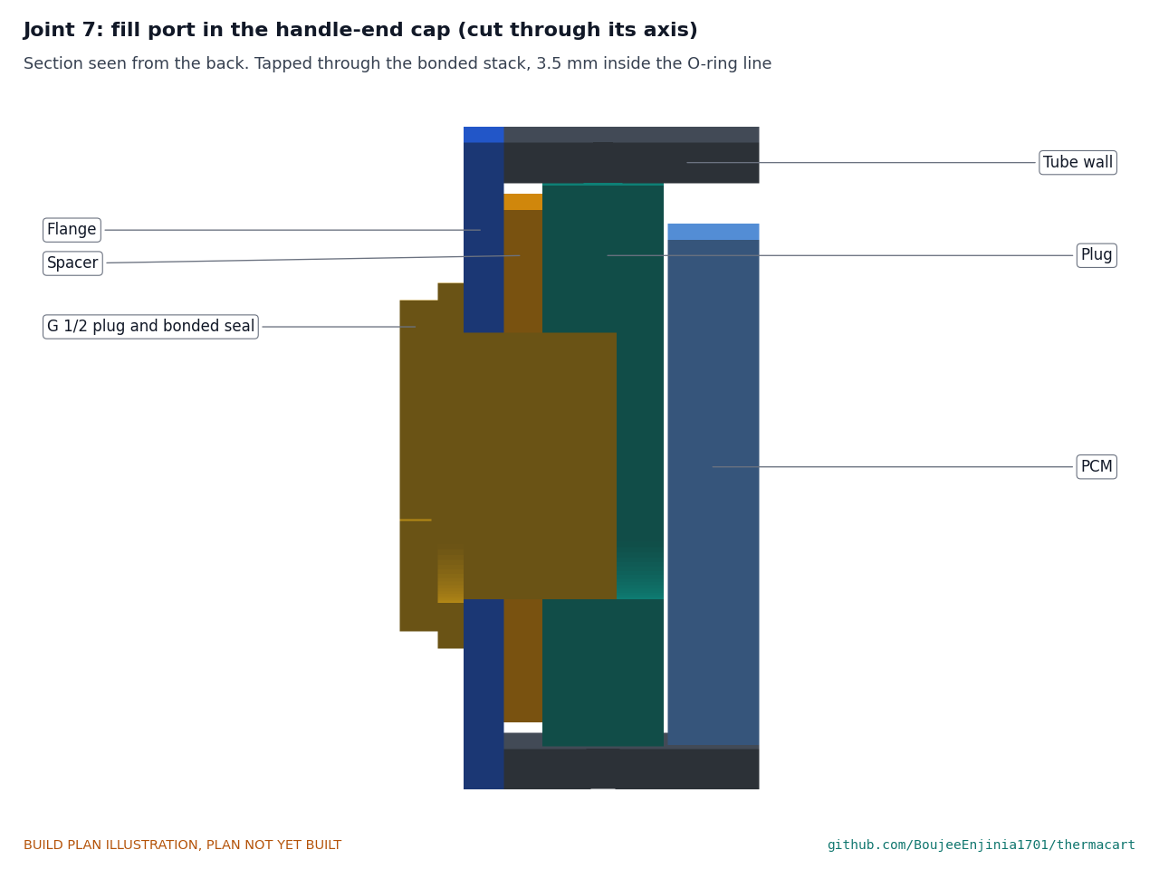
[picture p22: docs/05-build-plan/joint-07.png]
Figure 12. Joint 7: the fill port


*Figure 12. Section through the fill port. The plug's bonded seal sits on the flange; its thread is 3.5 mm inside the O-ring line.*

**Check before moving on.** A G 1/2 plug screws in by hand all the way; the lug bolt holes are blind (a wire does not pass into the tube).

### 3.6 Lug angles (make 2, a left and a right)

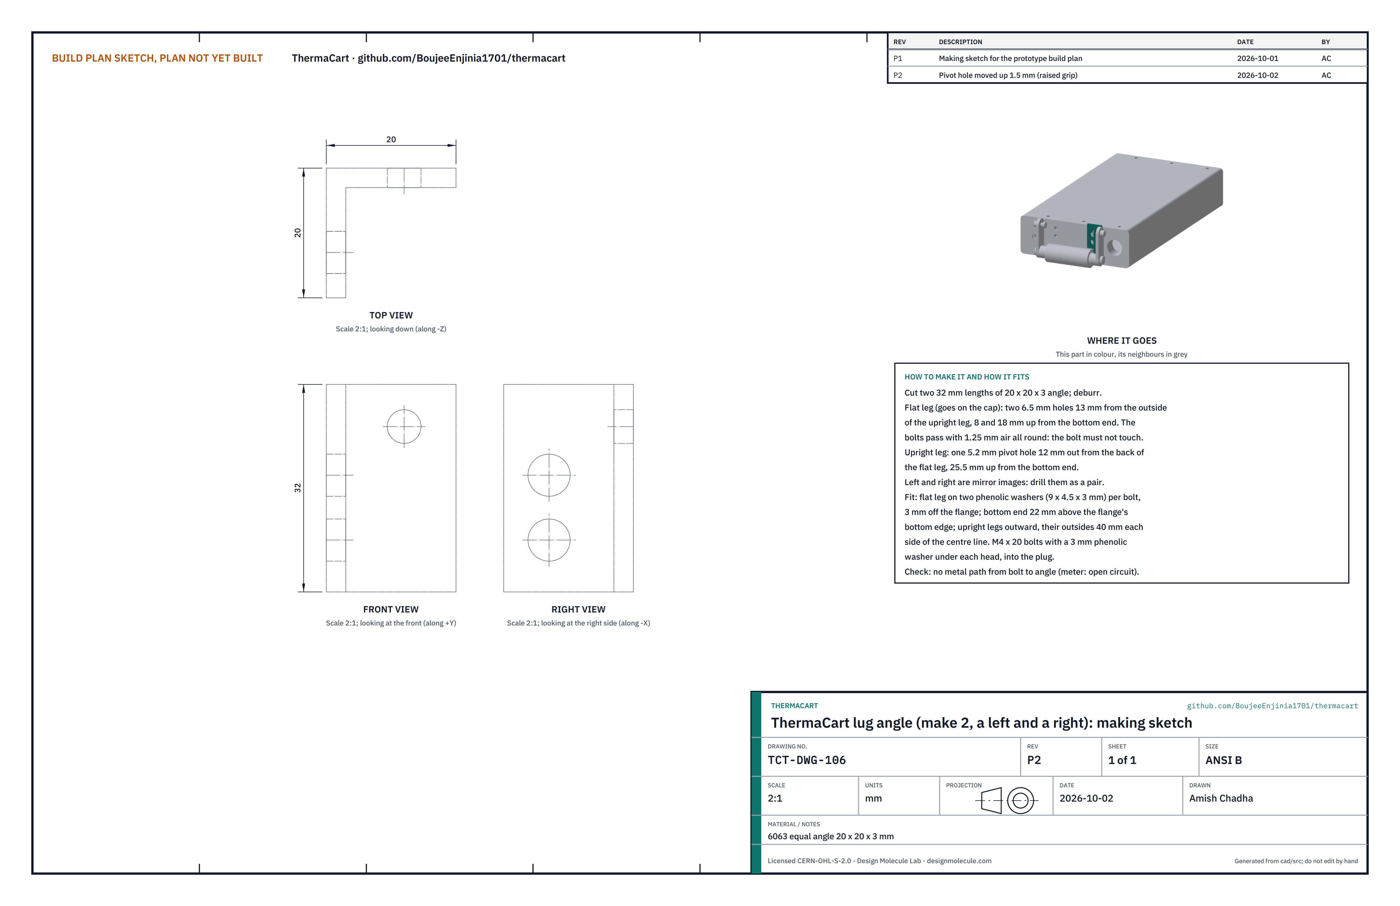
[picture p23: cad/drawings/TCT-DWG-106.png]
Figure 13. Making sketch of the lug angle


*Figure 13. Lug angle making sketch (TCT-DWG-106).*

**What it is and what it is made from.** The two brackets the bail swings on, bolted to the handle-end cap through a thermal break so the bail stays cool when the cartridge is hot. 6063 aluminium equal angle 20 x 20 x 3 mm.

**How to make it.**

1. Cut two 32 mm lengths and deburr them.
2. Flat leg (the one that goes against the cap): two 6.5 mm holes, 13 mm from the outside face of the upright leg, 8 and 18 mm up from the bottom end.
3. Upright leg: one 5.2 mm pivot hole, 12 mm out from the back of the flat leg and 25.5 mm up from the bottom end.
4. The two are mirror images: clamp them back to back and drill them together.

**How it fits the parts next to it.**

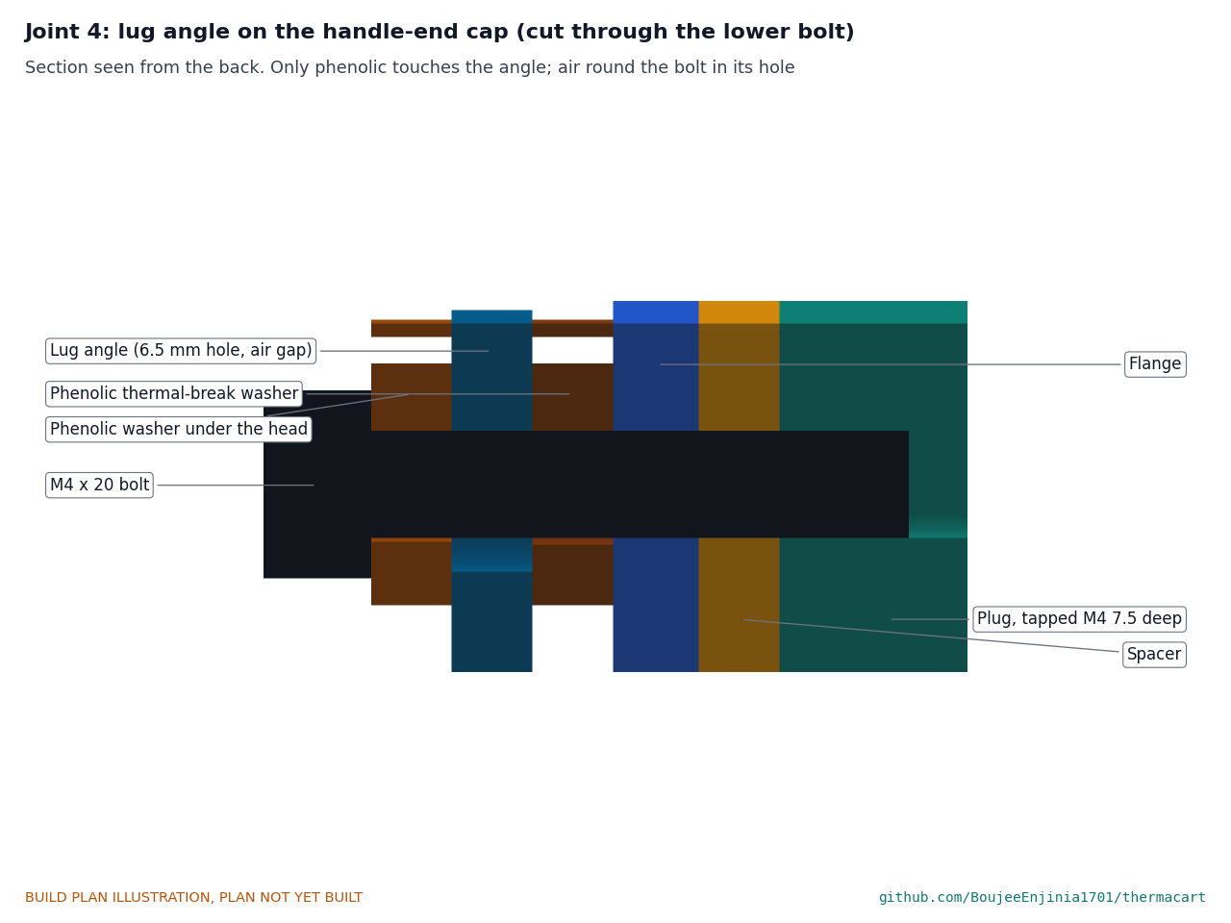
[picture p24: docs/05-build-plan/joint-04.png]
Figure 14. Joint 4: lug angle on the handle-end cap


*Figure 14. Section through one lug bolt. Only phenolic touches the angle: two washers under it and one under the bolt head, and air round the bolt.*

Each angle stands 3 mm off the flange on two phenolic washers (9 mm across, 4.5 mm hole, 3 mm thick), its bottom end 22 mm above the flange's bottom edge and the outside of its upright leg 40 mm from the centre line, upright legs facing outward. Two M4 x 20 socket cap screws, each with a 3 mm phenolic washer under its head, pass through the 6.5 mm holes with 1.25 mm of air all round and screw into the plug with thread sealant. The bolt must not touch the angle: that would carry heat straight into the bail.

**Check before moving on.** With a meter, no continuity between each bolt head and its angle.

### 3.7 Bail arms (make 2)

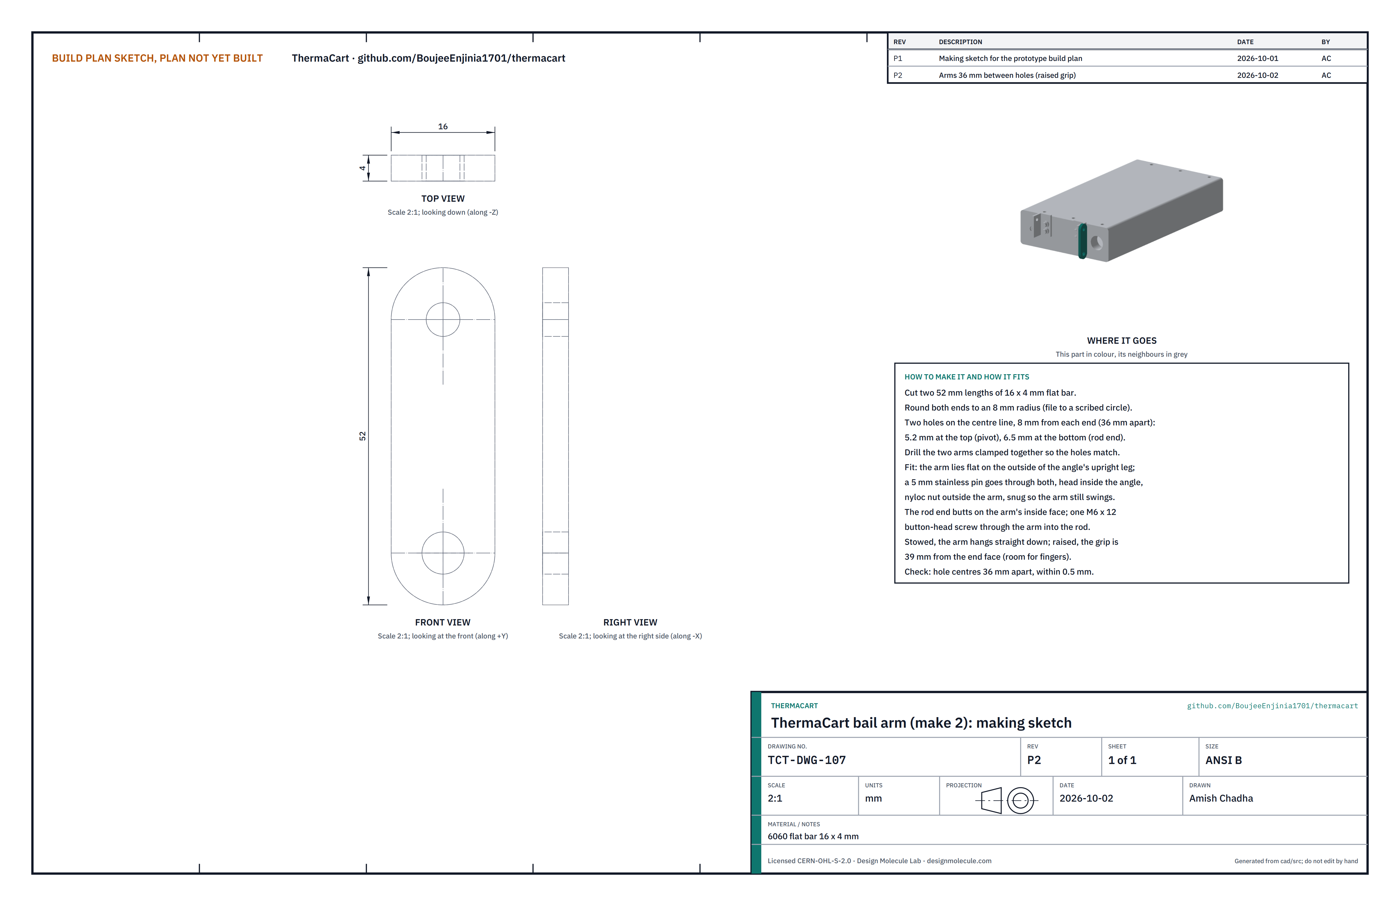
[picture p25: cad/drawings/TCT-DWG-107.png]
Figure 15. Making sketch of the bail arm


*Figure 15. Bail arm making sketch (TCT-DWG-107).*

**What it is and what it is made from.** The two side links of the folding bail. 6060 aluminium flat bar 16 x 4 mm.

**How to make it.**

1. Cut two 52 mm lengths and round both ends to an 8 mm radius.
2. Drill two holes on the centre line, 8 mm from each end (36 mm apart): 5.2 mm at the top (the pivot) and 6.5 mm at the bottom (the rod end). Drill the two arms clamped together.

**How it fits the parts next to it.**

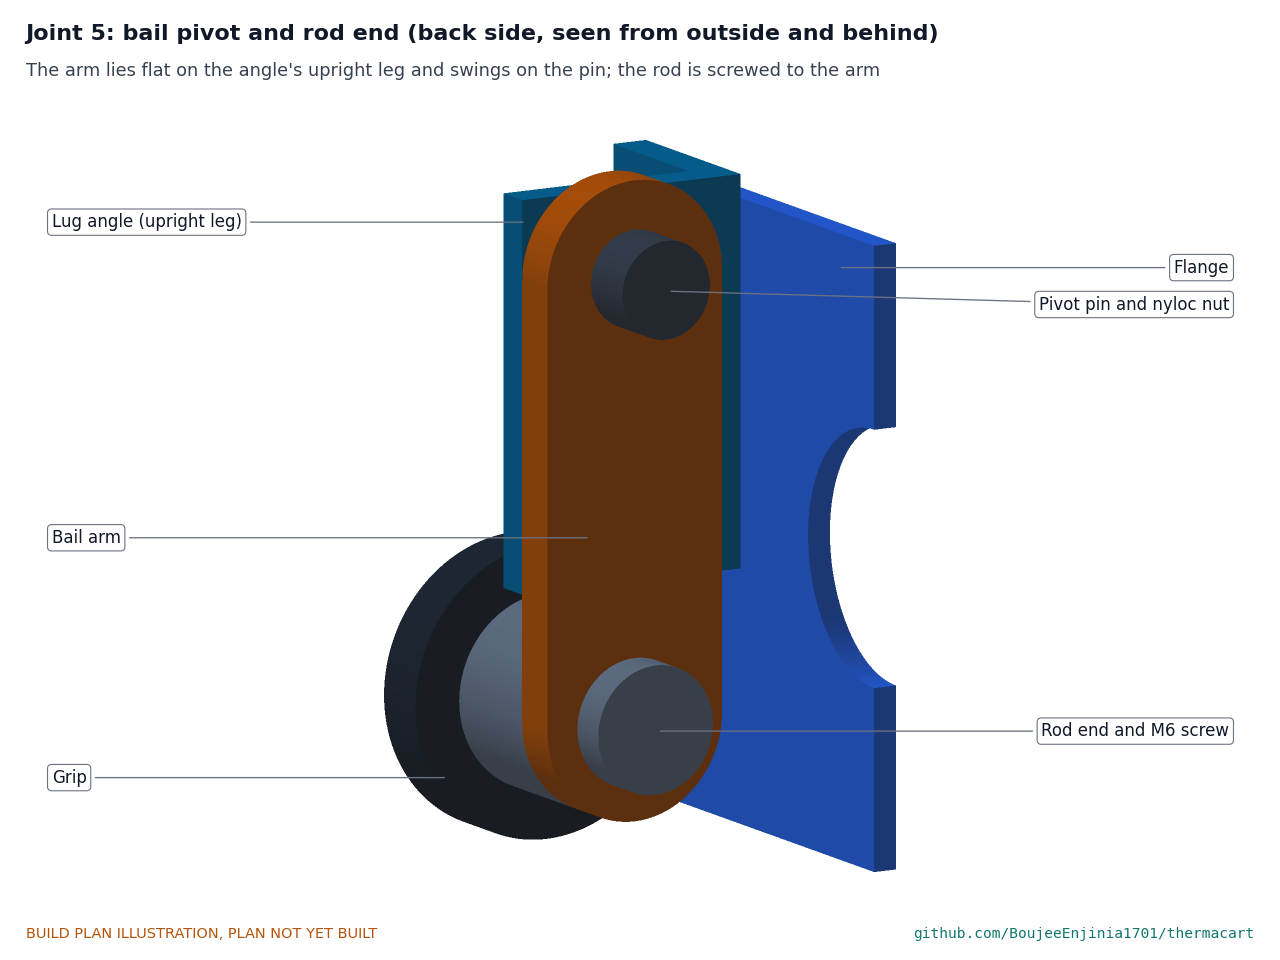
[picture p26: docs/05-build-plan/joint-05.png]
Figure 16. Joint 5: bail pivot and rod end


*Figure 16. The arm lies flat on the outside of the angle's upright leg and swings on the pin; the rod is screwed to the arm.*

A 5 mm stainless pin passes through the angle and the arm, its head inside the angle and a nyloc nut outside the arm, snug enough that the arm still swings. The rod end butts on the arm's inside face and an M6 x 12 button-head screw through the arm holds it. Stowed, the arm hangs straight down; swung out level, the grip is 39 mm from the end face, room for fingers.

**Check before moving on.** Hole centres 36 mm apart, within 0.5 mm, on both arms.

### 3.8 Bail rod

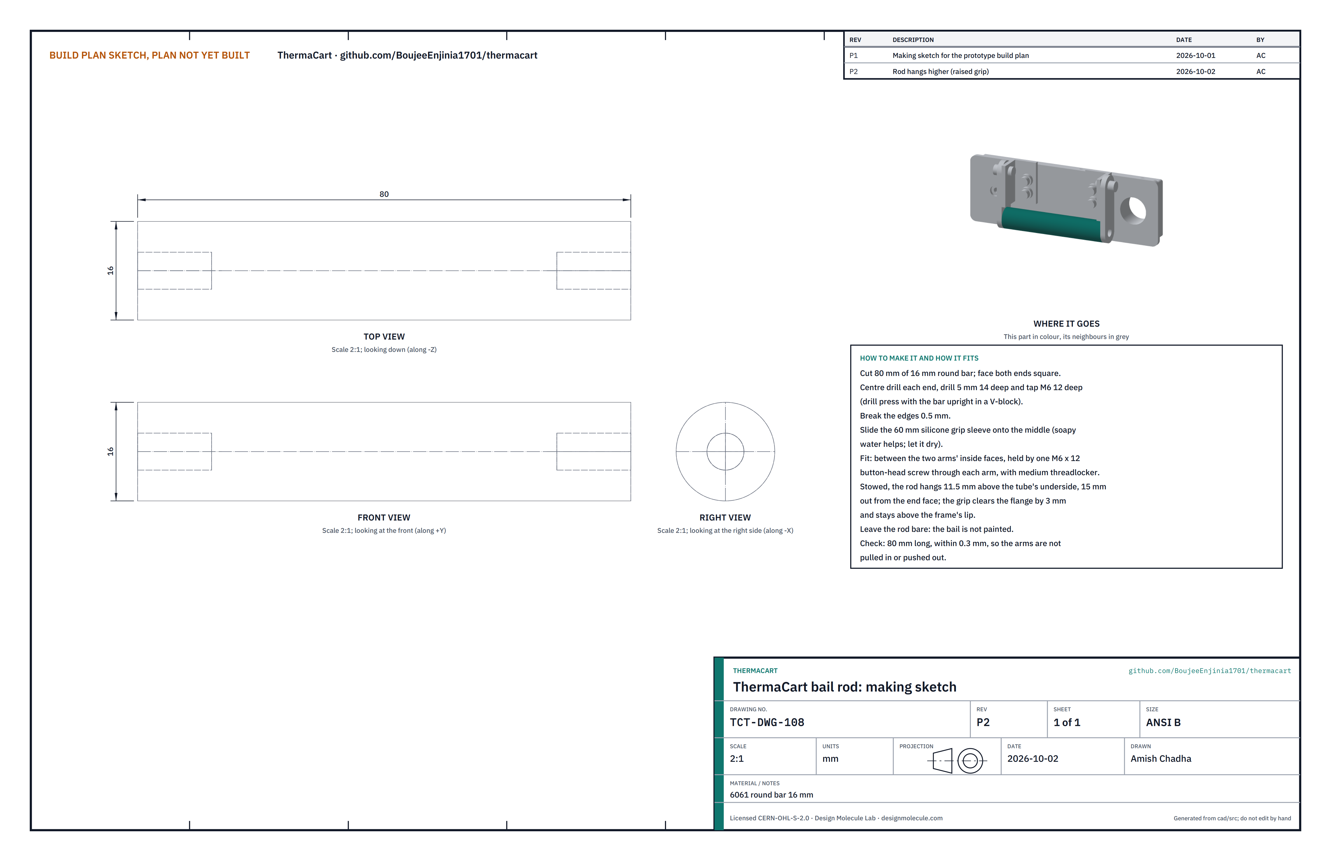
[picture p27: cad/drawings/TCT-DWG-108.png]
Figure 17. Making sketch of the bail rod


*Figure 17. Bail rod making sketch (TCT-DWG-108).*

**What it is and what it is made from.** The handle the user holds, with a silicone grip. 6061 aluminium round bar 16 mm and a silicone sleeve 24 mm outside, 60 mm long.

**How to make it.**

1. Cut 80 mm of bar and face both ends square.
2. With the bar upright in a V-block in the drill press, centre drill each end, drill 5 mm 14 mm deep and tap M6 12 mm deep.
3. Break the edges by 0.5 mm. Slide the grip sleeve onto the middle with soapy water and let it dry. Leave the rod bare: the bail is not painted.

**How it fits the parts next to it.** Between the arms' inside faces on two M6 x 12 button-head screws with medium threadlocker (Figure 16). Stowed, it hangs 11.5 mm above the tube's underside and 15 mm out from the end face; the grip clears the flange by 3 mm, and its underside is about 2 mm higher than the top of the frame's lip, so the grip never catches on it.

**Check before moving on.** 80 mm long within 0.3 mm, so the arms are neither pulled in nor pushed out.

### 3.9 Melt indicator and guards

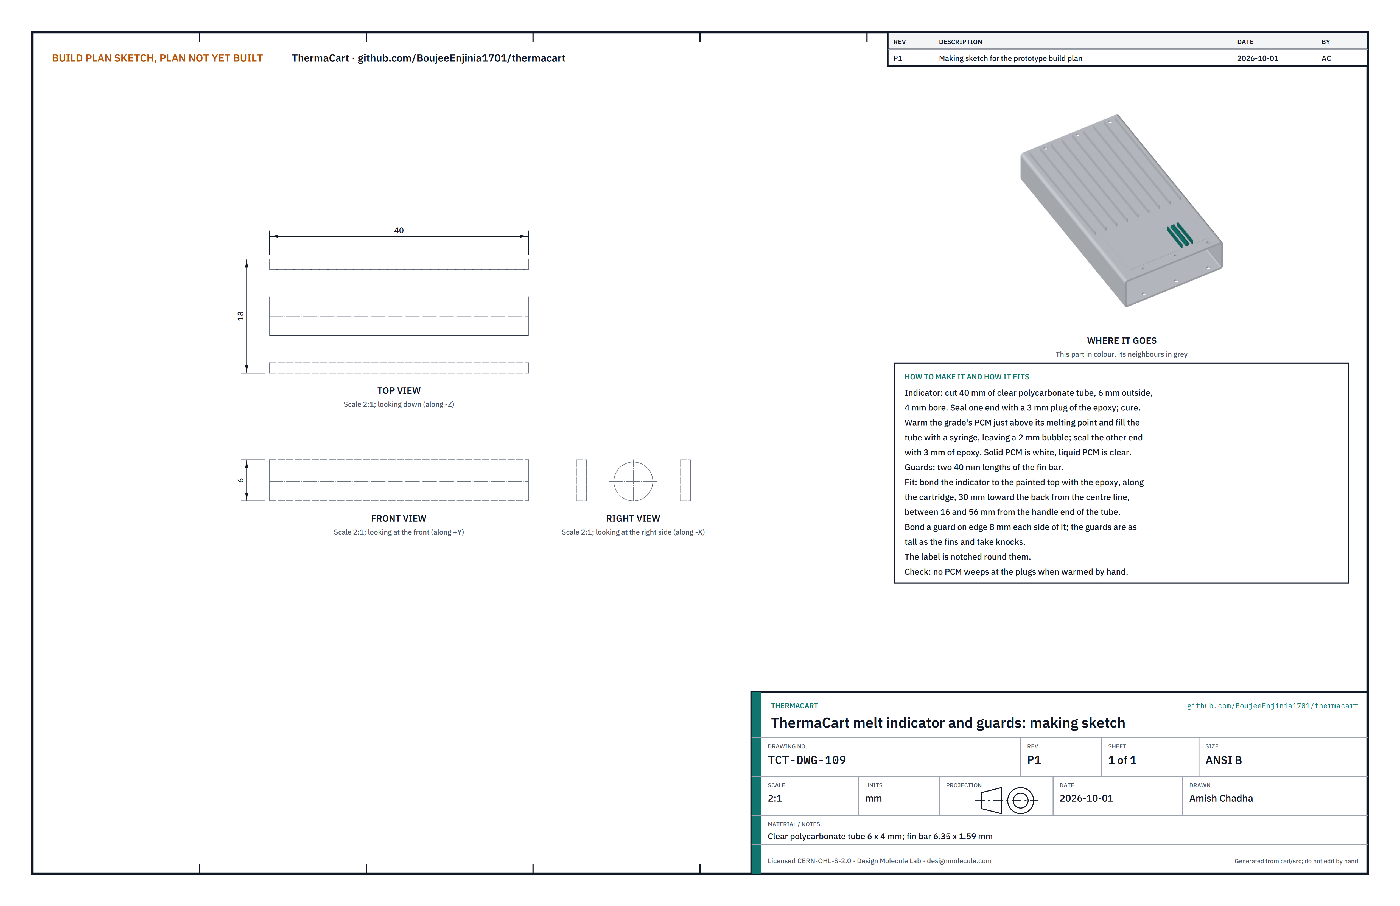
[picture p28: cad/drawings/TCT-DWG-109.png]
Figure 18. Making sketch of the melt indicator and guards


*Figure 18. Melt indicator and guards making sketch (TCT-DWG-109).*

**What it is and what it is made from.** A small sealed tube of the same paraffin on the top of the cartridge: white when it is solid (charged), clear when it has melted. Clear polycarbonate tube 6 mm outside and 4 mm bore, and two offcuts of the fin bar.

**How to make it.**

1. Cut 40 mm of the clear tube. Seal one end with a 3 mm plug of the epoxy and let it cure.
2. Warm a little of the C5 paraffin just above its melting point and fill the tube with a syringe, leaving a 2 mm bubble. Seal the other end with 3 mm of epoxy.
3. Cut the two guards: 40 mm lengths of the fin bar.

**How it fits the parts next to it.**

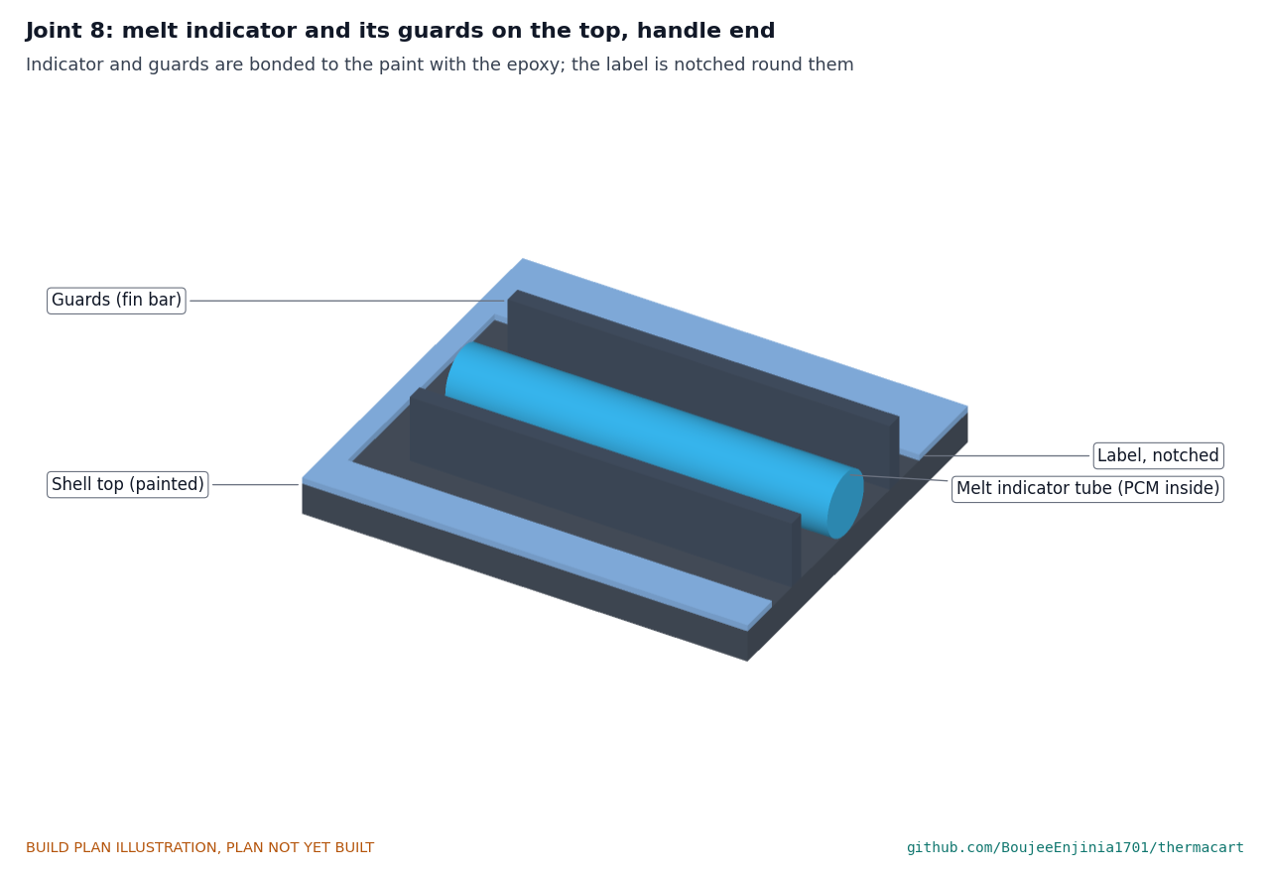
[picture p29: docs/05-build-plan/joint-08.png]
Figure 19. Joint 8: melt indicator and guards on the top


*Figure 19. The indicator and its guards are bonded to the painted top; the label is notched round them.*

The indicator lies along the cartridge on the painted top, 30 mm toward the back from the centre line, between 16 and 56 mm from the handle end of the tube, bonded with the epoxy. A guard stands on edge 8 mm each side of it, bonded the same way; the guards are as tall as the fins and take knocks.

**Check before moving on.** Warmed in the hand, the paraffin turns clear and no paraffin weeps at either plug.

### 3.10 Adapter frame

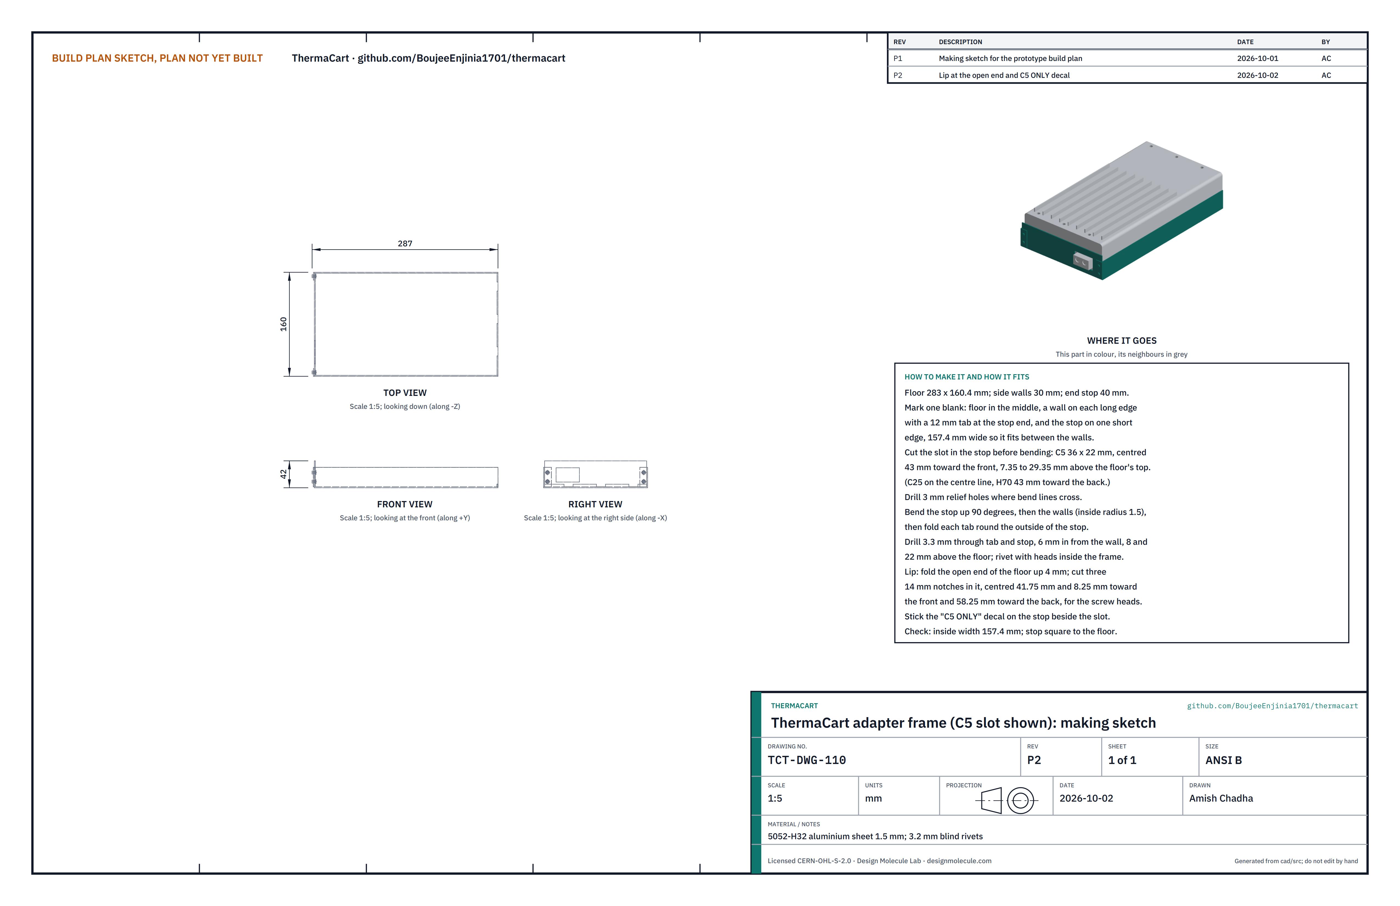
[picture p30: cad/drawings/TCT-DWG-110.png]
Figure 20. Making sketch of the adapter frame


*Figure 20. Adapter frame making sketch (TCT-DWG-110).*

**What it is and what it is made from.** The tray that goes in the host's slot and accepts only C5 cartridges. 5052-H32 aluminium sheet 1.5 mm, four 3.2 mm aluminium blind rivets and a printed "C5 ONLY" vinyl decal.

**How to make it.**

1. Mark one blank: the floor 283 x 160.4 mm in the middle, including a 4 mm strip for the lip at the open end; a 30 mm wall on each long edge, each with a 12 mm tab at the stop end; and the 40 mm stop on one short edge, 157.4 mm wide so it bends up between the walls.
2. Before bending, cut the slot in the stop: 36 mm wide and 22 mm tall, centred 43 mm toward the front, from 7.35 to 29.35 mm above the floor's top face. File it smooth.
3. Drill 3 mm relief holes where bend lines cross. Bend the stop up 90°, then the walls (inside radius 1.5 mm), then fold each tab round the outside of the stop.
4. Drill 3.3 mm through each tab and the stop, 6 mm in from the wall, 8 and 22 mm above the floor. Fit the rivets from inside, heads inside the frame.
5. Fold the 4 mm strip at the open end up 90° to make the lip. Cut three 14 mm notches in it for the screw heads under the cartridge: centred 41.75 mm and 8.25 mm toward the front of the centre line and 58.25 mm toward the back.
6. Stick the "C5 ONLY" decal on the outside of the stop, just above the slot.

**How it fits the parts next to it.**

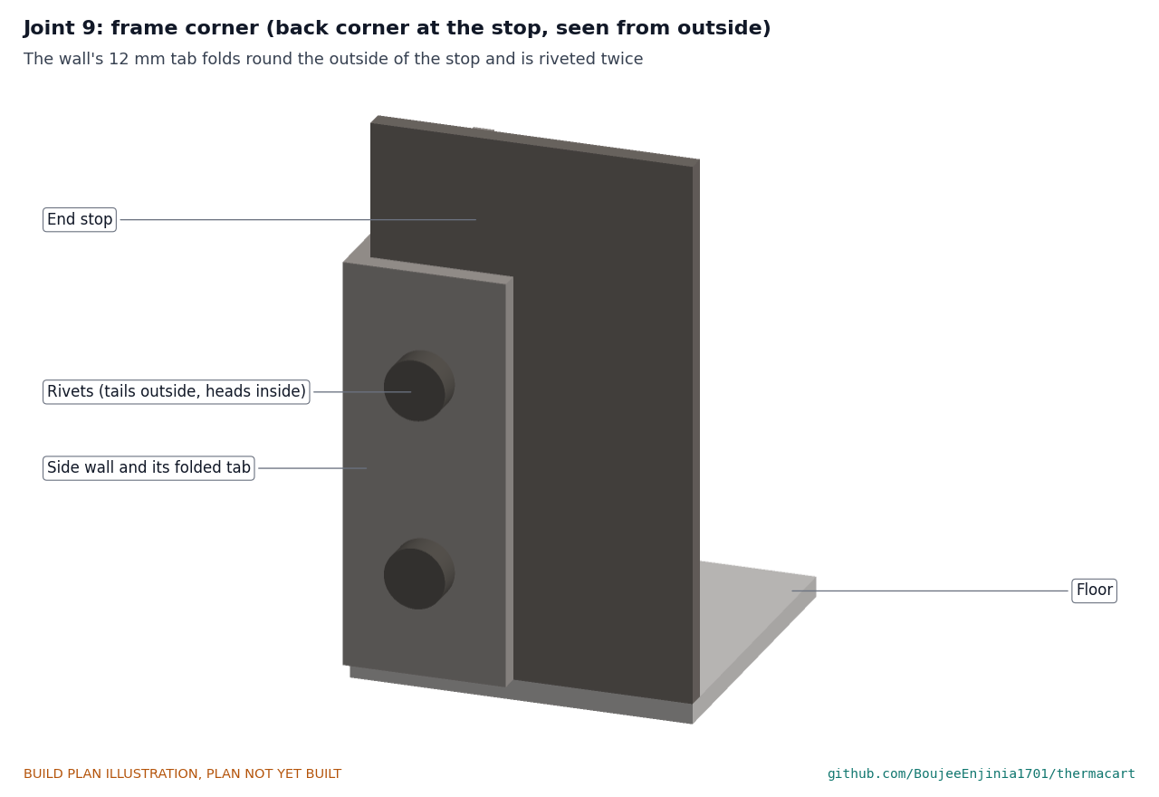
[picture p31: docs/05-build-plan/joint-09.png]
Figure 21. Joint 9: frame corner


*Figure 21. The wall's tab folds round the outside of the stop and is riveted twice.*

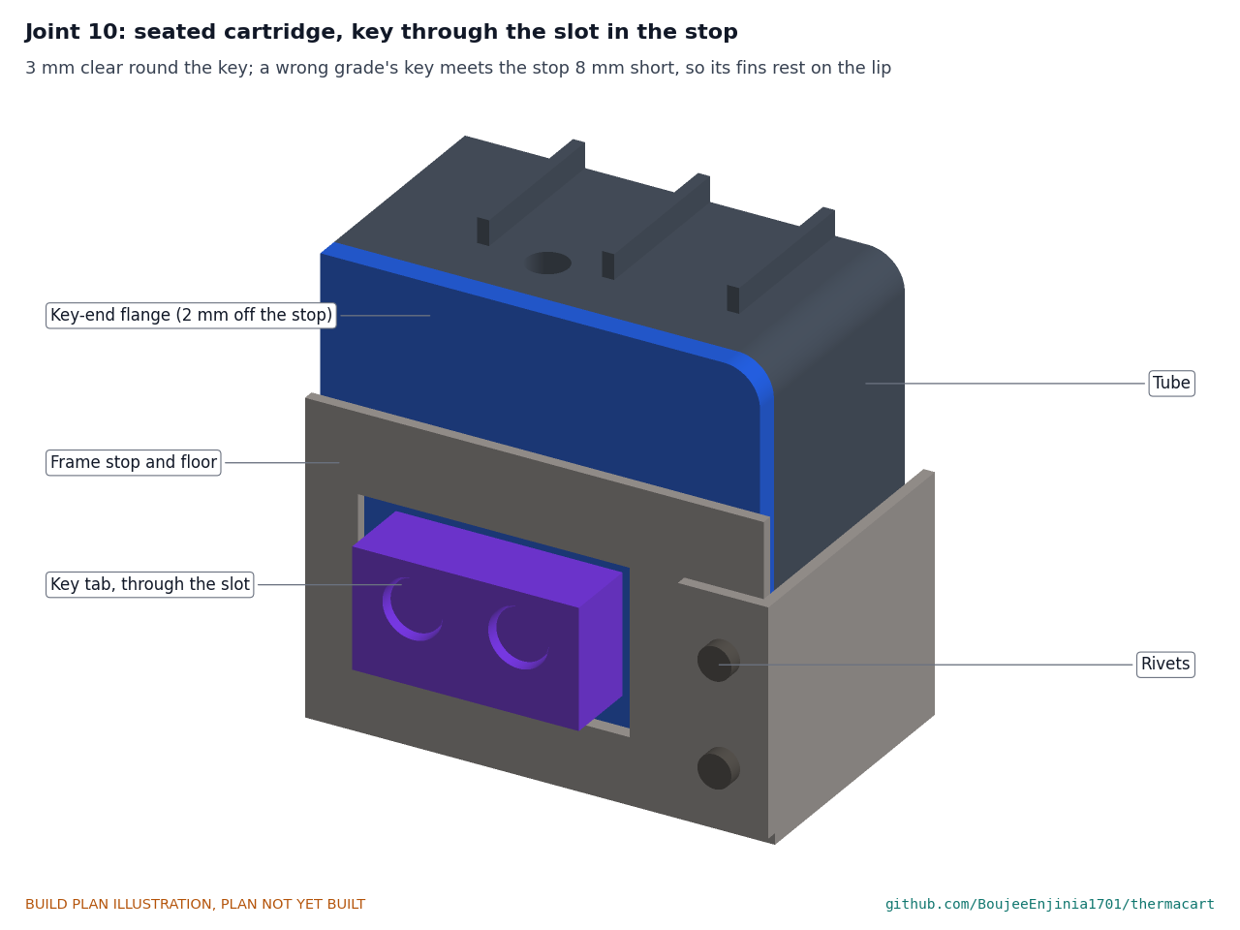
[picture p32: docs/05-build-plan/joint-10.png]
Figure 22. Joint 10: the seated cartridge


*Figure 22. Seated, the key passes through the slot with 3 mm all round and the nose flange stops 2 mm from the stop.*

The cartridge stands on its bottom fins on the floor, 2.5 mm from each wall, and the ends of its bottom fins sit 3 mm inside the lip. A cartridge of another grade meets the stop with its key 8 mm short of seated, so its bottom fins cannot drop behind the lip: they rest on top of it, and that cartridge sits with its handle end 4 mm high and plainly out of place.

**Check before moving on.** Inside width 157.4 mm; the stop square to the floor; the rivet heads 1 mm or less proud inside; the lip 4 mm tall and square to the floor.

### 3.11 Bought components

Buy to specification, not brand. Line numbers are those of the bill of materials.

- **PCM fill (line 2).** 1.10 kg of organic paraffin that melts at 5 to 6 °C (Rubitherm RT 5 HC class), with its datasheet, plus about 10 g for the indicator.
- **O-ring cord (line 3).** FKM (or NBR) cord 2.5 mm, about 0.8 m, and a splicing kit; not EPDM, which paraffin swells.
- **Fill plug (line 4).** G 1/2 plug with collar and hex socket (DIN 908 class) in anodised aluminium, and a G 1/2 FKM bonded sealing washer; anti-seize for the thread.
- **Grip, phenolic and pins (line 5).** Silicone sleeve 24 mm outside, 16 mm bore, 60 mm long; phenolic laminate sheet 3 mm for eight washers; two 5 mm stainless pins (or M5 shoulder bolts) with nyloc nuts.
- **Label and marking (line 6).** Colour-coded C5 polyester label with grade, fill, melt point and warnings, and the charging instruction: freezer, then about 4.2 h of conditioning, as a required step; notched for the indicator. A cut vinyl stencil for the side marking "ThermaCart, TC-L C5" and white high-temperature paint.
- **Frame decal (line 7).** A printed "C5 ONLY" vinyl decal for the stop.
- **Fixings (line 8).** A2 stainless: twelve M5 x 10 button-head screws (ISO 7380) with twelve M5 FKM bonded sealing washers; three M4 x 12 countersunk screws; two M4 x 16 and four M4 x 20 socket cap screws; two M6 x 12 button-head screws. Structural epoxy rated to 120 °C or more; thread sealant; medium threadlocker.
- **Finish (line 1).** Etch primer and matte black high-temperature paint rated well above 90 °C; blue high-temperature paint and 18 mm masking tape for the grade band.
- **Rivets (line 7).** Four 3.2 mm aluminium blind rivets for 3 mm grip.

## 4. Putting it together

In each picture the parts already fitted are grey and the part being fitted is in colour, with an arrow showing the way it goes in.

### Step 1: bottom fins onto the tube

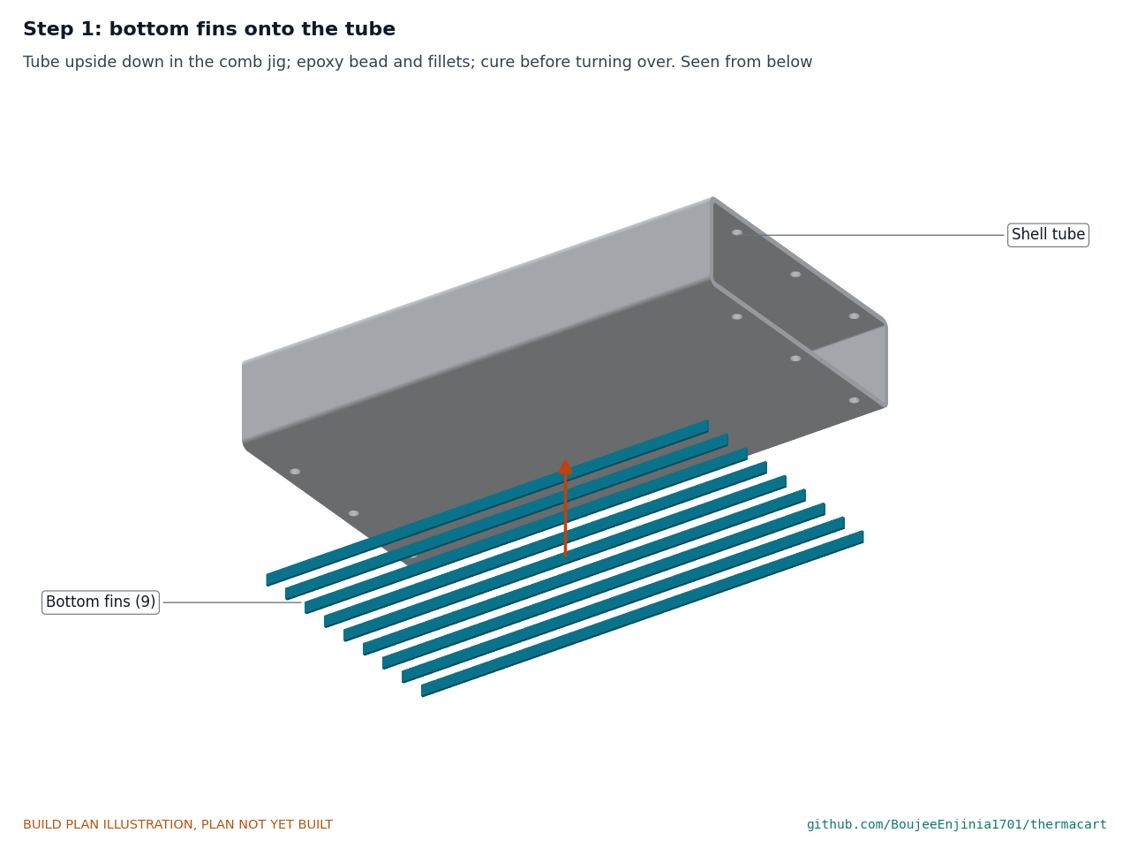
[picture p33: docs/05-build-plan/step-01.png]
Step 1


Stand the tube upside down on the bench with the comb across it. Lay an epoxy bead along each fin line, set the nine bottom fins in the comb, form the fillets and let the epoxy cure fully before turning the tube over.

### Step 2: top fins onto the tube, then the finish, grade band and marking

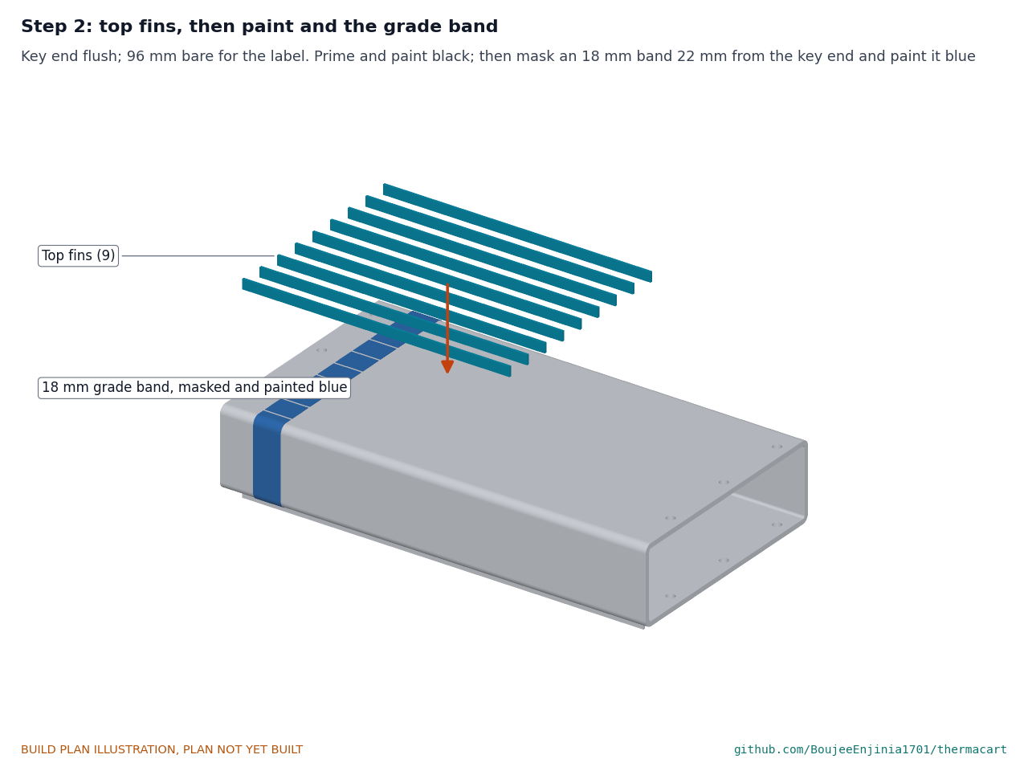
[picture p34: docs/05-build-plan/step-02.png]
Step 2


Bond the nine top fins the same way, flush with the bottom fins at the key end. When cured, mask the bore and the end faces, prime and paint the shell and fins matte black, and cure the paint as its maker says, before any paraffin is near it. Then mask an 18 mm band round the nose end, starting 22 mm from the key-end face, and paint it blue, the C5 grade colour. Last, paint the side marking "ThermaCart, TC-L C5" in white on the front face through the stencil.

### Step 3: key tab onto the key-end cap

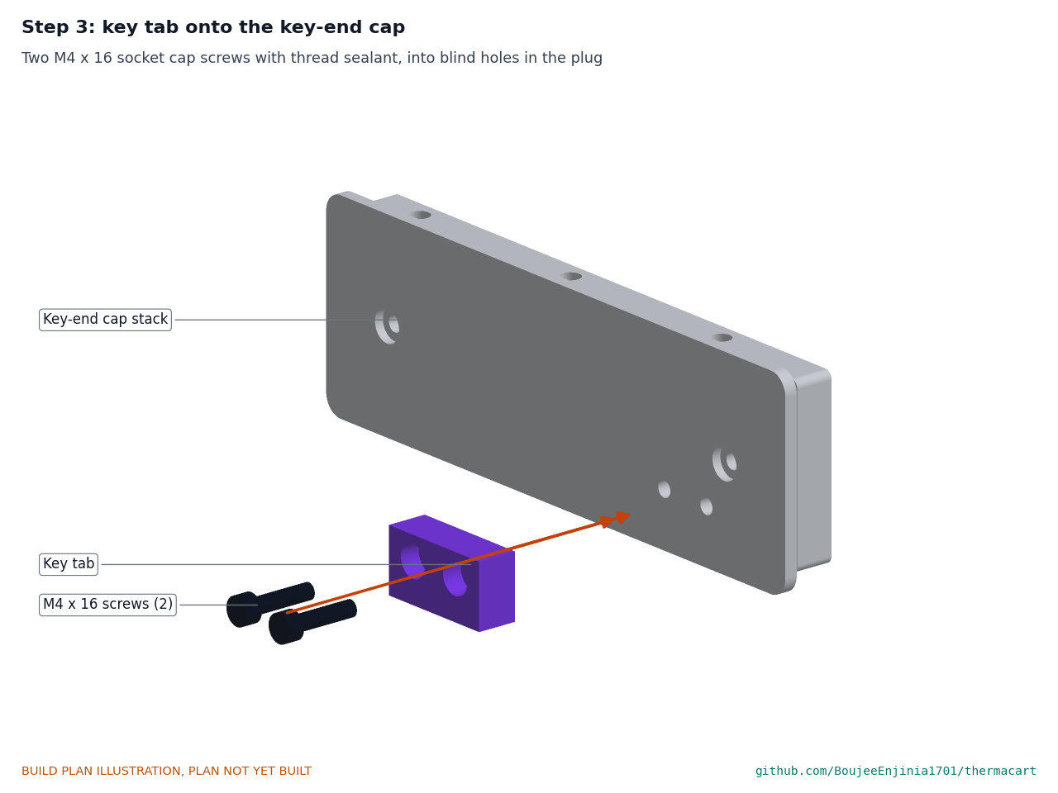
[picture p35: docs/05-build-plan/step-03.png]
Step 3


Two M4 x 16 socket cap screws with thread sealant into the blind holes in the plug, tight.

### Step 4: key-end cap into the tube

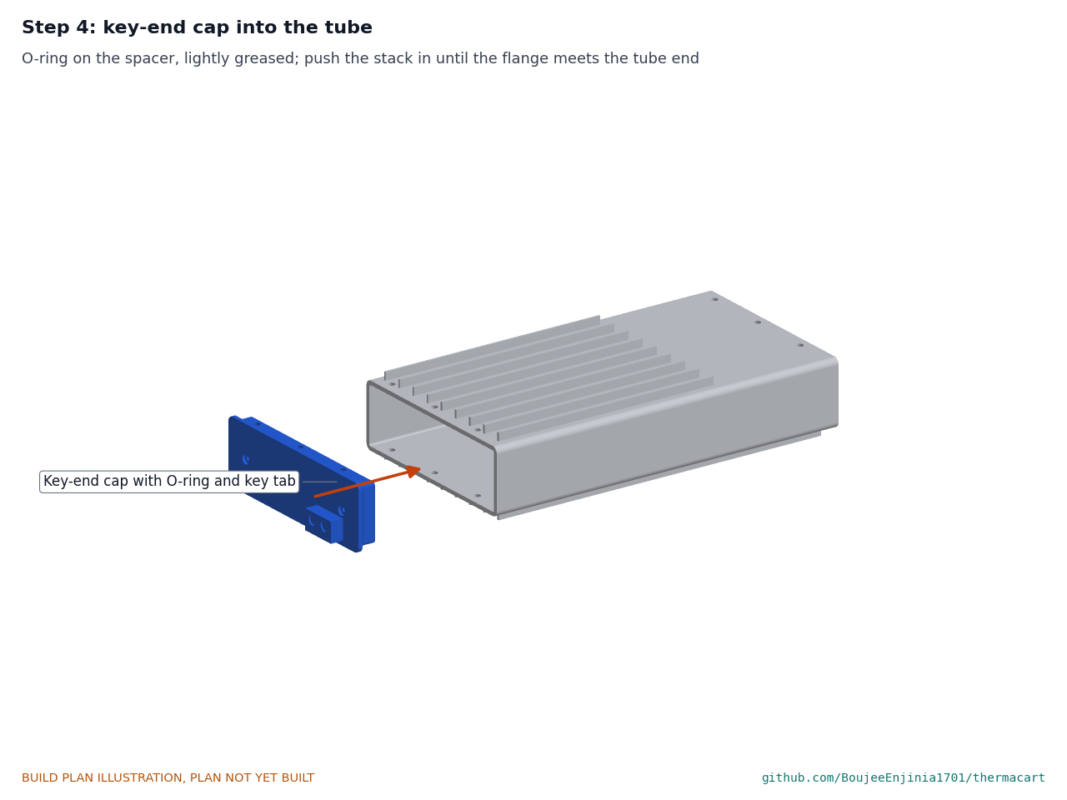
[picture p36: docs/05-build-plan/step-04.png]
Step 4


Splice the O-ring, stretch it round the spacer and wipe it with a trace of silicone grease. Push the stack into the key end, key tab outward and on the front side, until the flange meets the tube end.

### Step 5: radial screws at the key end

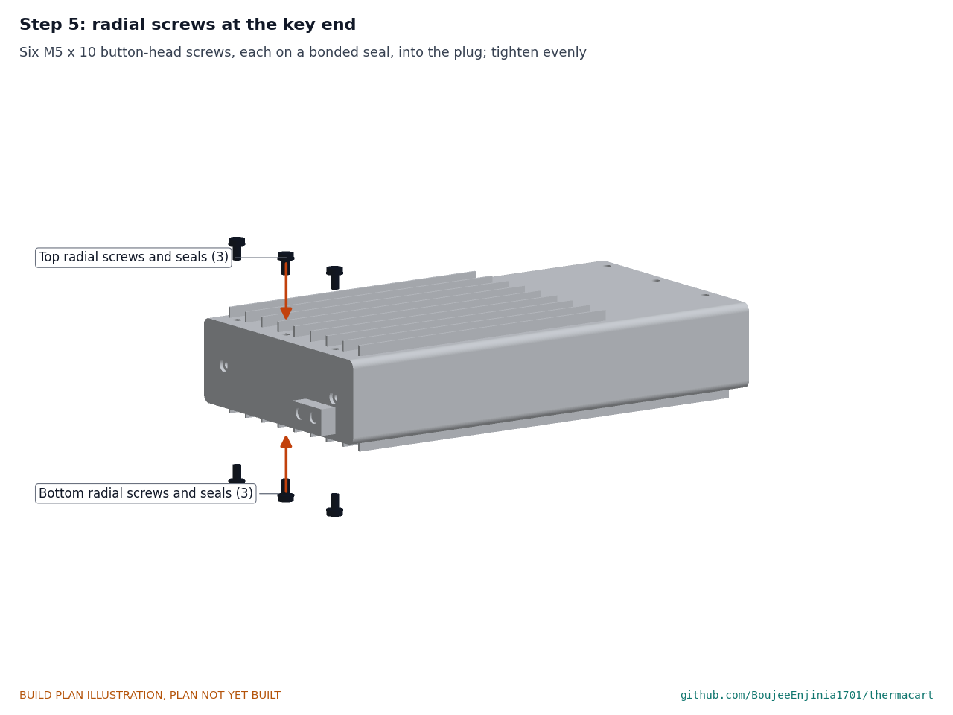
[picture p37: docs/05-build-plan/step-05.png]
Step 5


Six M5 x 10 button-head screws, each on a bonded sealing washer, into the plug; tighten evenly, top and bottom alternately.

### Step 6: lug angles onto the handle-end cap

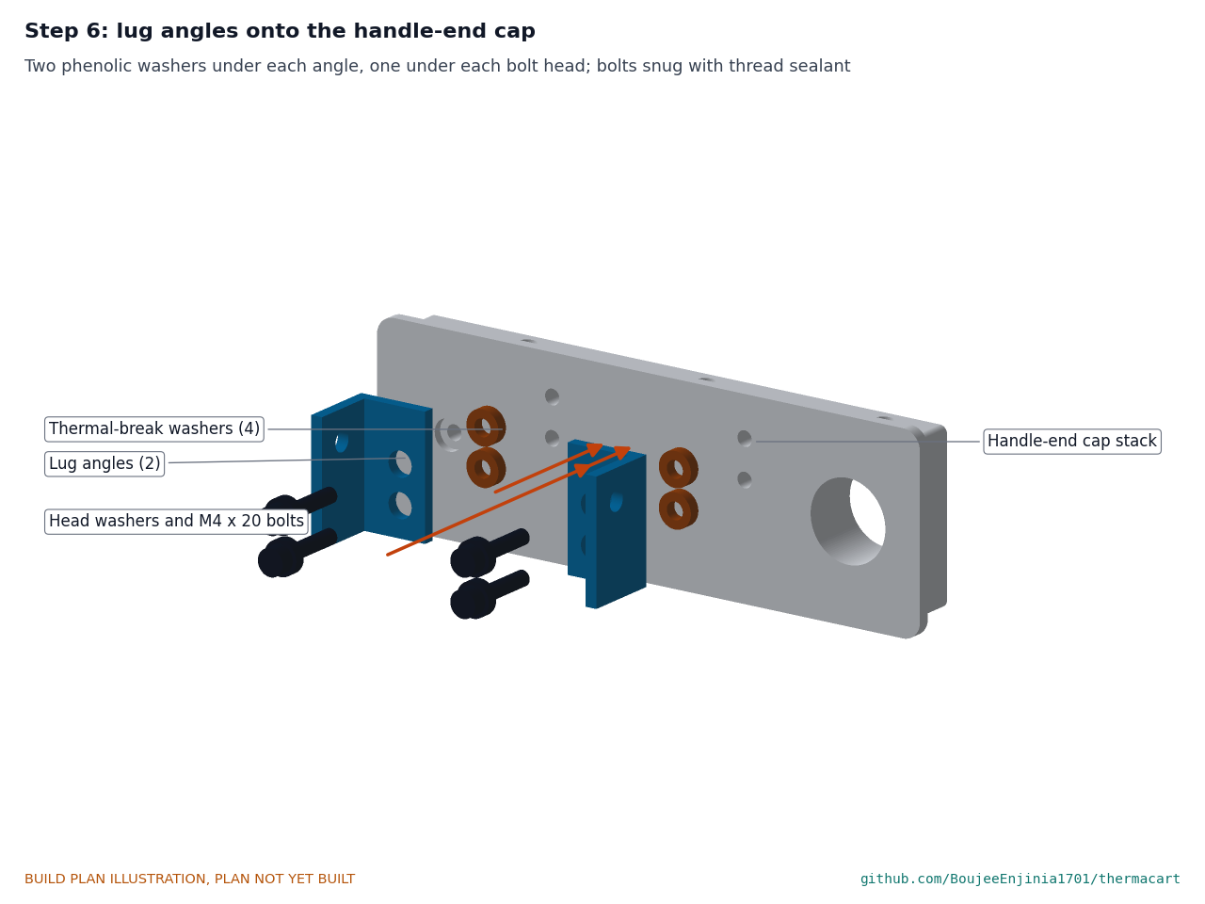
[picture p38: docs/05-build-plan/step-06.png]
Step 6


Two phenolic washers under each angle and one under each bolt head; four M4 x 20 bolts with thread sealant, snug. Check the meter test of section 3.6.

### Step 7: handle-end cap into the tube

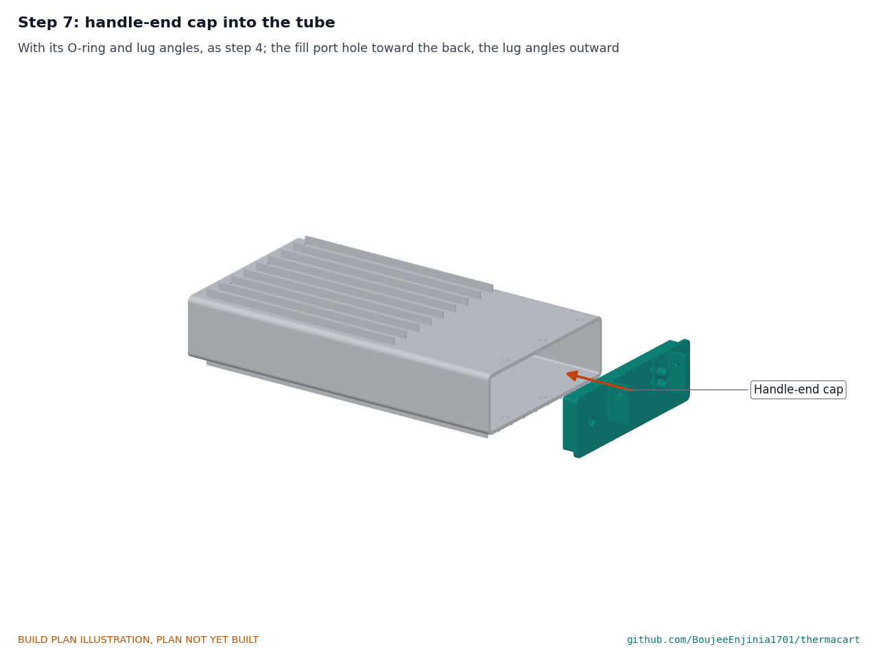
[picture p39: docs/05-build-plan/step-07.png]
Step 7


As step 4, with the fill port toward the back and the lug angles standing outward.

### Step 8: radial screws at the handle end

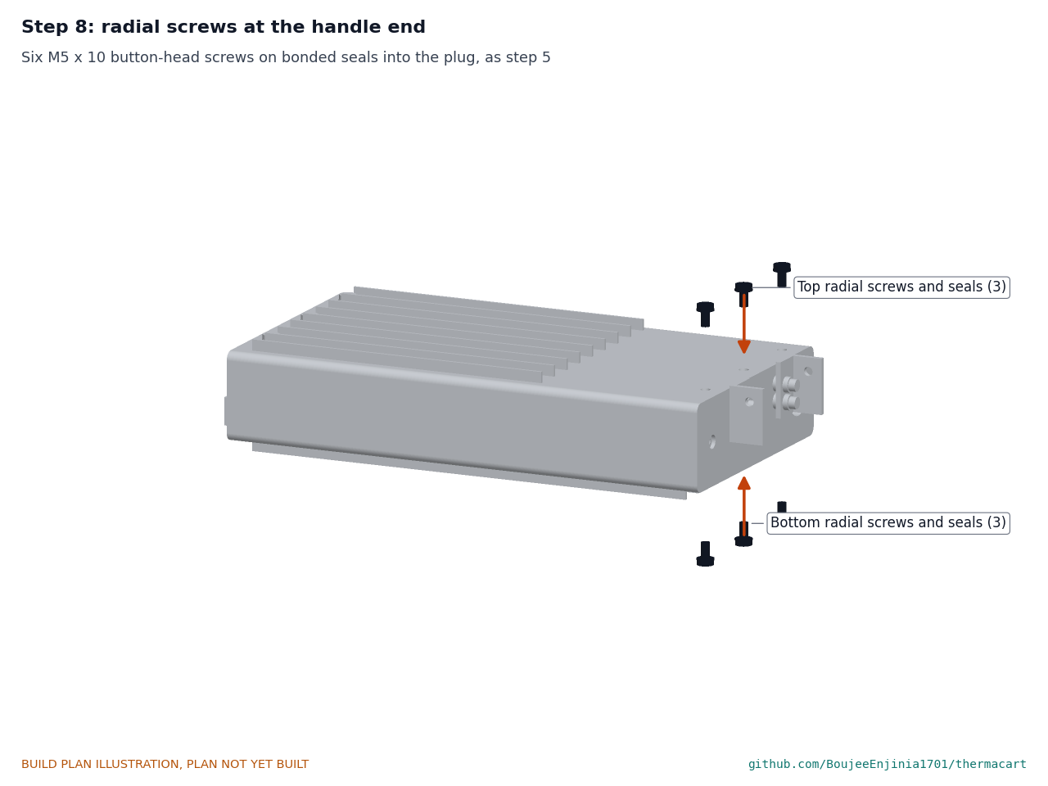
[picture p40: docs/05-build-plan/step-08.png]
Step 8


As step 5. **Hold point:** the leak check of section 5 passes before any paraffin goes in.

### Step 9: bail onto the lug angles

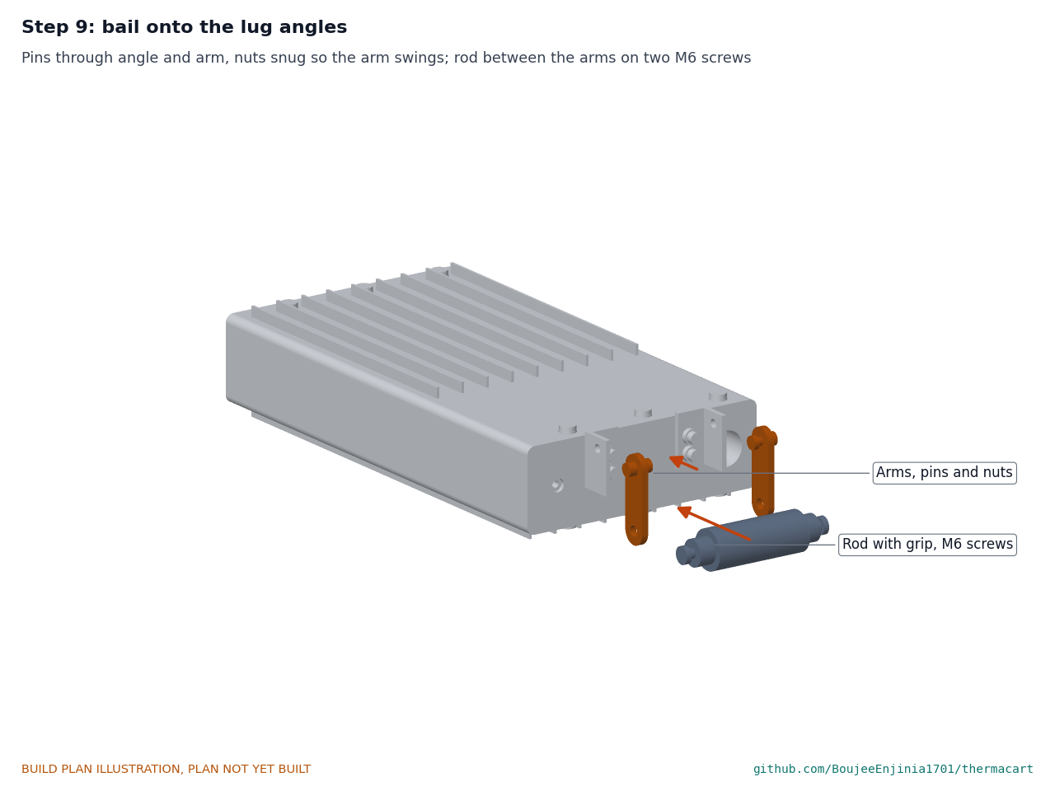
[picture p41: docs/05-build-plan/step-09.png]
Step 9


Pin each arm to its angle, pin head inside and nyloc nut outside, snug so the arm swings. Fit the rod between the arms on the two M6 screws with threadlocker. Swing the bail through its travel: it must not touch the fill port, the cap or the top.

### Step 10: fill with paraffin, then plug the port

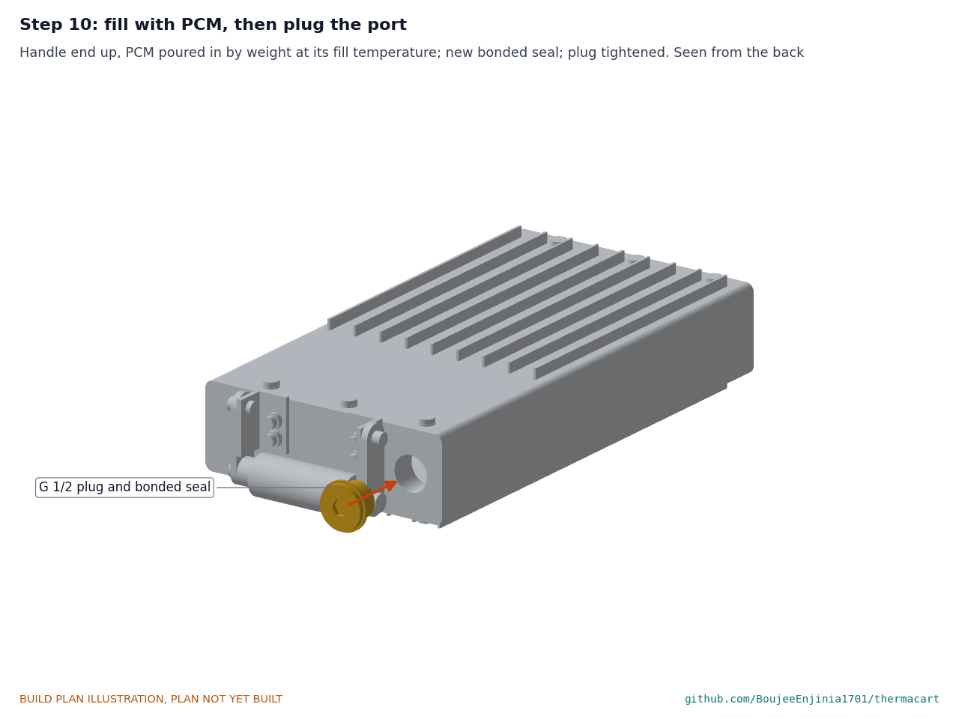
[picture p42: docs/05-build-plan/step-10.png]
Step 10


Melt the C5 paraffin in a water bath and bring it to 45 °C. Warm the empty cartridge to 45 °C in the same bath (port plugged) or a warm room, then stand it on its key end in a support box with the port up. Pour in 1.104 kg through a funnel, checked on a scale; this leaves 10 % of the space as air. Wipe the port, fit the plug on a new bonded seal with anti-seize and tighten it. **Hold point:** safety stop S3.

### Step 11: melt indicator, guards and label onto the top

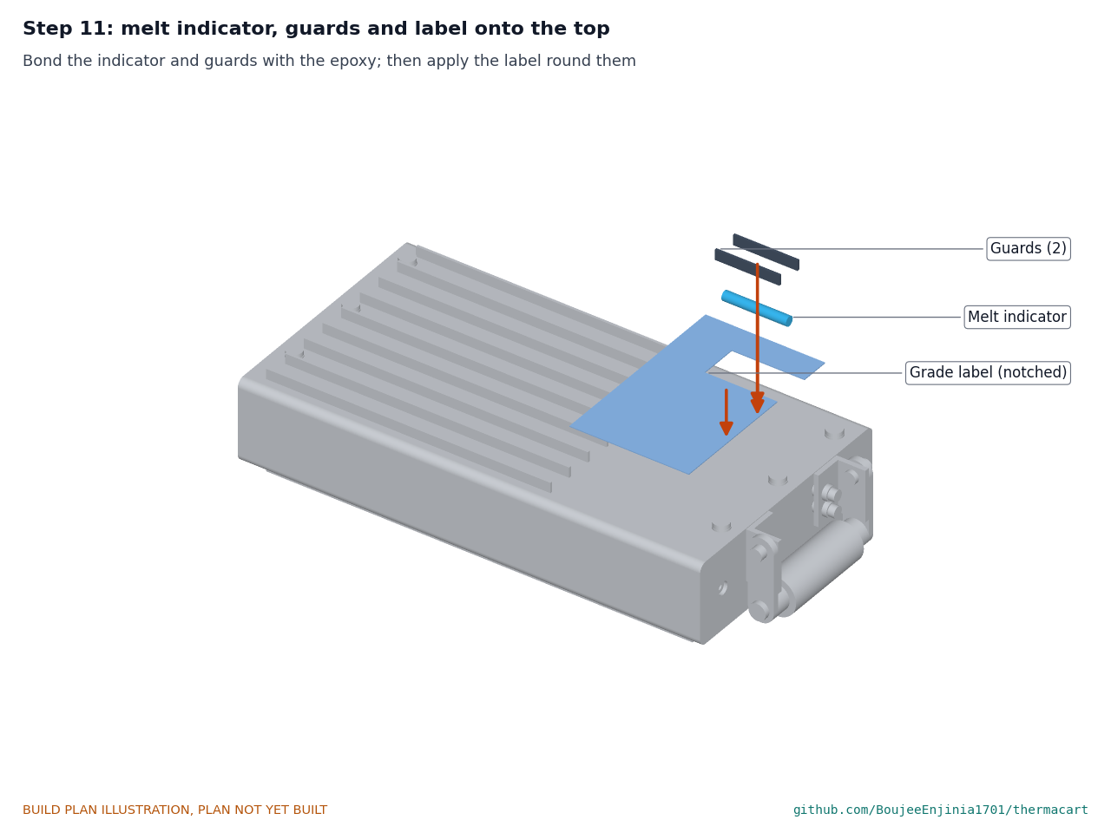
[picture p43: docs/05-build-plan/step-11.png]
Step 11


Bond the indicator and the two guards to the painted top with the epoxy (section 3.9). When cured, apply the label round them.

### Step 12: cartridge into the adapter frame

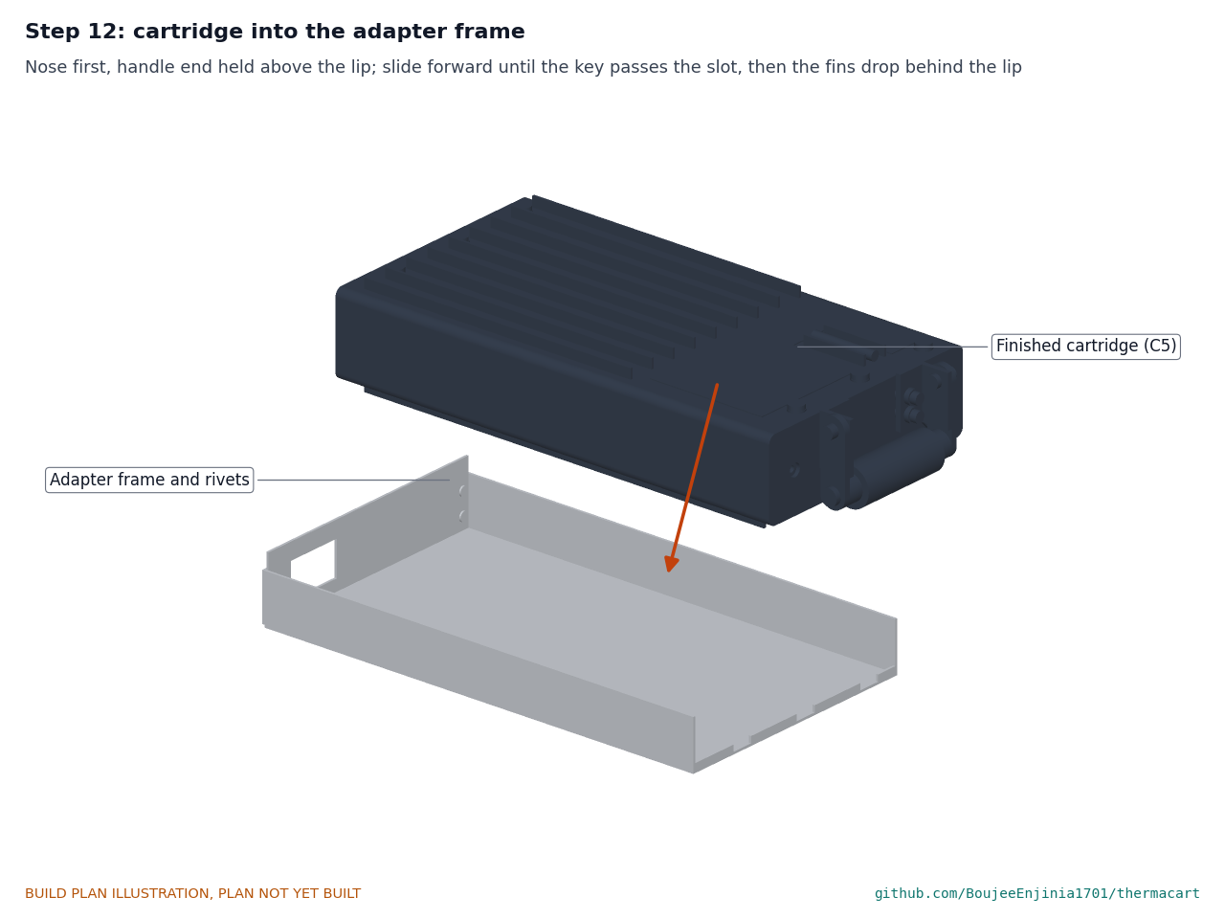
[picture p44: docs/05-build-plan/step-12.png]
Step 12


Hold the cartridge nose down with its handle end above the lip, slide it forward until the key passes through the slot, then lower the handle end so the bottom fins drop behind the lip. The nose stops 2 mm from the stop.

## 5. First checks

These are the checks a TRL 4 test report would record; this plan only lists them. Requirement numbers are those of TCT-REQ-001.

*Table 2. First checks.*

| Check | Requirement | How | Pass when |
| --- | --- | --- | --- |
| Envelope | R2 | Measure with the bail stowed; try it in a GN 1/3 pan slot | 323.4 x 152.4 x 63.5 mm or less; it drops in |
| Leak check, empty | R6 | Before filling, warm the sealed empty cartridge in a 45 °C water bath for 10 min with the port plugged | No bubbles at any cap, screw or plug |
| Leak check, filled | R6 | Stand the filled cartridge on each end in turn for 1 h at 45 °C on absorbent paper | No paraffin on the paper |
| Mass | R4, R5 | Weigh empty and filled | About 1.80 and 2.90 kg; 3.0 kg or less filled |
| Keying | R9 | Try the C5 cartridge in the frame; try a 30 mm block taped at the C25 and H70 positions | C5 seats behind the lip; the others meet the stop 8 mm short and rest on the lip, handle end 4 mm high |
| Indicator | R13 | Freeze the cartridge, then let it warm | The indicator is white when frozen and clears as the paraffin melts |
| Charge time | R12 | C5 from 8 °C in a domestic freezer at -18 °C | Fully frozen in 8 h or less (4.2 h estimated) |
| Bail temperature | R14 | Only for an H70 build: thermocouple on the grip during pad charging | Below 55 °C (39 °C estimated) |
| Drain | R18 | Melt and pour out through the port into a weighed container | At least 95 % of the fill comes out |

## 6. Safety stops

Stop at each point. Carry on only when everything listed is true.

- **S1. Before any epoxy, primer or paint.** Ventilation running; nitrile gloves and eye protection on; no flame or heater near the solvent. The paint is rated well above 90 °C.
- **S2. Before melting paraffin.** A water bath on a thermostatic heater with a thermometer in the bath; no open flame or hot plate in the room; a lid and a fire extinguisher for fat and oil fires within reach. The C5 paraffin is never heated above 45 °C.
- **S3. Before the cartridge is sealed.** The fill is exactly 1.104 kg at 45 °C (10 % air space); the cartridge has not been sealed warmer or fuller than this, because a fuller or hotter fill raises the pressure later. Never open or refill a warm cartridge.
- **S4. Before the first freeze.** The leak checks of section 5 pass. A frozen cartridge holds a partial vacuum of about 0.7 bar and its broad faces pull in by about 0.8 mm; this is expected.
- **S5. Before handling the frozen cartridge.** Gloves on; it is below 0 °C. It is not for vaccines or medicines.
- **S6. For any later H70 build (outside this plan).** H70 is filled at 90 °C, the paraffin limit: the bath and the cartridge must never exceed 90 °C. After an oven, use oven gloves or wait 12 minutes before carrying by the bail.

## 7. Tools, skills and workspace

**Tools.** Hacksaw or bandsaw with a fine blade; bench vice with soft jaws; bench drill with a V-block; drills 3 to 6.5 mm, an 18.6 mm drill and a G 1/2 tap with a large tap wrench; M4, M5 and M6 taps; countersink; files and a deburring tool; scriber, engineer's square, steel rule and calipers; hand sheet-metal brake (makerspace) and aviation snips; hand rivet tool; clamps; a wooden comb for the fins (section 3.2); mixing cups and spreaders for epoxy; spray booth or ventilated corner for priming and painting; thermostatic water bath (a sous-vide stick in a pot works) and a thermometer; funnel, syringe and a 5 kg scale; multimeter.

**Skills.** No certified trade is needed. Basic metalwork (marking out, sawing, drilling, tapping, filing, bending thin sheet, riveting), surface preparation and bonding with structural epoxy, aerosol painting, and careful handling of warm paraffin.

**Workspace.** A bench about 1.2 x 0.6 m; a metalwork corner kept apart from the bonding and painting area so chips stay off wet epoxy; a ventilated space for painting; a heat-safe surface for the water bath, away from anything that burns.

**Personal protective equipment.** Safety glasses for cutting, drilling and painting; cut-resistant gloves for tube and sheet; nitrile gloves for epoxy, primer and paraffin; hearing protection when sawing; no gloves near a turning drill.

## 8. Where the numbers come from

- Model and constructability checks: `cad/src/model.py` (`python cad/src/model.py --check`); STEP and STL exports in `cad/step/` and `cad/stl/`.
- Pictures: `cad/src/build_plan_media.py`, using `.kit/build_views.py`; written to `docs/05-build-plan/` and `cad/drawings/TCT-DWG-101` to `TCT-DWG-110`.
- General arrangement: `cad/drawings/TCT-DWG-001.pdf`, Rev P4.
- Calculations: `docs/04-calcs/01-sizing.md` (TCT-CAL-001 v0.3) and `docs/04-calcs/sizing.py`; mass [A4] to [A6], storage [B1], pressure and vacuum [C1] to [C5], charge time [E1], bail temperature [F1], [F2], keying [G1], cost [H1].
- Bill of materials: `bom/bom.csv`.
- Decisions: `docs/decisions/0003-design-for-construction.md` (TCT-DDR-003), with TCT-DDR-001 and TCT-DDR-002.
- Requirements: `docs/03-requirements.md` (TCT-REQ-001 v0.5).

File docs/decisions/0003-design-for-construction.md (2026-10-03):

---
doc_id: TCT-DDR-003
title: ThermaCart design for construction
project: ThermaCart
doc_type: Design decision record
version: "0.3"
status: Draft
date: '2026-10-02'
author: Amish Chadha
license: CERN-OHL-S-2.0
revisions:
- version: "0.1"
  date: '2026-10-01'
  author: Amish Chadha
  change: Changes that make the concept physically buildable, with the reason for each; made under Amish's 2026-09-30 instruction and open for his review
- version: "0.2"
  date: '2026-10-02'
  author: Amish Chadha
  change: "Table 3 decided by Amish on 2026-10-02 (A1 option (b), A2 and A3 as recommended); Tables 1 and 2 still open for review; record stays Draft"
- version: "0.3"
  date: '2026-10-02'
  author: Amish Chadha
  change: "Tables 1 and 2 accepted by Amish on 2026-10-02; record stays Draft"
---

# 0003: Design for construction

- **Date:** 2026-10-01
- **Status:** accepted. Amish, 2026-10-02: "APPROVED: Design-for-construction changes in 10 repos (CityTwin, CoolShade, PalletPilot, Heliolite, PotholeLog, EarthPress, ReadyKit, CellCheck, CargoMule and ThermaCart)". This covers the changes P1 to P11 in Table 1 and the knock-on changes in Table 2, made under Amish's 2026-09-30 instruction to make the design physically buildable, and is recorded in the design decisions register (TCT-DEC-001). Items that would change what the cartridge does, its pitch or its safety case are not made here: they were listed in Table 3 as "Proposed, awaiting Amish", and Amish accepted the recommendations for all three earlier the same day: "i approve your recommendations for all 555 open decisions." For A1 the accepted recommendation is option (b), the low lip, which differs from the (a) first proposed here; it is to be designed and is not yet in the model. Recorded in the design decisions register (TCT-DEC-001, items 1 to 3). The record stays Draft.

## Context

On 2026-09-30 Amish asked for every repo to have a prototype build plan that shows how each component is made and how it fits the next, and wrote: "If you are realising that the design cannot be built as per concept - fix the design assumptions to match and be physically feasible as you draw the illustrations." The concept model behind TCT-DDR-001 and TCT-DDR-002 showed what ThermaCart does and was sized in TCT-CAL-001, but a constructability review of `cad/src/model.py` with build123d (overlap volumes, contacts and clearances between every pair of parts that meet) found parts that could not be made, assembled or sealed as drawn.

The changes keep what ThermaCart does: the same stock tube, inner volume (1.655 L), fill, grades, fins, finish, GN 1/3 envelope (323.4 x 152.4 x 63.5 mm with the bail stowed), folding bail, key positions and frame. Every change is in `cad/src/model.py`, which now builds each component separately and runs 68 constructability checks (`python cad/src/model.py --check`), including the bail swung to 90 and 180 degrees. All 68 pass.

## Decision

*Table 1. Changes made to the model, the BOM and the calculations.*

| # | Problem in the concept | Change made | Why this way |
| --- | --- | --- | --- |
| P1 | The G 3/4 fill port bore, 60 mm from the centre line, reached 71.7 mm from the centre; the spacer edge (the O-ring line) is at 70.5 mm, so the bore cut through the O-ring (24 mm³ of overlap in the model). | A G 1/2 plug with a collar and hex socket (DIN 908 class) in anodised aluminium, on a bonded FKM sealing washer, tapped through the bonded cap stack 56 mm toward the back from the centre line at mid-height. Its thread stays 3.5 mm inside the O-ring line and its collar 2 mm clear of the bail. | Smallest change that seals: the port moves inside the gland, and G 1/2 still pours and drains paraffin. An aluminium plug avoids a stainless and aluminium couple and is 20 g lighter, which keeps R5. |
| P2 | A 3 mm O-ring cord in a corner gland 3 mm long and 2.5 mm deep fills 94 % of the gland, with no room for the cord to swell at 90 °C; the square spacer and plug corners would also hit the stock tube's inside corner fillets. | FKM cord 2.5 mm, gland 2.1 mm deep (the spacer is cut to the measured bore less 4.2 mm each way): 78 % fill, 16 % squeeze. Spacer corners 3.7 mm radius, plug corners 2 mm, flange corners 4.8 mm to match the tube; a 1 mm lead-in chamfer inside each tube end. | A static radial seal wants about 15 to 25 % squeeze and under about 85 % fill. Cutting to the measured bore takes up the extrusion's tolerance on a one-off build. |
| P3 | The six radial screws per cap sit inboard of the O-ring, so their holes in the tube wall are on the PCM side of the seal (a leak path); they were drawn as heads only; and an M5 countersink in a 3.175 mm wall leaves a knife edge. | M5 x 10 A2 button-head screws (ISO 7380) on M5 FKM bonded sealing washers, through 5.5 mm holes into M5 holes tapped 7.5 mm deep in the plug edge. Heads sit between the fins (2.1 mm clear) and 2.6 mm above the frame floor. Holes are transfer-drilled with the cap in place. | The bonded washer seals each hole where the screw head clamps it; moving the O-ring outboard of the screws would need a fourth plate and more length the envelope does not have. |
| P4 | The flange, gland spacer and plug had no fixing to each other. | Bonded face to face over their whole faces with the 120 °C structural epoxy, which also seals the joint lines, and held by M4 screws into blind holes tapped 7.5 mm deep in the plug, never through its wet face: at the handle end the four lug bolts and one M4 countersunk screw; at the key end the two key tab screws and two M4 countersunk screws. | The stack is one rigid block before it is tapped and fitted; no screw hole reaches the PCM. |
| P5 | The bail could not fold: each arm sat in front of its lug, so its pin would have run along the cartridge. The lugs stood 3.2 mm above the flange, over the O-ring gland, with no fixing; a steel bolt through the thermal-break washer would have bypassed the break; and the 16 mm rod was wider than the 12 mm arms. | Two lug angles (20 x 20 x 3 mm aluminium angle, 32 mm long) each held by two M4 x 20 bolts into the plug, standing on two phenolic washers (9 mm across, 3 mm thick) per bolt, with a 3 mm phenolic washer under each bolt head and 1.25 mm of air round each bolt in a 6.5 mm hole. Two 16 x 4 mm arms, 38 mm between holes, lie on the outside of the angles' upright legs on 5 mm stainless pins with nyloc nuts. The 16 mm rod, 80 mm long and tapped M6 at both ends, sits between the arms on two M6 x 12 button-head screws. | Every joint is face to face and fixed, the pivot runs across the cartridge as a bail must, and only phenolic touches the bail, so the thermal break works. The stowed envelope is unchanged; the raised finger gap is 41 mm (was 39 mm). |
| P6 | The key tab had no fixing. | Two M4 x 16 socket cap screws in 5 mm counterbores from the front of the tab, through flange and spacer into blind holes in the plug, 7 mm each side of the key centre and 14 mm above the flange's bottom edge. | The screw heads sit below the tab's front face and clear of the frame slot. |
| P7 | The frame's end stop stood 2 mm in front of the key tip, so the key never entered its slot and the frame had no seated position for any grade. | The stop moved so that a seated cartridge's nose flange is 2 mm from the stop and the key passes through the slot with 3 mm clearance all round. The frame floor is 294 mm long (was 304 mm). A wrong grade's key meets the stop and that cartridge stays 12 mm short of seated. | This is what the keying in R9 and TCT-CAL-001 (G1) assumed. |
| P8 | The stop and the side walls overlapped in the corners, which a sheet bent from one blank cannot do. | The stop is 157.4 mm wide and bends up between the walls; each wall ends in a 12 mm tab folded round the outside of the stop and fixed with two 3.2 mm blind rivets, heads inside, 1 mm clear of the nose flange; 3 mm relief holes where bend lines cross. | A standard box corner for a hand brake. |
| P9 | The "sight window" was a 22 mm disc 2 mm thick on the label: too thin to hold a vial, and with no fixing. | A clear polycarbonate tube, 6 mm outside and 4 mm bore, 40 mm long, filled with the grade's PCM and closed with epoxy plugs, bonded along the top 30 mm toward the back from the centre line, between two 40 mm guards of the fin bar bonded on edge 8 mm either side. The label is notched round them. | It shows solid (white) or liquid (clear) as before, is made with a saw, a syringe and the same epoxy, and the guards (as tall as the fins) take knocks. Polycarbonate is rated well above 90 °C and paraffins do not attack it. |
| P10 | The fins were bonded on their 1.59 mm edge with no bond detail. | A bead of the epoxy under each fin and a fillet down both sides, with the fins held upright at pitch in a slotted wooden comb while it cures. No geometry change. | A fillet spreads the load from a knock along the fin. |
| P11 | The stock tube's corner radii were not in the model. | The tube is drawn with 4.8 mm outside and 1.6 mm inside corner radii (3/16 and 1/16 in, typical for 6 x 2 x 1/8 in tube); the cap plates follow them (P2). | The real radii are to be confirmed with the supplier (TCT-DEC-001). |

*Table 2. Knock-on changes.*

| Item | Change | Reason |
| --- | --- | --- |
| Mass | Empty cartridge 1.80 kg, unchanged [A5]; filled 2.90 to 2.98 kg (R4 met, thin); PCM fraction 38.1 to 39.6 % (was 38.1 to 39.7 %, R5 met, thin). | The added screws, bolts, washers, pins and guards are balanced by the lighter aluminium fill plug (9 g against 30 g for the G 3/4 plug) and slightly less aluminium in the bail and cap plates. |
| Handle temperature | Bail 36.8 and 39.1 °C on cartridges at 71 and 80 °C (was 39.6 and 42.5 °C); below 55 °C 10 min after an 85 °C oven (was 12 min) [F1, F2]. | The new bail has more area to the air and the bolts are insulated (P5). The 12 min label rule is kept. |
| Cost | Cartridge $80 (was $76), frame $17 (was $16); one C5 cartridge and one frame $97 against the $80 value-engineering target, $17 over [H1]. | Bonded seals, bolts, phenolic washers, rivets; the G 1/2 plug is $1 cheaper. `budget_usd` is unchanged. |
| Thermal and pressure | Unchanged: inner volume, fill, fins, finish and wall are unchanged, so B to E of TCT-CAL-001 are unchanged. | |
| Drawing | TCT-DWG-001 Rev P4; making sketches TCT-DWG-101 to 110 added. | Follows the model. |
| Documents | TCT-CAL-001 v0.3, TCT-REQ-001 v0.5, TCT-PRC-001 v0.5; BOM lines 1 and 3 to 8 rewritten. No requirement target changed. | Follows the model. |

*Table 3. Proposed, then decided by Amish on 2026-10-02.*

| # | Question | Options | Recommendation |
| --- | --- | --- | --- |
| A1 | How a wrong grade is shown to be rejected (R9). With P7, a wrong grade's key meets the stop and the cartridge stays 12 mm short, its handle end standing proud of the frame, but nothing stops it being left in the host like that. This touches the safety case: a frozen W0 or hot H70 cartridge in a cold-chain box. | (a) accept the 12 mm stand-off and check at TRL 4 that the host's lid or door will not close on it; (b) a low lip at the frame's open end that the bottom fins drop behind only when the key is through the slot (needs the stowed grip moved up, a change to the bail); (c) a sprung detent in the stop. | (a) for the prototype, with the check written into the TRL 4 plan; (b) if the check fails. Decided 2026-10-02: (b). Design the low lip on paper now, with the stowed grip moved up, so the frame rejects a wrong grade; fall back to (a) only if the TRL 4 check shows no target host's lid can close on a proud cartridge. |
| A2 | The W0 option (key at 61 mm toward the front) does not fit the constructable cap and frame: its outer key screw would be 0.9 mm from the O-ring line, and its slot would cut through the frame's corner tab. | (a) when W0 is sized, fix its tab with screws 4 mm each side of its centre and shorten that frame's tab; (b) move the W0 key position, which changes the published key table. | (a); W0 is an option not yet sized, and the key table is part of the open standard. Accepted 2026-10-02: (a), when W0 is sized; the key table is unchanged. |
| A3 | R5 now has 0.1 percentage point of margin (38.1 % against 38 %) on catalogue masses. | (a) accept and weigh the prototype at TRL 4; (b) look for mass now (a tubular bail rod, thinner plugs with M4 radial screws). | (a). Accepted 2026-10-02: (a); if the weighed prototype misses, the tubular bail rod first. |

## Consequences

- `design_state: constructable` in `project.yaml`. The prototype build plan TCT-BLD-001 shows every component and step in pictures generated from the model (`cad/src/build_plan_media.py`).
- Requirement status: 1 not met (R10), 1 over its value-engineering target (R16), 1 at risk (R12), 3 not verifiable at TRL 3 (R6, R7, R17), 12 met (TCT-CAL-001 v0.3). R16 was counted as not met before 2026-10-01; the budget is now a value-engineering target (STANDARDS section 18).
- The photoreal renders (`media/render-*.png`, made on Amish's Mac), `media/card.png`, `media/social-preview.png` and the appearance model `cad/src/product_model.py` still show the concept bail, the round sight window, the G 3/4 plug and the concept frame stop. They need updating on Amish's Mac. The concept media from `cad/src/concept_media.py` have been regenerated from the constructable model.
- The tube's corner radii, its bore and the bought parts in TCT-DEC-001 ("To confirm when parts are bought") are checked when parts are bought, which waits with TRL 4.

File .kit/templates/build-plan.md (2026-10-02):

---
doc_id: PRJ-BLD-001
title: Project prototype build plan
project: Project name
doc_type: Build plan
version: "0.1"
status: Draft
date: YYYY-MM-DD
author: Amish Chadha
license: CERN-OHL-S-2.0
revisions:
  - version: "0.1"
    date: YYYY-MM-DD
    author: Amish Chadha
    change: First build plan; design made constructable
---

# Project prototype build plan

**Plan, not yet built.** How to build the first proof-of-concept prototype, component by component. Building and testing to it is TRL 4 work. Decisions still to be made are kept in the design decisions register (`docs/06-design-decisions.md`), not here.

## 1. What you are building

Every component, pulled apart and numbered in build order

One short paragraph: what the prototype is, how many components, which are made and which are bought, and the main ways they are made.

## 2. What changed to make it buildable

| Component | The concept had | The buildable design has | Why |
| --- | --- | --- | --- |

## 3. Making the components

### 3.1 Component name

Making sketch

**What it is and what it is made from.**

**How to make it.**

1. Mark out ...
2. Cut ...

**How it fits the parts next to it.**

Close-up of the joint

**Check before moving on.**

## 4. Putting it together

### Step 1: ...

Step 1

## 5. First checks

| Check | Requirement | How | Pass when |
| --- | --- | --- | --- |

## 6. Safety stops

## 7. Tools, skills and workspace

## 8. Where the numbers come from

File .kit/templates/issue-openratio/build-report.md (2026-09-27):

---
name: Build report
about: Tell us what happened when you built, printed or tested part of this design
title: "Build report: "
labels: build-report
---

This is a research and educational prototype, not a medical device. It is a TRL 3 concept and is not released for fabrication. If you build any part of it, you do so at your own risk. Reports help everyone.

**What you built** (part, sub-assembly or test)

**Materials, tools and settings**

**What worked**

**What did not work, with photos or measurements if you have them**

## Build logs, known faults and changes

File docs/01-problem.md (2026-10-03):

---
doc_id: TCT-PRB-001
title: ThermaCart problem statement
project: ThermaCart
doc_type: Problem statement
version: "0.8"
status: Draft
date: '2026-10-02'
author: Amish Chadha
license: CERN-OHL-S-2.0
revisions:
- version: "0.1"
  date: '2026-09-25'
  author: Amish Chadha
  change: Initial scaffold
- version: "0.2"
  date: '2026-09-25'
  author: Amish Chadha
  change: Populate to TRL 2 (users, context, constraints, prior work with sources)
- version: "0.3"
  date: '2026-09-25'
  author: Amish Chadha
  change: TRL 3 update (paraffin expansion from datasheets, budget scope per TCT-DDR-001 D6, first host type, temperature limits)
- version: "0.4"
  date: '2026-09-25'
  author: Amish Chadha
  change: Recommendations accepted by Amish (DDR-002)
- version: "0.5"
  date: '2026-09-26'
  author: Amish Chadha
  change: Stronger sources
- version: "0.6"
  date: '2026-10-01'
  author: Amish Chadha
  change: Budget treated as a value-engineering target
- version: "0.7"
  date: '2026-10-02'
  author: Amish Chadha
  change: "First host partner route from Amish's 2026-10-02 decision (O1)"
- version: "0.8"
  date: '2026-10-02'
  author: Amish Chadha
  change: "Estimated cost updated to USD 100 for the approved follow-ups"
---

# ThermaCart problem statement

Every cold box, food carrier and small heat store that uses phase-change material (PCM) designs its own container, fill and interface from scratch, and loose or improvised PCM is messy, can corrode metal, can burn, and can freeze or overheat what it is meant to protect. There is no open, standard, sealed cartridge that a builder can pick by temperature grade and drop into a cooler, cabinet or heat exchanger.

## Why it matters

Storing heat or cold cheaply is the missing piece wherever power is intermittent or absent:

- Around 14 % of the world's food, worth about $400 billion a year, is lost between harvest and retail, and a further 17 % is wasted in retail and homes ([FAO and UNEP, 2022](https://www.fao.org/newsroom/detail/FAO-UNEP-agriculture-environment-food-loss-waste-day-2022/en)). Much of the loss in hot climates is spoilage for want of cooling.
- Cold chains fail in both directions. Water ice packs sit at 0 °C or below, and freezing exposure is common in vaccine storage and transport studies ([Hanson et al., 2017](https://www.sciencedirect.com/science/article/pii/S0264410X16309471)). A PCM that melts at 5 °C avoids this, which is why ColdPod in this portfolio uses one.
- About 2.1 billion people still cook on open fires or inefficient stoves using polluting fuels, and household air pollution caused an estimated 2.9 million deaths in 2021 ([WHO fact sheet, 2025](https://www.who.int/news-room/fact-sheets/detail/household-air-pollution-and-health)). Keeping cooked food hot without relighting a stove saves fuel and smoke.
- UNEP expects the world's installed cooling capacity to triple by 2050, with cooling emissions reaching more than 10 % of global emissions unless efficiency improves ([UNEP, About cooling](https://www.unep.org/topics/energy/cooling/about-cooling)). Thermal storage lets cooling run when power is cheap or clean.

## Users and context

| User | Context | What they need from a cartridge |
| --- | --- | --- |
| Builders of thermal devices, including this portfolio (ColdPod, ZeerBox, ThermaBrick, HelioLite) and other open hardware makers | Workshops and makerspaces | A known, documented storage block with published capacity, so they design the box, not the storage |
| Small food vendors, caterers and school or community kitchens | Carrying cooked food to a site, or holding it on a stall | Keep food at or above hot-holding temperature for a service period without gas or mains |
| Traders and smallholders moving produce or dairy | Coolers on motorbikes, in vans and on market stalls, often in 30 to 40 °C heat | Cold that lasts a working day and recharges overnight in a shared freezer |
| Off-grid households and clinics | Solar direct-drive refrigerators, cool boxes, comfort cooling | Swappable cold or heat that can be charged where power exists and carried to where it does not |
| Equipment integrators | Outdoor electronics and battery cabinets | A comfort-grade (25 °C) buffer that smooths daily temperature swings |

## Prior work

- **Commercial PCM products.** Rubitherm publishes organic PCMs from about −9 to 90 °C with storage capacities of 190 to 260 kJ/kg ([Rubitherm RT range](https://www.rubitherm.eu/en/productcategory/organische-pcm-rt)); Pluss sells savE PCMs and packs for cold chain ([Pluss](https://www.pluss.co.in/knowledge-center/technology/phase-change-materials/)). These are materials and proprietary packs, not an open, interchangeable format.
- **Standard coolant packs.** WHO PQS E005 fixes the sizes of water packs for vaccine carriers (0.3, 0.4 and 0.6 L; the 0.6 L pack is 190 x 120 x 34 mm) ([WHO PQS E005](https://extranet.who.int/prequal/key-resources/documents/pqs-performance-specification-e005ip012-water-packs-use-icepacks-cool-packs)). This shows the value of a common envelope, but it covers water only, at 0 °C.
- **Ice banks in solar refrigerators.** Solar direct-drive vaccine refrigerators freeze water or another PCM by day and run from that ice bank at night, giving about 83 to 170 h of autonomy in the prequalified models PATH lists ([PATH](https://media.path.org/documents/TS_opt_ebs_dd_solar_fridge.pdf)). The storage is built into each appliance.
- **Heat batteries.** Sunamp's salt-hydrate heat batteries, developed with the University of Edinburgh, store heat for hot water in homes and hold RAL quality certification for stability over tens of thousands of cycles ([University of Edinburgh](https://chem.ed.ac.uk/research/research-impact/heat-storage-technology)). The RAL-GZ 896 scheme sets quality and test rules for PCMs ([Quality Association PCM](https://pcm-ral.org/quality-testing-specifications-pcm/)).
- **Food service containers.** Gastronorm sizes, standardized as EN 631-1 ([BSI, BS EN 631-1:1993](https://knowledge.bsigroup.com/products/materials-and-articles-in-contact-with-foodstuffs-catering-containers-specification-for-dimensions-of-containers)), are the shared format of commercial kitchens and derive from a 530 x 325 mm grid ([SVG, Merkblatt Gastro-Norm](https://svg.ch/merkblatt-gastro-norm/)); a GN 1/3 slot takes a third of the long side, 325 x 176 mm ([Gastronorm](https://en.wikipedia.org/wiki/Gastronorm)).

The gap is an open cartridge: a published envelope, a small set of temperature grades, a fill and seal recipe, and a keyed interface, all under an open hardware license.

## Known material problems

- **Salt hydrates** are dense and cheap but supercool, separate into phases over cycling and corrode aluminium and copper ([corrosion study](https://www.researchgate.net/publication/229021530_Corrosive_effects_of_salt_hydrate_phase_change_materials_used_with_aluminium_and_copper); [cycling study](https://www.sciencedirect.com/science/article/abs/pii/S2352152X19315464)).
- **Paraffins** are stable and non-corrosive but combustible, expand by 12.5 to 13 % on melting ([Rubitherm RT 5 HC](https://www.rubitherm.eu/media/products/datasheets/Techdata_-RT5HC_EN_23072026.PDF) and [RT 25 HC](https://www.rubitherm.eu/media/products/datasheets/Techdata_-RT25HC_EN_21012026.PDF) datasheets), and soften or permeate some plastics, including polyethylene ([compatibility of plastics with PCM](https://www.researchgate.net/publication/227717836_Compatibility_of_plastic_with_phase_change_materials_PCM)).
- **Water** is the cheapest store but expands on freezing and sits at 0 °C, which is too cold for vaccines and some produce.

## Constraints

- Garage-buildable prototype, using stock aluminium sections, hand tools, a drill press and a tap set. No custom extrusion, casting, milling or welding for the first build. Value-engineering target: USD 80 for one C5 cartridge and one adapter frame (TCT-DDR-001, D6), a hypothetical control target rather than a limit (Amish, 2026-10-01); the constructable design is estimated at USD 100. Supplier quotes wait with TRL 4 (TCT-DDR-002, O6).
- First host type: a produce cooler used by a trader or smallholder, reached through a local partner (TCT-DDR-001, D7). Decided by Amish on 2026-10-02 (O1): the partner is a postharvest extension partner, and the first candidate to approach is the UC Davis Postharvest Technology Center; nothing is agreed.
- Each paraffin grade has a datasheet maximum operating temperature (C5 45 °C, C25 65 °C, H70 90 °C) that charging and storage must respect.
- Sealed for life in normal use; refillable only by a builder with the fill recipe.
- Safe to carry by hand at any state of charge; no pressure vessel.
- Open design under CERN-OHL-S-2.0, with published fill recipes and grade data.

## Out of scope

- Qualification for vaccines or medicines. A C5 cartridge could support a cold box such as ColdPod, but any medical use needs WHO PQS or equivalent qualification, which is beyond this project.
- High-temperature storage above 90 °C, the limit of the H70 paraffin, for example solar cooking at 200 °C or more. That needs different materials and belongs with ThermaBrick-type designs.
- Active parts: the cartridge has no electronics, heaters or fans. Charging uses existing freezers, ovens, heat stores or host appliances.

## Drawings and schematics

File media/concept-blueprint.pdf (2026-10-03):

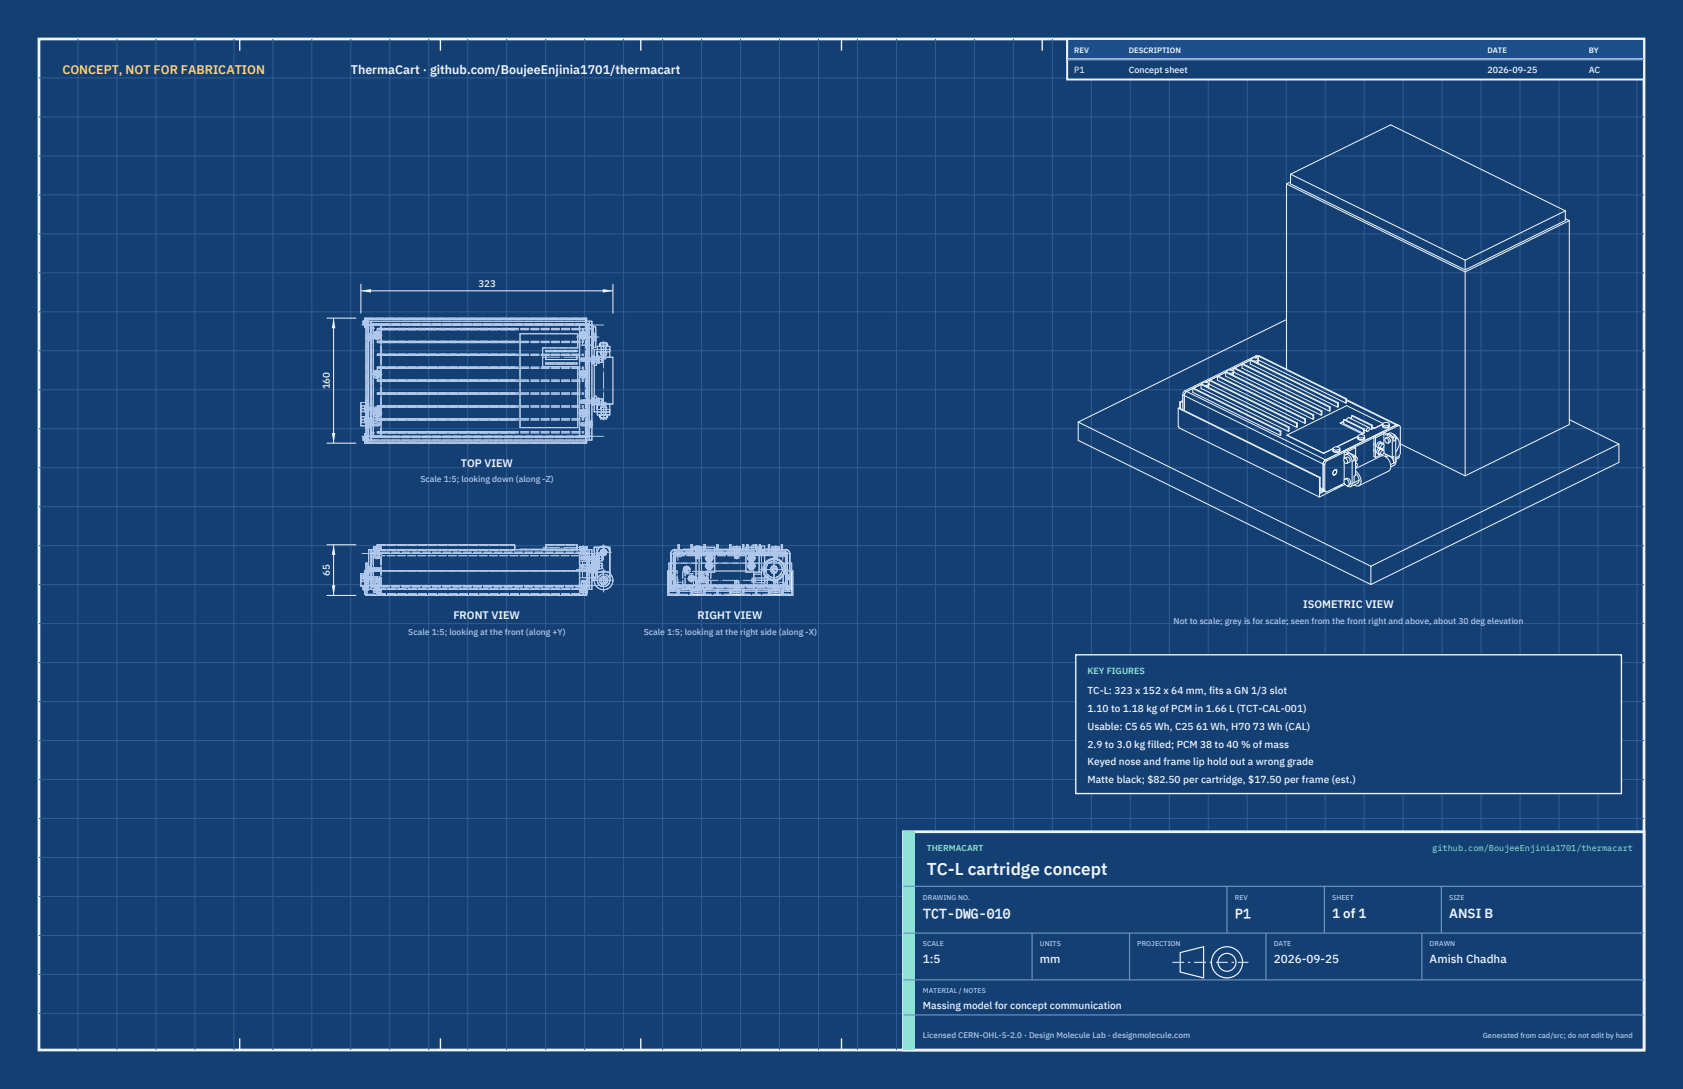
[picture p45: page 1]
CONCEPT, NOT FOR FABRICATION; ThermaCart · github.com/BoujeeEnjinia1701/thermacart; FRONT VIEW; TOP VIEW; RIGHT VIEW; ISOMETRIC VIEW; REV; DESCRIPTION; DATE; Concept sheet; THERMACART; github.com/BoujeeEnjinia1701/thermacart; DRAWING NO. TCT-DWG-010; REV P1; SHEET 1 of 1; SIZE ANSI B; SCALE 1:5; UNITS mm; PROJECTION; DRAWN Amish Chadha; Licensed CERN-OHL-S-2.0 · Design Molecule Lab · designmolecule.com; Generated from cad/src; do not edit by hand

Scale 1:5; looking down (along -Z)

Not to scale; grey is for scale; seen from the front right and above, about 30 deg elevation

Scale 1:5; looking at the front (along +Y)

Scale 1:5; looking at the right side (along -X)

KEY FIGURES
TC-L: 323 x 152 x 64 mm, fits a GN 1/3 slot
1.10 to 1.18 kg of PCM in 1.66 L (TCT-CAL-001)
Usable: C5 65 Wh, C25 61 Wh, H70 73 Wh (CAL)
2.9 to 3.0 kg filled; PCM 38 to 40 % of mass
Keyed nose and frame lip hold out a wrong grade
Matte black; $82.50 per cartridge, $17.50 per frame (est.)

TC-L cartridge concept

MATERIAL / NOTES
Massing model for concept communication

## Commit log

2026-09-25 Initial scaffold: standard open hardware layout, CERN-OHL-S v2 + MIT licenses
    Claude-Session: https://claude.ai/code/session_01XuhhSU4W6fYhgCfURbrkut
    [bom.csv]
2026-09-25 Populate to TRL 2: problem, requirements, precis, concept media, BOM and README use cases
    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
    [bom.csv]
2026-09-26 Advance to TRL 3: DDR-001, CAL-001 sizing, parametric model with STEP/STL, GA drawing, priced BOM; TRL 4 on hold
    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
    [adapter-frame.step, adapter-frame.stl, bom.csv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]
2026-09-26 Accept all recommendations (DDR-002), switch footer to designmolecule.com, add README write-up with new inspiration point
    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
    [adapter-frame.step, bom.csv, end-cap.step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]
2026-09-27 Product appearance model and photoreal renders
    Adds cad/src/product_model.py (appearance model for renders only, all main
    dimensions from model.py) and Blender renders in media/render-*.png,
    captioned with the project, repository and viewing direction. README leads
    with the product render; trl stays 3.
    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
2026-10-01 Image quality pass: legible exploded views, flow diagrams and drawing sheets
    Kit 1.6.1 image layout: the parts list sits in its own column, number bubbles sit on visible parts and never overlap, small parts get a leader, pictures are cropped to the subject, flow labels keep numbers with their units, and sheet captions and the revision table no longer overprint. Concept images, blueprint and general arrangement sheet regenerated; repo-specific labels moved clear of other text and lines.
2026-10-02 Kit 1.7.0: constructable design, illustrated build plan and design decisions register
    The design is now constructable: every part can be made and fits its neighbours, with each change recorded in a Design for construction decision record (made under Amish's 2026-09-30 instruction; ope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
    FlexHand also credits Dr. Geeti Chadha as a contribut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
    [adapter-frame.step, adapter-frame.stl, bom.csv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]
2026-10-02 Record Amish's approval of the open-decision recommendations
    Amish approved the recommendation on every open decision in the design decisions register ("i approve your recommendations for all 555 open decisions.", 2026-10-02). Each decision is moved to Decisio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
2026-10-03 Carry approved follow-ups into the design and redo photoreal renders
    Amish approved the follow-up actions from the open-decision sign-off ("APPROVED CHANGES, COMPLETE THESE", 2026-10-02), the design-for-construction change tables in ten repos, the last wave's open dec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
    [adapter-frame.step, adapter-frame.stl, bom.csv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]

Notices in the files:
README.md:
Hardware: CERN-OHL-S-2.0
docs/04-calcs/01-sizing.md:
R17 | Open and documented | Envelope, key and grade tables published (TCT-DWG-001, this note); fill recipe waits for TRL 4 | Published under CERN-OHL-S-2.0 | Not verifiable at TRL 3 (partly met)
